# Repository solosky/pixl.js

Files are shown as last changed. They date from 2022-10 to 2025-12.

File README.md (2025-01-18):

# Pixl.js

这是一个基于原版[Pixl.js](http://www.espruino.com/Pixl.js)的复刻版本，主要的功能是用来模拟Amiibo。

## 图片

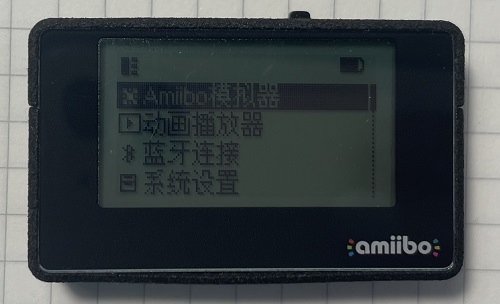
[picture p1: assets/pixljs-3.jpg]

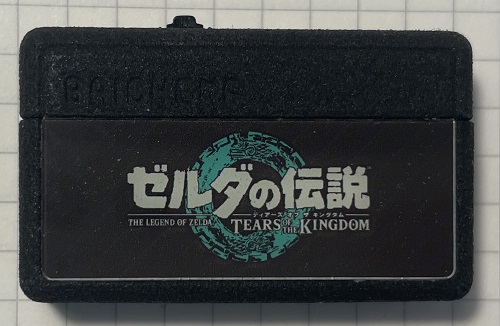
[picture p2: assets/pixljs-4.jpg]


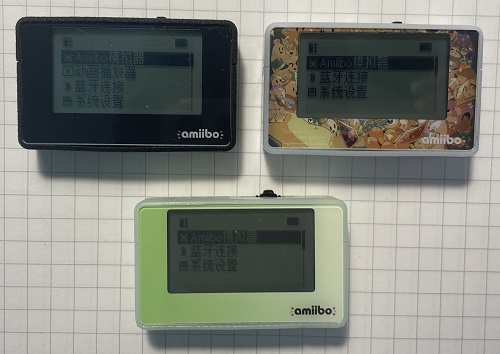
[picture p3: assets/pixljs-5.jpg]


## 文档

* [中文文档](docs/zh/README.md)
* [English Documentation](docs/en/README.md)
* [Italian Documentation](docs/it/README.md)

## Credits

* [FlipperZero Firmware](https://github.com/flipperdevices/flipperzero-firmware)
* [mlib](https://github.com/P-p-H-d/mlib)
* [TLSF](https://github.com/mattconte/tlsf)
* [cwalk](https://github.com/likle/cwalk)
* [SPIFFS](https://github.com/pellepl/spiffs)
* [ChameleonUltra](https://github.com/RfidResearchGroup/ChameleonUltra)
* [CH32V003-GameConsole](https://github.com/wagiminator/CH32V003-GameConsole)

## Contribution 

* 特别感谢 @Caleeeeeeeeeeeee 完善的Bootloader。
* 特别感谢 @白橙 制作的外壳。 
* 特别感谢 @impeeza 提供的文档翻译 。

## 讨论群

国内用户可以加入QQ群 109761876 进行交流。

## Office Channel

Where do you find the community?
* [Pixl.js community discord server](https://discord.gg/4mqeQwcAB2)

## 声明

本项目为开源项目，仅为学习研究用途，请勿用于商业用途。 <br />
Amiibo是任天堂的注册商标，NTAG21X为NXP的注册商标。

内置的Amiibo数据库来源分别如下：

* [amiiloop](https://download.amiloop.app/)
* [AmiiboAPI](https://www.amiiboapi.com/)

源代码没有包含任何有任天堂版权的资源（比如相关密钥，Amiibo原始数据等）。

# License

本项目基于GPL 2.0 License发布，使用请遵循License的约定。

* 如果对项目做了修改，需要把改后的源码发布出来
* 发布出来的源码必须要使用相同的License发布

## 提示 

Amiibo无限刷需要网上搜索key_retail.bin文件然后上传到到磁盘根目录后才能使用。

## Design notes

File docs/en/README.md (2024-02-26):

# **Welcome to the pixl.js project documentation !**

The pixl.jx project is a forked version of the original [Pixl.js](http://www.espruino.com/Pixl.js). The main focus of this fork is to simulate Amiibo.

This fork is divided in two main sections, Hardware and Firmware

# [Hardware](01-Hardware.md)

- [PCB](01-Hardware.md#PCB)
- [BOM](01-Hardware.md#BOM)
- [Pictures](01-Hardware.md#Pictures)
- [Demo](01-Hardware.md#Demo)
- [Shell](01-Hardware.md#Shell)
- [OLED version](01-Hardware.md#OLED-version) 

# Firmware 

- A guide to [Flash the Firmware](02-Flash-Firmware.md "Flash the Firmware")
- To help on the internationalization of the Firmware you can follow the [Guide](05+5-translation.md).
- [Building the firmware](03-Build-Firmware.md)
- [Using the firmware](04-Using-Firmware.md)

# [User Manual](04-Using-Firmware.md)

- [Concepts](04-Using-Firmware.md/#Firmware-Concepts)
- [Amiibo Emulator App](04-Using-Firmware.md/#Amiibo-Emulator)
- [Amiibo Database App](04-Using-Firmware.md/#Amiibo-Database)
- [AmiiboLink Emulator APP](04-Using-Firmware.md/#AmiiboLink)
- [Card Emulator APP](04-Using-Firmware.md/#CardEmulator)
- [BLE File Transfer APP](04-Using-Firmware.md/#BLE-File-Transfer)
- [Settings APP](04-Using-Firmware.md/#Settings-1)

# Technical Documentation

- [Bluetooth BLE File Transfer protocol](05+1-ble_protocol.md)
- [AmiiboLink BLE Protocol](05+2-amiibolink_ble.md)
- [video player](05+4-video_player.md) (Retired on Firmware 2.5.2 due to flash size restrictions)

# Tutorial

## iNFC

- [Pixl Firmware Upgrade Tutorial](https://www.youtube.com/watch?v=vldNVaoqJg0)

## MTools Lite

- [How to use card emulator on Pixl js OLED LCD](https://www.youtube.com/watch?v=KiuyfBKalhI)

# **key_retail.bin**

In order to use some features of the firmware you must to provide the «key_retail.bin» file. It should be uploaded to the root directory of the device storage before it can be used. You need to provide a legally acquired one, you can use a tool to extract it from your console (3DS or Switch).

>**key_retail.bin checksums:** <br/>
>MD5:	45fd53569f5765eef9c337bd5172f937 <br/>
>SHA1:	bbdbb49a917d14f7a997d327ba40d40c39e606ce<br/>

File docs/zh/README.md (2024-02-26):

# **Pixl.js文档**

# [硬件](01-Hardware.md)

- [PCB](01-Hardware.md#PCB)
- [BOM](01-Hardware.md#BOM)
- [图片](01-Hardware.md#Pictures)
- [演示](01-Hardware.md#Demo)
- [外壳](01-Hardware.md#Shell)
- [OLED版本](01-Hardware.md#OLED-version) 

# 固件

- [固件](02-Flash-Firmware.md "Flash the Firmware")
- [国际化](05+5-translation.md)
- [构建固件](03-Build-Firmware.md)

# [使用手册](04-Using-Firmware.md)

- [概念](04-Using-Firmware.md/#概念)
- [Amiibo模拟器](04-Using-Firmware.md/#Amiibo模拟器)
- [Amiibo数据库](04-Using-Firmware.md/#Amiibo数据库)
- [AmiiboLink](04-Using-Firmware.md/#AmiiboLink)
- [卡模拟器](04-Using-Firmware.md/#卡模拟器)
- [蓝牙传输](04-Using-Firmware.md/#蓝牙传输)
- [设置](04-Using-Firmware.md/#设置)

# 外壳

TODO

# 技术文档

- [蓝牙协议](05+1-ble_protocol.md)
- [AmiiboLink蓝牙协议](05+2-amiibolink_ble.md)
- [视频播放器](05+4-video_player.md) (由于固件大小限制，从固件版本2.6.2起，此功能已从固件中删除)

# key_retail.bin

为了使用固件的一些功能，您必须提供`key_retail.bin`文件，应在设备存储的根目录中上传，然后才能使用。 <br/>
您需要提供一个合法获得的文件，您可以使用工具从您的控制台（3DS 或 Switch）中提取它

>**key_retail.bin checksums:** <br/>
>MD5:	45fd53569f5765eef9c337bd5172f937 <br/>
>SHA1:	bbdbb49a917d14f7a997d327ba40d40c39e606ce

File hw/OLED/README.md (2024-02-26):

# OLED Version 

OLED version is contributed by @xiaohail under GPL 2.0 License, you can download hardware [here](https://gitlab.com/xiaohai/pixl.js)

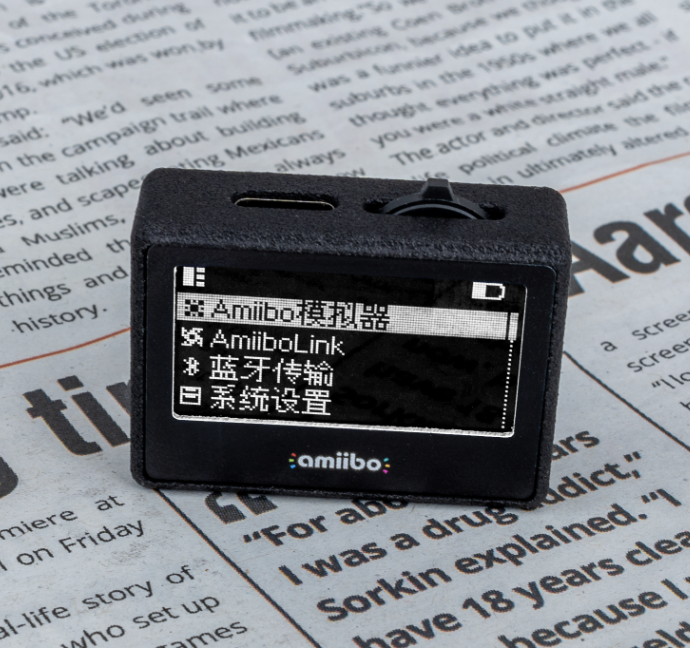
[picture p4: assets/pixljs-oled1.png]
OLED


## Improvement 

* Powered by lithium battery/USB power supply
* Supports OLED screen, LCD screen
* Hall sensor restart mechanism

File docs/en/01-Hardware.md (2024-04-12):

# PCB
The pixl.js hardware is developed and maintained on the repository, you can access the latest version of the hardware on [Hardware section of the GitHub repo.](https://github.com/solosky/pixl.js/tree/main/hw "Hardware section of the GitHub repo.")

hw/RevC is the latest PCB version, its recommended to use it.
You can use [Kicad 6](https://www.kicad.org/download/) to open and edit the PCB and Schematic files.

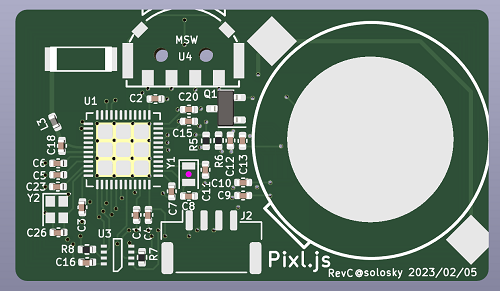
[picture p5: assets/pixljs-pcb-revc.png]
pixl.js PCB


# BOM
* The BoM is summaried on the doc: [RevC Bill of Materials Buying Guide](01+1-RevC-bom.md)
* The Bill of Materials in interactive format are also available, you can download it from: [RevC InteractiveHtmlBom](https://github.com/solosky/pixl.js/blob/main/docs/RevC-ibom.html)

# Pictures
Some pictures of current devices are:

pixl.js 1
pixl.js 2
pixl.js 3

# Demo

[The latest version of the Amiibo Emulator APP can generate random UUIDs allowing unlimited amiibo readings on game! This video is a example](https://www.bilibili.com/video/BV1TD4y1t76A/)

# Shell

A shell for this project, made by Mr. Baicheng can be downloaded [here](https://www.thingiverse.com/thing:5877482)
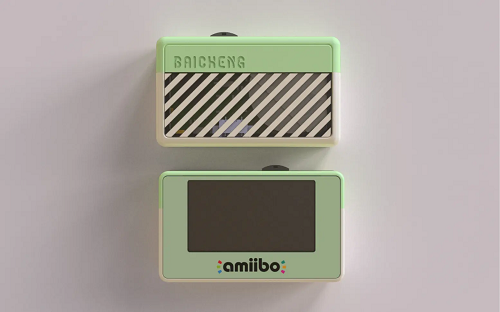
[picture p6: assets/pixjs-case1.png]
SHELL


# OLED version

The OLED version was contributed by netizen @xiaohail. You can click [here](https://gitlab.com/xiaohai/pixl.js) to download the PCB.

OLED

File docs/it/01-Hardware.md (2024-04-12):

# PCB
L'hardware di pixl.js è sviluppato e mantenuto nel repository, puoi accedere alla versione più recente dell'hardware nella [sezione Hardware del repository GitHub.](https://github.com/solosky/pixl.js/tree/main/hw "Sezione Hardware del repository GitHub.")

hw/RevC è la versione più recente del PCB, si consiglia di utilizzarla.
Puoi usare [Kicad 6](https://www.kicad.org/download/) per aprire e modificare i file del PCB e dello schema.

PCB pixl.js

# BOM
* Il BOM è riassunto nel documento: [Guida all'acquisto dei materiali di RevC](01+1-RevC-bom)
* La lista dei materiali  in formato interattivo sono disponibili, puoi scaricarli da: [RevC InteractiveHtmlBom](docs/RevC-ibom.html)

# Immagini
Alcune immagini dei dispositivi attuali sono:

pixl.js 1
pixl.js 2
pixl.js 3

# Demo

[L'ultima versione dell'applicazione Emulatore Amiibo può generare UUID casuali permettendo letture illimitate di amiibo sul gioco! Questo video è un esempio](https://www.bilibili.com/video/BV1TD4y1t76A/)

# Custodia

Una custodia per questo progetto, realizzata dal signor Baicheng, può essere scaricata [qui](https://www.thingiverse.com/thing:5877482)
CUSTODIA

# Versione OLED

La versione OLED è stata contribuita dall'utente @xiaohail. Puoi cliccare [qui](https://gitlab.com/xiaohai/pixl.js) per scaricare il PCB.

OLED

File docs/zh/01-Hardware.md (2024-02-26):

# PCB

hw/RevC 路径为最新的PCB版本，建议使用。您可以使用 [Kicad 6](https://www.kicad.org/download/) 打开和编辑PCB和原理图文件。

pixl.js PCB

# BOM
* 这里是已完成的BOM表: [RevC Bill of Materials Buying Guide](01+1-RevC-bom)
* 这里提供了交互格式的物料清单，您可以从此处下载： [RevC InteractiveHtmlBom](docs/RevC-ibom.html)

# 图片
以下为设备目前的一些图片:

pixl.js 1
pixl.js 2
pixl.js 3

# Demo

[以下视频介绍了Amiibo模拟器应用的最新版本，该功能可以生成随机UUID，允许在游戏中无限读取amiibo！](https://www.bilibili.com/video/BV1TD4y1t76A/)

# 外壳

你可以从 [这里](https://www.thingiverse.com/thing:5877482) 下载由@白橙 为此项目制作的外壳
shell

# OLED version

OLED版本由网友@xiaohail贡献。您可以点击 [这里](https://gitlab.com/xiaohai/pixl.js) 下载 PCB.

OLED

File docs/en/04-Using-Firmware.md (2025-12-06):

# Firmware Concepts
## Amiibo
Is a device sell by Nintendo, normally in form of a figurine, but also there are cards, wrist straps and others.

Each amiibo have a NFC tag embedded on the figurine base. The NFC tag have some data pre-record at factory identifying the type of figurine and making each amiibo unique of others.  The main data of the amiibo are:

As stated by Nintendo Amiibo is singular and plural (https://twitter.com/NintendoAmerica/status/535485751635763200)

## Model Info
Is a number which describe the amiibo series, game series, character and character variation, this info cannot be changed after first programming.

## UID
Is the serial number of the figurine is also hardcoded at factory making each amiibo unique.

## Amiibo Data
This section of the data on the tag store the user modifiable information like the Owner and Nickname registration or savegame data.

## UUID
The term UUID is used on the mod scene to reference the UID send to the game by a amiibo emulator, as the game uses the UID to know if a amiibo was already used; if the emulator changes the UID, the emulated amiibo looks like a completely different amiibo to the game, allowing to use that amiibo again.

## key_retail.bin
It's a binary file containing Nintendo private keys to encrypt amiibo, is copyrighted material so you need provide a legal acquired one, you can dump it form a 3DS or Switch Console.

## .BIN file
The data of an amiibo can be dumped to a file, that binary dump of the original content of an amiibo is stored on a file with `.BIN` extension, that dumps are uploaded to the device for the Amiibo Emulator application or the AmiiboLink Emulator application.  You need to provide a legally acquired binary dump file.

## Thumbwheel slide dial switch
Is the micro switch at top of the device, is a device having three buttons in one, a central one, and two sides.  Rocking the micro switch to sides you push that "**side**" buttons.  Pushing the micro switch you push the "**middle**" button.

On this document pressing the sides of Thumbwheel is named "**side buttons**", pushing the Thumbwheel is called "**middle button**"; to navigate items on a menu you use the side buttons, to select an item you press middle button.

# Using the Firmware
The Pixl.js firmware Main Screen is divided on several Applications, each one can be run to execute some actions, the applications on main screen are:

|   |
| ------------ |
|  Amiibo Emulator<br> Amiibo Database<br>֍ AmiiboLink<br>ᛡᛒ  BLE File Transfer<br> Settings |
|   |

----
# Amiibo Emulator
This application allows you to browse local storage for .BIN files and use them as the current amiibo.

You can browse folders and files using the thumbwheel slide dial switch, pushing to the sides you change elements, pushing the middle button you select the highlighted element.

Once you select a .BIN file his data is used like the current amiibo, the screen shows current amiibo details like amiibo current UUID, filename and amiibo name.

## Amiibo details screen
You can use side buttons to change the current amiibo with the next or previous one on the current folder.  
If the amiibo file is marked as read-only, an info icon will be displayed in front of the amiiboe file name line.

## Amiibo detail menu
Pressing the middle button you can change the behavior of the current amiibo, on the sub menu:

|   |
| ------------ |
| Rand. Tag<BR>Auto Rand.<BR>Delete Tag<BR>Back to Tag Details<BR>Back to File List<BR>Back to Main Menu<BR>Rand. Tag |
|   |

### Randomize Tag.
Changes the current UUID presented to game to current amiibo. The new UUID stays in place until you change the current amiibo or select this option again.
### Auto Rand. (Automatic Random)
Turning ON this feature, will generate a new random UUID for the current amiibo each time a game read it.  Allowing to use the same amiibo multiple times on games with restrictions.
### Read-only
Turning on this feature, any write operation to this tag will be denied. 
### Delete Tag
Delete the file associated to current amiibo.
### Back to Tag Details
Returns to the details of the current amiibo.
### Back to File List
Returns to the file list of current folder.
### Back to Main Menu
Exit the amiibo emulator application.

_If you enable UUID random generation, manually or automatic the original UUID of the .BIN file is used the next time that file is loaded._

## File explorer.
If you have **highlighted a folder or a file** and you press and hold the middle button for 1 second a properties sub menu is open:

|   |
| ------------ |
| Create New Folder…<BR>Create New Tag…<BR>Rename…<BR>Delete...<BR>Back to File List<BR>Back to Main Menu |
|   |

### Create New Folder…
Dialog to create a new sub folder on current one.
### Create New Tag…
Creates a blank amiibo .BIN file on the current folder.  That .BIN file is now a simil of a New Ntag215, ready to be programmed, you can assign that .BIN file as current amiibo and using a NFC programmer you can write the amiibo data, by example you can use iNFC or Tagmo for phones, Thenaya for the 3DS.  If the programmed amiibo is on the database the .BIN file is even renamed to the name of the amiibo.
### Rename…
Dialog to rename highlighted .BIN file or folder
### Delete…
Remove highlighted object, asking for confirmation.  If is a folder, all subfolders and files are deleted too.
### Back to File List
Returns to the file list of current folder.
### Back to Main Menu
Exit the amiibo emulator application.

----
# Amiibo Database
This application allows the emulation of amiibo from the list of well know ones, using legally available information like the model info, then when you select one, a new virtual amiibo is created on memory using a random UUID.  In order to use this application you must to provide your «key_retail.bin» file.

_Each time one an amiibo is used the initial UUID is random generated._

Once you open the application the main menu have the options

|   |
| ------------ |
| Browser…<BR>Search…<BR>My Favorites…<BR>My Amiibo…<BR>Settings… |
|   |

## Browser… 
Let you browse the database, first by category, then all amiibo on that category.
After you select an amiibo, the details are shown, the first line contains the actual UUID and second line the amiibo name.

On the amiibo details page you can use the side buttons to navigate through all the amiibo on the category, if you press the middle button you can change the behavior of the current amiibo, with the sub menu:

|   |
| ------------ |
| Rand. Tag<BR>Auto Rand.<BR>Favorite…<BR>Save As…<BR>[Back to Details]<BR>[Back to List]<BR>[Exit] |
|   |

### Rand. Tag
Randomize Tag, changes the current UUID presented to game to current amiibo. The new UUID stays in place until you change the current amiibo or select this option again.
### Auto Rand.
Automatic Random, Turning ON this feature, will generate a new random UUID for the current amiibo each time a game reads it.  Allowing to use the same amiibo multiple times on games with restrictions.
### Favorite…
Open a new submenu to manage Favorite folders.  You have the options:

```
New…
Folder1
Folder2
[Back]
```

**New…** allows you to create a new Favorites folder, **Back** go back to current amiibo details, if you select an existing folder, that amiibo definition will be added to selected folder.

### Save As…
Allows you to assign the current amiibo to one of the «My Amiibo» slots.
### [Back to Details]
Returns to the details of the current amiibo.
### [Back to List]
Returns to the amiibo list of current category.
### [Exit]
Exit the Amiibo Database application.

## Search…
Allows to search the database using partial name, the search result is like a category, you can select any amiibo on it and set it like another one.

## My Favorites…
Display the existent favorites folders, you can browse them with side buttons and select one with middle button.  If you press and Hold the middle button a sub menu is open:

|   |
| ------------ |
| New…<BR>Empty…<BR>Delete…<BR>[Back] |
|   |

### New…
Allows you to create a new favorites folder.
### Empty…
After confirmation, removes all amiibo associated to the selected folder.
### Delete…
After confirmation, removes the favorite folder.
### [Back]
Returns to Folder list.

Once you select a folder a list of the associated amiibo to that favorite folder is shown, you can browse using side buttons and select an amiibo with middle button, the selected amiibo becomes the current one, and behave like an amiibo of the browser.

## My Amiibo…
List the configured slots, you can browse the slots using side buttons, select one with middle button and the amiibo associated to that slot becomes the current one.

If you press and hold middle button a sub menu with the option of reset the slot is shown allowing to empty the slot.

If you turn on the Read-only feature, the current amiibo slot will denied write operation to this slot. An info icon will be displayed in front of the amiibo name if read-only feature is enabled.

## Settings…
The settings menu show you the Keys status and number of slot set up.

|   |
| ------------ |
| Keys []<BR>Slot Num. []<BR>[Back] |
|   |

### Keys []
Show the status of the «key_retail.bin» file, can be «Loaded» or «NOT Loaded»
### Slot Num. []
Allows to select how many slots are available to «My Amiibo» section, values from 10 to 50 on tenths increments.
### [Back]
Exit the Amiibo Database and returns to Main Menu.

----
# AmiiboLink
This application emulates an AmiiboLink (AmiLoop or omllbolink) device.

These devices are generic espruino boards sell on different forms, normally are Keychains drop shaped, but also there are some Puck or Sheika Slate shaped.

Almost all have a button and some LEDs as indicators and runs from CR2032 cell batteries or lipo cells.

All of them are controlled from phone applications via Bluetooth, also you can upload one or several .BIN amiibo files using the phone to the device.

Starting this application the details for current amiibo are shown.  If you are on sequential mode you can use the side buttons to walk through all the uploaded amiibo, in all modes, you can press the middle button to open the AmiiboLink APP config sub menu, the menu have this items:

|   |
| ------------ |
| Mode []<BR>Auto Random. []<BR>Compati. Mode []<BR>Tag Details<BR>[Main Menu] |
|   |

## Mode []
Shows the actual operation mode, when selected you can choose the mode of amiibo working, the available modes are:
- ### Randomize (Manual)
On the actual AmiiboLink device the current amiibo changes the UUID when you press the device button
- ### Randomize (Auto)
A new random UUID for the current amiibo is generated after each time a game read it.  Allowing to use the same amiibo multiple times on games with restrictions. You cannot change the active amiibo on this mode.
- ### Sequential mode
On this mode you can change the actual amiibo using the side buttons, rolling through all amiibo uploaded with the phone app. All uploaded .BIN files are stored on the 01.bin to 26.bin files at the /amiibolink/ folder.
- ### Read-write mode
The device use a "special" amiibo slot where only an amiibo can be used, the amiibo can be replaced by another .BIN file from the phone app. On the local storage this amiibo is saved with at the /amiibolink/99.bin file.

Changing the mode preserve the current selected amiibo, with exception of «Read-write mode».

## Compati. Mode []
Shows the emulation firmware mode, the supported values are V1, V2 and AmiLoop, there are several APPs each one designed for a AmiiboLink firmware version or to the AmiLoop protocol.  Using this setting you can match the emulation with the protocol needed by the APP you use on your phone.
## Tag Details
Return to amiibo details page
## [Main Menu]
Exit the AmiiboLink Emulator application.

## AmiiboLink Compatible Applications
So far the only two AmiiboLink/AmiLoop mode manager phone Apps are translated to English, they are "Umiibo" and "AmiLoop" this applications are compatible only with the AmiLoop Mode.

Other oddity is what the modes on applications do not correspond with the modes set up on the device.

| Umiibo APP | Pixl.js Emulation Mode |
| --- |--- |
| Manual Mode | Random automatic |
| File Mode | Sequential |
| Auto Mode | Read/Write |

| AmiiLoop APP | Pixl.js Emulation Mode |
| --- |--- |
| Manual Mode | Random automatic |
| File Mode | Sequential |
| Auto Mode | Read/Write |

# Card Emulator

This application can be used to emulate Mifare cards and NTAG series cards.

Mifare cards are commonly used for access control cards, and the device can fully emulate Mifare types of cards. Supported Mifare card types include:

* Mifare Mini
* Mifare 1K
* Mifare 2K
* Mifare 4K

NTAG series cards are commonly used for device identification. Supported NTAG card types include:

* NTAG 210
* NTAG 212
* NTAG 213
* NTAG 215
* NTAG 216
* Mifire Ultralight C
* Mifire Ultralight C
* Mifire Ultralight EV1(640 bits)
* Mifire Ultralight EV1(1312 bits)

Currently, a total of 8 cards are supported, with the option for customizing the number of cards in the future.

> Note:<br/>
> The emulation function of the NTAG series is still in testing, and the functionality is not yet complete. It does not fully emulate > the features of NTAG125. <br/>
> Further improvements to this part of the functionality will continue.

Emulation can only be activated in this interface, and it will be deactivated if you leave this interface.

After disk formatting or the first entry into the card emulator, data will be initialized. This process may take a few seconds, so please be patient.

## Card Emulation

The interface of the card emulation page is as follows:

|   |
| ------------ |
| [01] de:ad:be:ef|
|  |
| <    Slot 01      >|
|  |
| MF 1K <08/04 00>  |
|   |

The interface is explained as follows:

* The first line: `01` is the card number, and `de:ad:be:ef` is the card ID.
* The second line: Slot 01 is the name of the current card, which can be freely set.
* The third line: `MF 1K` displays the card type. The type abbreviations are shown in the table below. `08` is the card's SAK, `04 00` is the card's ATQA. The last symbol indicates the writing mode. If it is marked as a disk, writing is allowed; otherwise, writing is not allowed.
Abbreviations for card types:

| Display Name | Card Type | Data File Size |
| ---- | --- | --- |
| MF mini | Mifare Mini | 320 |
| MF 1k | Mifare 1K | 1024 |
| MF 2k | Mifare 2K | 2048 |
| MF 4k | Mifare 4K | 4096 |
| N210 | NTAG 210 | 80 |
| N212 | NTAG 212 | 164 |
| N213 | NTAG 213 | 180 |
| N215 | NTAG 215 | 540 |
| N216 | NTAG 216 | 924 |
| MFUL | Mifare Ultralight | 64 |
| MFULC | Mifare Ultralight C | 144 |
| MFEV11 | Mifare Ultralight EV1(640 bits) | 80 |
| MFEV21 | Mifare Ultralight EV1(1312 bits) | 164 |

* It will display a fav icon if the card is default card. The default card is the card that is automatically activated when the device is wakeup by NFC field presents.

# Main Menu

Pressing the middle button allows you to enter the main menu. As follows:

|   |
| ------------ |
|  Slot  [01]|
|  Nick [Slot 01]|
|  ID [de:ad:be:ef]|
|  Type [MiFare 1K] |
|  Data.. |
|  Advanced.. |
|  Slot Settings.. |
|  [Tag Details] |
|  [Main Menu] |
|   |

* Slot: Displays the current selected card slot. You can select a card slot by pressing the middle button.
* Nick: The current name of the card. Pressing the middle button can enter the card name setting interface.
* ID: Displays the current card ID.
* Type: Displays the current card type.
* Default Card: if enabled, the card will be automatically activated when the device is wakeup by NFC field presents. 
* Data: Pressing the middle button can manage card data.
* Advanced: Pressing the middle button can enter advanced card settings.
* Slot Settings: Pressing the middle button enters the slot management interface, where you can enable or disable card slots.
* [Tag Details]: Returns to the tag details page.
* [Main Menu]: Exits this application and enters the main menu.

> **Special Note:**：<br/>
> Some modifications need to be saved to storage when exiting to the tag details. If you have modified some configurations, be sure to enter the tag details page to save them.
> The default card feature is conflict with Fast Resume. If the default card feature is enabled, the device will active the card emulator of the default card instead of the amiibo Fast Resume feature.

## Nick Update

In this interface, you can modify the name of the card.

Due to limited display space, only English characters can be entered.

In particular, if using Chinese characters, due to UTF-8 encoding, deletion requires at least 2 presses to completely delete.

If you want to add Chinese notes to the card, you can modify the notes of `/chameleon/slots/00.bin` through the webpage to achieve Chinese notes.<br />
00.bin is the file for the first card slot, 01.bin is the file for the second card slot, and so on.

> Due to firmware size limitations, currently only around 1000 Chinese characters can be displayed properly. If Chinese characters are not displayed, please raise an issue with the characters you need to display. Specific characters can be added in the next version.

## Card Data

In this interface, you can perform the import and export of card data.

|   |
| ------------ |
|  Load.. |
|  Save.. |
|  Factory.. |
|   |

The import and export files are stored in the `/chameleon/dump/` folder.<br />
If you need to import data, you need to write the data file you want to import to the above folder through the webpage in advance.

* Load: Pressing the middle button allows you to enter the load interface. The interface will read all files under `/chameleon/dump/`, and pressing the middle button can perform the import.
* Save: Pressing the middle button allows you to export the current card to the `/chameleon/dump/` folder.
* Factory: Pressing the middle button allows you to reset the current card data to the default built-in empty card data.

> The file size loaded must be exactly the same as the current card type to be imported. The data file size for different cards refers to the table in the `Card Emulation`.

## Advanced

This interface displays different content based on MiFare series cards and NTAG series cards.

> **Special Note**:<br/>
> This interface is the advanced settings for card emulation, and it is not recommended for ordinary users to modify. If you intend to make changes, please make sure you understand what you are doing before modifying!<br/>
> If modifying this part leads to card emulation failure, try restoring default settings first.

### MiFare Series
|   |
| ------------ |
|  Custom Mode [OFF] |
|  ID [de:ad:be:ef]|
|  SAK [08] |
|  ATQA: [00 40]|
|  Gen1A Enabled [OFF] |
|  Gen2 Enabled [OFF] |
|  Write Mode [Normal] |
|  [RETURN] |
|   |

* Custom Mode: Default is off. Off: During the ID card recognition phase, ID/SAK/ATQA are read from sector 0 of the card data. On: You can set independent resources in the ID/SAK/ATQA menu below.
* ID: Displays the current card ID. If the custom mode is on, pressing the middle button allows you to enter the input interface for modification. If the custom mode is off, pressing the middle button has no effect.
* SAK: Displays the current card SAK. If the custom mode is on, pressing the middle button allows you to enter the input interface for modification. If the custom mode is off, pressing the middle button has no effect.
* ATQA: Displays the current card ATQA. If the custom mode is on, pressing the middle button allows you to enter the input interface for modification. If the custom mode is off, pressing the middle button has no effect.
* Gen1A Enabled: Default is off. When enabled, allows the emulator to respond to domestic advanced backdoor commands. These backdoor commands can directly unlock the card without the need for a key.
* Gen2 Enabled: Default is off. When enabled, allows writing to sector 0. (Sector 0 mainly stores information such as ID/SAK/ATQA, and allowing writing can modify the card's ID)
* Write Mode: Default is normal. There can be 4 values, see the table below.

|  Write Mode | Description |
| ----- | --- |
| Nromal | Data is written normally to memory, switch card or exit to persist |
| Deny | Any write operation returns failure |
| Ingore | Write operation returns success, but does not write to memory or persist |
| Cache | Data is written normally to memory, switching cards or exiting does not persist |

> It is recommended to enable Gen1A mode and Gen2 mode when copying cards, and close them after copying to avoid being recognized as a clone card by card readers.

### NTAG Series
|   |
| ------------ |
|  ID [04:68:95:71:fa:5c:64]|
|  SAK [00] |
|  ATQA: [00 44] |
|  Rand. UID |
|  [RETURN] |
|   |

* ID: Displays the current card ID. Not editable.
* SAK: Displays the current card SAK. Not editable.
* ATQA: Displays the current card ATQA. Not editable.
* Rand. UID: Pressing the middle button can randomly generate a new ID. Note that you need to return to the emulation interface to simulate and save the new card ID.

## Slot Settings

This interface displays the enable/disable status of all card slots and allows you to individually enable or disable each card slot.

|   |
| ------------ |
|  Slot Num.. [8]|
|  Slot 01   [ON] |
|  Slot 02   [OFF] |
|  .. |
|  [RETURN] |
|   |

* Slot Num: Displays the current number of card slots, which is default set to 8. Currently, the modification of the slot quantity is not supported, and it will be available in future firmware updates.
* Slot xx: Displays the open/close status of the card slot. Pressing the middle button can toggle between open and close status.

----
# Game
The device has 4 games that ported from https://github.com/wagiminator/CH32V003-GameConsole.
The 4 games are:

* Tiny Invaders
* Tiny Lander
* Tiny Tris
* Tiny Arkanoid

Long press center key to exit the game.

For more information about the games, please visit the [https://github.com/wagiminator/CH32V003-GameConsole](https://github.com/wagiminator/CH32V003-GameConsole "https://github.com/wagiminator/CH32V003-GameConsole.").

----
# BLE File Transfer
This application allows you to connect the iNFC or the pixl.js web page, to manage files on the device storage or update the firmware.

The official web page is [https://pixl.amiibo.xyz/](https://pixl.amiibo.xyz/ "https://pixl.amiibo.xyz/.").

The **iNFC APP** is a third party APP

Entering this mode the Bluetooth MAC address of device and official URL are shown at the screen.

----
# Settings
This application allows to configure the device working settings, the application have the next items on the menu:

|   |
| ------------ |
| Version []<BR>Language []<BR>Auto Storage []<BR>Backlight / OLED Contrast []<BR>Menu Animation []<BR>LiPO Battery []<BR>Memory Used []<BR>Fast Resume []<BR>Sleep Timer []<BR>Firmware Update<BR>System Reboot |
|   |

## Version
This submenu shows the version details of the firmware.
- Version
- Build date
- Githash
- Branch
- Target
- Dirty
## Language
You can change the language displayed on the device
## External Storage
You could view the external storage status and usage here, enter this menu could view the external storage usage details and perform format operation.
## Backlight / Contrast
With this setting you can control the brightness of the LCD screen or the contrast of the OLED screen.
## Menu Animation
Enable / disable the animation of items larger than screen allowing to read them completely, enabling this option increase the battery consumption.
## LiPO Battery
Enable the use of a LiPO battery.  It requires an hardware mod. If you build a LiPO version of Pixl.js device, you can enable this option. For CR2032 version, this option will not work and should not be enabled.

If you enable LiPO option, the device will use LiPO voltage level to display the battery level, and also can display a charge label when the battery is in charge mode.
## Memory Used
Shows the % used storage memory at the bottom of the screen
## Fast Wakeup
Enables hibernation of device, allowing a quicker response of the reading of the current amiibo by a game, and resume to the application open at the moment of sleep, when disabled the resume after sleep takes 1 second more and the device restore to the Main Menu.
## Sleep Timeout
Set the time when the device go to sleep after the last user input or amiibo read.
## App Management
Disable or enable app that shows on the Main Menu.
## Go Sleep
Manually put the device to sleep mode.
## Firmware Update
This option put the device in the DFU mode, allowing OTA firmware update, you can update the firmware using the iNFC or the web page.

You can go to the URL [https://thegecko.github.io/web-bluetooth-dfu/](https://thegecko.github.io/web-bluetooth-dfu/) to upload the firmware, this page also can be open through the official site [https://pixl.amiibo.xyz/](https://pixl.amiibo.xyz/)
## System Reboot
Allows you to reboot the device and get back to the state after you remove and put the battery.

## Reset Default Settings
Reset all settings to default values.

## About Device
Show Pixl.js project information, include source code repository, license.

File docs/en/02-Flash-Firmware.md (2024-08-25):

After you build the hardware you need to flash the firmware for the first time, that can only be achieved via wired method

The firmware can be flashed or upgraded using one of the follow methods:

## Method 1: Wired
This method requires a CMASS-DAP compatible JLink or DAPLink flasher.  We recommend PWLINK2 Lite Emulator STM32 Programmer, you can buy one for about 9.9 yuan on [Taobao](https://item.taobao.com/item.htm?spm=a1z09.2.0.0.4b942e8deXyaQO&id=675067753017&_u=d2p75qfn774a "Taobao")

Download the latest version of the firmware zip package. It should contain next files:
- fw_update.bat
- bootloader.hex
- pixljs.hex
- pixljs_all.hex
- fw_readme.txt
- pixjs_ota_v237.zip

You need to connect the 3.3 Volt, GND, SWDIO and SWDCLK leads.  you can use the file  `fw_update.bat` to flash the `pixjs_all.hex` firmware.

You can also use OpenOCD to flash the device, this is an example of the command to execute:
```
openocd -f interface/cmsis-dap.cfg -c "transport select swd" -f target/nrf52.cfg -d2 -c init -c "reset init" -c halt -c "nrf5 mass_erase" -c "program pixjs_all.hex verify" -c "program nrf52832_xxaa.hex verify" -c exit
```
After first flash is completed, subsequent firmware updates can be done via OTA.

## Method 2: OTA update
This method is only applicable to Pixl.js devices that have been successfully programed via wired method.

### nRF Connect APP
Install the nRF Connect application (you can find it on the both iOS and Android app stores).

On the Devices List, select pixl.js (or pixl dfu) and tap the button `CONNECT`

Put your pixl.js device on "Firmware Update" mode, then the device will enter DFU mode.  To do so, select the `Settings` app and select the item `Firmware Update`.

Open "nRF Connect" app on your phone and connect to the device named `pixl dfu` to update the firmware.

On iOS, The firmware is `pixjs_ota_vxxx.zip` in the compressed package and needs to be shared with the nrfconnect application through WeChat or QQ.

On Android you can use the DFU icon on the upper right of the screen, Select the `Distribution packet (ZIP)` option and browse your storage for the `pixjs_ota_vxxx.zip` file.

### Web page method
Download the latest version of the firmware zip package correspondent to your device version, and extract it to a directory.

The project provide two ways to achive a DFU update:

#### File Transfer Web Page.
First you can connect the device to [official web page](https://pixl.amiibo.xyz/ "official web page") then on the web page, after the device is connected, press the `DFU` grey button, the device will enter on the DFU mode and the page ask you "Do you want to open the DFU upgrade page?" if you accept the Firmware Update Page will be open.

#### Directly to the Firmware Update Page.
Also you can go directly to the Firmware Update Page.

First you need to put your pixl.js device on "Firmware Update" mode.  To do so, select the `Settings` app and select the item `Firmware Update`.

Open the [firmware update page](https://thegecko.github.io/web-bluetooth-dfu).  Drag and drop or select `pixljs_ota_xxx.zip` file from the folder where you extract the firmware package.

Then press the `SELECT DEVICE` button on the page you should see a device called `pixl dfu` connect to start the firmware upgrade process.

# Repair wrong firmware version.

If by mistake you program the wrong version (LCD/OLED) on your device, the device will work but will no show information on screen, the backlight of the LCD version could turn on.

You can use following methods to recover or flash the correct firmware version.

## Option 1: Flash the firmware via wired connection

If you have any CMASS-DAP compatible JLink or DAPLink programer on hand, you can use the [Wired Method](Flash-Firmware#Method 1: Wired "Wired Method") to flash the correct firmware version manually.

## Option 2: Follow special key sequences to enter the DFU mode again to flash correct firmware version.

First make sure your device is in off state, then press key sequences bellow to enter into the `DFU Mode`

- Any key to wake up the device
- LEFT
- MIDDLE
- LEFT X N 
- MIDDLE

If the firmware version before 2.11.x, press LEFT x 4
If the firmware version after 2.11.x, press LEFT x 5

Now you device is on DFU mode, use any of the [nRF Connect APP](#nRF-Connect-APP)  or [Directly to the Firmware Update Page](#directly-to-the-firmware-update-page) methods to upgrade the fimware.

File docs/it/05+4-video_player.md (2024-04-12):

Certo, ecco la traduzione in italiano:

# Lettore di animazioni

Il lettore di animazioni può riprodurre file di animazione convertiti in formati personalizzati. Richiede la versione del firmware 2.3.0 o superiore.

## Formato del file di animazione

Il formato di base del file è intestazione + frame1 + frame2 +... + frameN

     # magic + frame_count + fps + width + height + reserved
     # 4b + 2b + 2b + 2b + 2b + 4b = 16 byte

Il formato dell'intestazione è il seguente

| Nome del campo | Tipo | Lunghezza (byte) | Descrizione |
| ---- | ----- |---- | ---- |
| magic | bytes | 4 | Prefisso fisso, utilizzato per determinare rapidamente se è un file di animazione, fisso a 0x56 0x58 0x49 0x50 |
| conteggio frame | uint16 | 2 | Quanti frame di animazione ci sono in totale |
| fps | uint16 | 2 | Quanti frame di animazione al secondo |
| larghezza | uint16 | 2 | larghezza dell'animazione |
| altezza | uint16 | 2 | altezza dell'animazione |
| riservato | uint32 | 4 | byte riservati |

Il formato dei dati del frame N è i dati di animazione di ogni frame in formato xbm, e la dimensione è larghezza * altezza / 8.
Se la lunghezza della larghezza non è un multiplo di 8, arrotonda per eccesso.

## Come generare file di animazione

Prima prepara il file video che deve essere convertito, di solito termina in mp4, ma sono accettabili anche altri formati.

Le seguenti operazioni devono essere eseguite sotto Linux.
Inoltre, puoi utilizzare WSL2 per creare rapidamente un ambiente Linux Ubuntu sotto Windows.

Esegui prima il seguente comando per installare gli strumenti necessari

```
sudo apt install ffmpeg python3-pip
sudo pip3 install imageio -i https://pypi.tuna.tsinghua.edu.cn/simple
```

Per Ubuntu avrai bisogno di installare i pacchetti eseguendo il prossimo comando:

```
sudo apt install ffmpeg python3 python3-imageio
```

Se preferisci l'ambiente MSYS MINGW64 puoi installare i pacchetti utilizzando questi comandi:

```
pacman -S mingw-w64-x86_64-ffmpeg mingw-w64-x86_64-python mingw-w64-x86_64-python-imageio
```

Quindi esegui il comando ffmpeg per convertire l'animazione in immagini di frame indipendenti.
```
mkdir frames
ffmpeg -y -i badapple.mp4 -ss 0:0 -t 60 -vf "scale=128:64:decrease:flags=lanczos,hue=s=0" -r 10 "frames/%04d.bmp"
```
La descrizione del parametro è la seguente:

* -i badapple.mp4: Questo è il file video di input
* -ss 0:0: intercetta da 0:0 del video. Se non vuoi intercettare parte del video, non hai bisogno di fornire questo parametro.
* -t 60: intercetta 60 secondi di video. Se converti l'intero video, non hai bisogno di fornire questo parametro.
* -vf "scale=128:64:decrease:flags=lanczos,hue=s=0" : Converti il video in un'immagine 128x64, mantenendo l'aspect ratio del video
* -r 10: L'fps convertito è 10
* "frames/%04d.bmp": I file video convertiti sono memorizzati nella directory frames e il formato è bmp

Se il video è più grande, puoi ridurre le dimensioni del video come segue:

* Dato i parametri -ss -t, intercetta parte del video
* Riduci la risoluzione di output, come 80x64, ecc.

Infine, esegui il seguente comando per convertirlo in un file di animazione personalizzato

```
python3 fw/scripts/video_clip_gen.py 10 frames badapple.bin
```
La descrizione del parametro è la seguente:

* 10: L'fps convertito è 10, ad esempio, è lo stesso dell'fps convertito da ffmpeg, altrimenti la velocità di riproduzione sarà errata.
* frames: directory delle immagini convertite da ffmpeg
* badapple.bin: file di animazione convertito

## Riproduci file di animazione

Trasferisci i file video convertiti nella directory del lettore dello storage Flash in Pixl.js tramite la pagina web. La directory del lettore non può essere creata manualmente.

Apri Pixl.js, seleziona [Animation Player], elenca tutti i file nella directory del lettore, quindi seleziona il file video che vuoi riprodurre e premi il pulsante centrale per riprodurre.

Avviso:

* Sebbene lo storage Flash sia uno spazio di 1,8 MB, a causa delle caratteristiche del file system SPIFFS, quando lo spazio disponibile è inferiore al 30%, la scrittura sarà molto lenta o addirittura fallirà.
* Se incontri una scrittura lenta, puoi ripristinare la velocità di caricamento formattando il disco.
* La cancellazione di file di grandi dimensioni è lenta, per favore sii paziente.

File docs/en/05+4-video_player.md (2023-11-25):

# animation player

The animation player can play converted animation files in custom formats. Requires firmware version 2.3.0 or higher.

## Animation file format

The basic format of the file is header + frame1 + frame2 +... + frameN

     # magic + frame_count + fps + width + height + reserved
     # 4b + 2b + 2b + 2b + 2b + 4b = 16 bytes

The header format is as follows

| Field name | Type | Length (bytes) | Description |
| ---- | ----- |---- | ---- |
| magic | bytes | 4 | Fixed prefix, used to quickly determine whether it is an animation file, fixed to 0x56 0x58 0x49 0x50 |
| frame count | uint16 | 2 | How many frames of animation are there in total |
| fps | uint16 | 2 | How many frames of animation per second |
| width | uint16 | 2 | animation width |
| height | uint16 | 2 | animation height |
| reserved | uint32 | 4 | reserved bytes |

The data format of frame N is the animation data of each frame in xbm format, and the size is width * height / 8.
If the length of width is not a multiple of 8, round it up.

## How to generate animation files

First prepare the video file that needs to be converted, usually ending in mp4, but other formats are also acceptable.

The following operations need to be run under Linux.
Also you can use WSL2 to quickly create an Ubuntu Linux environment under Windows.

First execute the following command to install the necessary tools

```
sudo apt install ffmpeg python3-pip
sudo pip3 install imageio -i https://pypi.tuna.tsinghua.edu.cn/simple
```

For Ubuntu you will need to install packages running the next command:

```
sudo apt install ffmpeg python3 python3-imageio
```

If you preffer the MSYS MINGW64 environment you can install the packages using this commands:

```
pacman -S mingw-w64-x86_64-ffmpeg mingw-w64-x86_64-python mingw-w64-x86_64-python-imageio
```

Then execute the ffmpeg command to convert the animation into independent frame pictures.
```
mkdir frames
ffmpeg -y -i badapple.mp4 -ss 0:0 -t 60 -vf "scale=128:64:decrease:flags=lanczos,hue=s=0" -r 10 "frames/%04d.bmp"
```
Parameter description is as follows:

* -i badapple.mp4: This is the input video file
* -ss 0:0: intercept from 0:0 of the video. If you do not want to intercept part of the video, you do not need to provide this parameter.
* -t 60: intercept 60 seconds of video. If you convert the entire video, you do not need to provide this parameter.
* -vf "scale=128:64:decrease:flags=lanczos,hue=s=0" : Convert the video to a 128x64 image, retaining the aspect ratio of the video
* -r 10: The converted fps is 10
* "frames/%04d.bmp": The converted video files are stored in the frames directory and the format is bmp

If the video is larger, you can reduce the video size as follows:

* Given the -ss -t parameters, intercept part of the video
* Reduce the output resolution, such as 80x64, etc.

Finally, execute the following command to convert it to a customized animation file

```
python3 fw/scripts/video_clip_gen.py 10 frames badapple.bin
```
Parameter description is as follows:

* 10: The converted fps is 10, for example, it is the same as the fps converted by ffmpeg, otherwise the playback speed will be incorrect.
* frames: directory of pictures converted by ffmpeg
* badapple.bin: converted animation file

## Play animation files

Transfer the converted video files to the player directory of Flash storage in Pixl.js through the web page. The player directory cannot be created manually.

Open Pixl.js, select [Animation Player], list all the files in the player directory, then select the video file you want to play, and press the middle button to play.

Notice:

* Although the Flash storage is 1.8MB of space, due to the characteristics of the SPIFFS file system, when the available space is less than 30%, writing will be very slow or even fail.
* If you encounter slow writing, you can restore upload speed by formatting the disk.
* Deleting large files it is slow, please be patient.

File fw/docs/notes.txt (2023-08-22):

NFC antenna match cap

//110pF: 16.9MHz 
//150pf: 14.8MHz
//180pF: 14.35MHz

Power consumption

LCD OFF, SYS OFF: 0.9uA
LCD ON, SYS OFF: 107.3uA
LCD ON, SYS WFE: 562uA

LCD ON, BL ON, SYS OFF: 6.04mA

//flash region 
//start_addr, length 
0, 0x26000: MBR + SD  (152KB)
0x26000, 0x5a000: app (360KB)

//new
0, 0x19000: MBR + SD  (100KB)
0x19000, 0x50000: app (320KB)
0x69000, 0x7000: fs (52KB)
0x76000, 0xa000: bl + param (40KB)

//new2
0, 0x19000: MBR + SD  (100KB)
0x19000, 0x5D000: app (372KB)
0x76000, 0xa000: bl + param (40KB)

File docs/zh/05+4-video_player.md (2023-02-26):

# 动画播放器

动画播放器可以播放转换后的自定义格式的动画文件。需要固件版本为2.3.0或更高版本。

## 动画文件格式 

文件的基本格式为 header + frame1 + frame2 +... + frameN

    # magic + frame_count + fps + width + height + reserved
    # 4b + 2b + 2b + 2b + 2b + 4b = 16 bytes

其中Header格式如下 

| 字段名 | 类型 | 长度(字节) | 说明 |
| ---- | ----- |---- | ---- |
| magic  | bytes | 4  |  固定的前缀，用于快速判断是否是动画文件，固定为 0x56 0x58 0x49 0x50 |
| frame count | uint16 | 2 | 总共有多少帧动画 |
| fps | uint16 | 2 | 每秒有多少帧动画 | 
| width | uint16 | 2 | 动画宽度 |
| height | uint16 | 2 | 动画高度 |
| reserved | uint32 | 4 | 保留字节 |

其中frame N的数据格式为xbm格式的动画每帧数据，大小为 width * height / 8。
其中如果width的长度不是8的倍数，向上去整。

## 如何生成动画文件

首先准备好需要转换的视频文件，通常是mp4结尾，其他格式也可以。

以下操作需要在linux下面运行，否则会报错。
如果没有linux环境，可以使用WSL2来快速创建一个ubuntu的linux环境。

首先执行如下命令安装必须的工具 

```
sudo apt install ffmpeg python3-pip
sudo pip3 install imageio -i https://pypi.tuna.tsinghua.edu.cn/simple
```

然后执行ffmpeg命令，转换动画为独立的帧图片。
```
ffmpeg -y -i badapple.mp4 -ss 0:0 -t 60 -vf "scale=128:64:decrease:flags=lanczos,hue=s=0" -r 10 "frames/%04d.bmp"
```
参数说明如下：

* -i badapple.mp4 : 这是输入视频文件
* -ss 0:0 : 从视频的0:0开始截取，如果不截取部分视频，可以不提供这个参数
* -t 60 : 截取60秒视频，如果转换整个视频，可以不提供这个参数 
* -vf "scale=128:64:decrease:flags=lanczos,hue=s=0" : 转换视频为128x64的图片，保留视频的宽高比
* -r 10 : 转换后的fps为10
* "frames/%04d.bmp" : 转换的视频文件存放在 frames目录下，格式为bmp

如果视频较大，可以通过如下方式减小视频大小：

* 给定 -ss -t 参数截取部分视频
* 减少输出的分辨率，比如80x64等

最后执行如下命令转换为 自定义的动画文件 

```
python3 fw/scripts/video_clip_gen.py 10 frames badapple.bin 
```
参数说明如下：

* 10 : 转换后的fps为10，比如和ffmpeg转换的fps一样，不然播放速度不正确
* frames : ffmpeg转换的图片目录
* badapple.bin : 转换后的动画文件

## 播放动画文件

把转换后的视频文件通过网页传输到Pixl.js的Flash存储的 player 目录下，player目录没有可以手动创建。

打开Pixl.js，选择【动画播放器】，列出player目录下的所有文件，然后选择要播放的视频文件，按中键播放。

注意：

* 虽然Flash存储是1.8MB的空间，但是由于SPIFFS文件系统的特性，当可用的空间低于30%的时候写入就会很慢，甚至写入失败。 <br />
  如果遇到写入很慢的情况，可以通过格式化磁盘来恢复上传速度。
* 当删除大文件的时候比较慢，请耐心等待。

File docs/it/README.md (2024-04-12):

# Pixl.js

Fork progetto originale [Pixl.js](http://www.espruino.com/Pixl.js)

Il progetto mira principalmente ad utilizzare il dispositivo Pixl.js come emulatore tag nfc per gli Amiibo.

Immagini






## Documentazione

* [中文文档](docs/zh/README.md)
* [English Documentation](docs/en/README.md)

## Crediti

* [FlipperZero Firmware](https://github.com/flipperdevices/flipperzero-firmware)
* [mlib](https://github.com/P-p-H-d/mlib)
* [TLSF](https://github.com/mattconte/tlsf)
* [cwalk](https://github.com/likle/cwalk)
* [SPIFFS](https://github.com/pellepl/spiffs)
* [ChameleonUltra](https://github.com/RfidResearchGroup/ChameleonUltra)

## Contribution 

* 特别感谢 @Caleeeeeeeeeeeee 完善的Bootloader。
* 特别感谢 @白橙 制作的外壳。 
* 特别感谢 @impeeza 提供的文档翻译 。

## Office Channel

Where do you find the community?
* [Pixl.js community discord server](https://discord.gg/4mqeQwcAB2)

## Desclaimer
Questo progetto è un progetto open source ed è destinato esclusivamente a scopi di apprendimento e ricerca. Si prega di non utilizzarlo per scopi commerciali. <br />
Amiibo è un marchio registrato di Nintendo e NTAG21X è un marchio registrato di NXP.

Le fonti del database Amiibo integrato sono le seguenti:

* [amiiloop](https://download.amiloop.app/)
* [AmiiboAPI](https://www.amiiboapi.com/)

Il codice sorgente non contiene risorse protette da copyright di Nintendo (come chiavi correlate, dati originali degli Amiibo, ecc.).

# License

本项目基于GPL 2.0 License发布，使用请遵循License的约定。

* 如果对项目做了修改，需要把改后的源码发布出来
* 发布出来的源码必须要使用相同的License发布

# License

This project is released based on the GPL 2.0 License. Please follow the terms of the License when using it.

* If modifications are made to the project, the modified source code needs to be released
* The source code released must be released using the same License

## suggerimento 
L'utilizzo illimitato di uno stesso Amiibo più volte al giorno (per esempio su Zelda btow) richiede la ricerca del file key_retail.bin online e il caricamento nella cartella principale del disco prima di poter essere utilizzato.

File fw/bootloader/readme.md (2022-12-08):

### bootloader

#### build:
```
make privgen # 保存好priv.pem文件
make
```

#### init:

编译好application和bootloader
```
make settingsgen  # app.hex为你的app程序
```

### update zip:
app_new.hex 为新的固件程序
--application-version需要递增
--hw-version固定52，如更新bl请与bl中数值保持一致
--sd-req固定为0x0103，如更新softdevice请查看对应版本发行说明
nrfutil pkg generate --application app_new.hex --application-version 2 --hw-version 52 --sd-req 0x0103 --key-file priv.pem appv2_sd112.zip

#### dfu:
移除电池，按住按钮安装电池，此时搜索蓝牙出现名为pixl dfu的设备，使用nrf connect连接
点击dfu按钮，选择更新压缩包，等待传输完成，led灯会亮
升级完成后设备会自动跳转到程序执行
注意：如果发生莫名其妙的中断请更换新电池保证电压稳定

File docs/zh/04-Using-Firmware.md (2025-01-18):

# 概念
## Amiibo

Amiibo是任天堂销售的游戏周边，通常呈现为一个游戏角色的手办，但也包括卡片、手腕带等其他形式。

每个Amiibo都在手办底座上嵌入了一个NFC标签。NFC标签在工厂预先记录了一些数据，用于识别手办的类型，使每个Amiibo与其他不同。
在一些游戏中（特别是任天堂发布的一方游戏）扫描NFC标签可以获得游戏中的道具等。

## Model Info
这是一个数字，用于描述Amiibo系列、游戏系列、角色和角色变体，此信息在首次编程后无法更改。

## Amiibo ID
用于识别Amiibo手办，手办序列号也是在工厂硬编码的，使得每一种手办都有自己的编号，且能通过Amiibo ID识别是哪一种手办。

## Amiibo Data
标签上的数据的这一部分存储了用户可修改的信息，如所有者和昵称的注册信息或游戏存档数据。

## NTAG215
NTAG215是NXP公司出售的一种NFC卡片，可以用来存储数据在卡片上。使用NFC读卡器可以读取或者写入NTAG215里面的数据。

Amiibo就是使用NTAG215卡片存储数据的。

## UID
为NTG215卡片的卡号。每个NTAG215都有一个7个字节的唯一的卡号。

在修改场景中，术语UID用于引用由Amiibo模拟器发送给游戏的UID，因为游戏使用UID来判断是否已经使用了Amiibo。如果模拟器更改了UID，模拟的Amiibo在游戏中看起来就像是完全不同的Amiibo，从而允许再次使用该Amiibo。

## key_retail.bin
这是一个包含任天堂用于加密Amiibo的私钥的二进制文件，是受版权保护的材料，因此您需要提供一个合法获取的文件，您可以从3DS或Switch主机中导出它。

## .BIN file
Amiibo的数据可以被导出到一个文件，该文件以.BIN扩展名存储了Amiibo原始内容的二进制转储。这些转储文件被上传到设备上供Amiibo模拟器应用程序或AmiiboLink模拟器应用程序使用。您需要提供一个合法获取的二进制转储文件。

通常大小是540字节，但是有些文件可能是不太常见的532字节或者572字节，但是`Amiibo模拟器`应用都能很好的使用。

## 多功能按钮
这是设备顶部的微型开关，是一个具有三个按钮的设备，一个“**中键**“和两个“**侧边**”按钮。将微型开关推向两侧会按下“侧边”按钮。按下微型开关时，会按下“中间”按钮。

在本文档中，按下多功能按钮的两侧被称为“**左键**”和”**右键**“，按下多功能按钮被称为“**中键**”；在菜单中导航项目时，使用侧面按钮，要选择一个项目，请按下”中间“按钮。长按”**中键**“超过1秒钟可以进入上下文菜单。

# 使用固件

Pixl.js固件的主屏幕分为几个应用程序，每个应用程序都可以运行以执行一些操作，主屏幕上的应用程序包括：

|   |
| ------------ |
|  Amiibo模拟器|
|  Amiibo数据库|
| ֍ AmiiboLink|
|  卡模拟器 |
| ᛡᛒ 文件传输 |
|  Settings |
|   |

----
# Amiibo模拟器

这个应用程序允许您浏览本地存储中的 .BIN 文件，并将它们用作当前的Amiibo。

您可以使用拇指滑轮滑动开关浏览文件夹和文件，推动到两侧可以更改元素，按下中间按钮可以选择突出显示的元素。

一旦选择了一个 .BIN 文件，其数据就会被用作当前的Amiibo，屏幕显示当前Amiibo的详细信息，如Amiibo当前UUID、文件名和Amiibo名称。

## Amiibo详情

您可以使用侧面按钮在当前文件夹中切换到下一个或上一个Amiibo。按下中间按钮，您可以更改当前Amiibo的行为，在子菜单中：

|   |
| ------------ |
| 随机生成 |
| 自动随机生成 [开] |
| 删除标签 | 
| 返回详情 |
| 返回文件列表 |
| 返回主菜单 |
|   |

* 随机生成：更改呈现给游戏的当前Amiibo的UID。新的UID会保持不变，直到您更改当前Amiibo或再次选择此选项。
* 自动随机生成：打开此功能将为当前Amiibo生成一个新的随机UID，每次游戏读取它时都会生成一个新的UID。这允许在具有限制的游戏中多次使用同一Amiibo。
* 删除标签：删除当前显示的标签
* 返回详情：返回当前详情页
* 返回文件列表：返回文件列表
* 返回主菜单：退出应用返回主菜单

_如果启用UID的随机生成（无论是手动还是自动），则在下一次加载该文件时将使用该文件的原始UID。_

## 文件浏览器

如果选择了一个文件，长按中键可以进入文件菜单。

|   |
| ------------ |
| 新建文件夹..|
| 新建标签.. |
| 批量创建标签.. |
| 重命名.. |
| 删除.. |
| 返回文件列表|
| 返回主菜单 |

### 新建文件夹
显示一个对话框输入文件夹名字在当前文件夹创建一个子文件夹。
### 新建标签..
在当前文件夹中创建一个空的Amiibo BIN文件。该.BIN文件现在类似于一个新的Ntag215，准备好被编程，您可以将该.BIN文件分配为当前Amiibo，并使用NFC编程器写入Amiibo数据，例如您可以使用手机上的iNFC或Tagmo，或者在3DS上使用Thenaya。如果编程的Amiibo在数据库中，.BIN文件甚至会被重命名为Amiibo的名称。
### 批量创建标签
在当前文件夹批量创建空的Amiibo BIN文件，点击之后会提示输入创建数量，创建amiibo的文件名为newXX.bin, XX为序号。
### 重命名
重命名选中的文件夹或者文件名。
### 删除
删除选中文件或者文件夹。如果是文件夹，则所有子文件夹和文件都会被删除。
### 返回文件列表
返回文件列表。
### 返回主菜单
退出应用返回主菜单。

> 从2.9.0开始，存储管理移入了设置菜单中。

----
# Amiibo数据库

TODO

----
# AmiiboLink

TODO

----
# 蓝牙传输

这个应用程序允许您连接iNFC或pixl.js网页，以管理设备存储上的文件或更新固件。

官方网页是 [https://pixl.amiibo.xyz/](https://pixl.amiibo.xyz/ "https://pixl.amiibo.xyz/.").

iNFC APP 是一个第三方应用程序。

进入此模式后，设备的蓝牙MAC地址和官方URL会显示在屏幕上。

也可以按左键或者右键展示二维码，用手机扫码即可快速打开网页。不过很遗憾，大部分手机都不支持通过浏览器连接蓝牙设备。

----

# 卡模拟器

这个应用可以用来模拟Mifare卡片和NTAG系列卡片。

Mifare卡片常见用于门禁卡，设备可以支持完整模拟Mifare类型的卡片。支持Mifare卡片类型有：

* Mifare Mini
* Mifare 1K
* Mifare 2K
* Mifare 4K

NTAG系列卡片常用于设备识别。支持的NTAG卡片类型有：

* NTAG 210
* NTAG 212
* NTAG 213
* NTAG 215
* NTAG 216
* Mifire Ultralight C
* Mifire Ultralight C
* Mifire Ultralight EV1(640 bits)
* Mifire Ultralight EV1(1312 bits)

目前总共支持存储8张卡片，后续开放自定义卡片数量。

> **注意**：<br/> 
NTAG系列的模拟功能还是测试中，功能还不太完善，未完全模拟NTAG125的特性。 <br />
>后续会持续完善这一部分的功能。

只有在此界面才开启模拟功能，如果离开这个界面就会关闭模拟。

在磁盘格式化后或者第一次进入卡模拟器会初始化数据，这个过程可能需要几秒钟，请稍微等待下。

## 模拟卡界面

模拟页面的界面如下：

|   |
| ------------ |
| [01] de:ad:be:ef|
|  |
| <    卡槽 01      >|
|  |
| MF 1K <08/04 00>  |
|   |

界面说明如下：
* 第一行：`01` 是卡片序号，`de:ad:be:ef`是卡号。
* 第二行：`卡槽 01`是当前卡的名字，可以自由设置
* 第三行：`MF 1K` 显示了卡类型，类型简写见下表，`08`是卡的SAK，`04 00`是卡的ATQA 最后一个符号是写入模式，如果是存储类型标记，则允许写入，否则不允许写入。如果当前卡片设置了默认卡片，设备会展示一个收藏图标作为提示。

| 显示 | 类型 | 数据文件大小 |
| ---- | --- | --- |
| MF mini | Mifare Mini | 320 |
| MF 1k | Mifare 1K | 1024 |
| MF 2k | Mifare 2K | 2048 |
| MF 4k | Mifare 4K | 4096 |
| N210 | NTAG 210 | 80 |
| N212 | NTAG 212 | 164 |
| N213 | NTAG 213 | 180 |
| N215 | NTAG 215 | 540 |
| N216 | NTAG 216 | 924 |
| MFUL | Mifare Ultralight | 64 |
| MFULC | Mifare Ultralight C | 144 |
| MFEV11 | Mifare Ultralight EV1(640 bits) | 80 |
| MFEV21 | Mifare Ultralight EV1(1312 bits) | 164 |

# 主菜单

按中键可以进入主菜单。如下：
|   |
| ------------ |
|  卡槽  [01]|
|  卡名 [卡槽 01]|
|  ID [de:ad:be:ef]|
|  卡类型 [MiFare 1K] |
|  默认卡片 [开] ｜
|  卡数据.. |
|  卡高级设置.. |
|  卡槽管理.. |
|  [标签详情] |
|  [主菜单] |
|   |

* 卡槽: 显示了当前显示的卡槽，可以按中键选择卡槽
* 卡名：卡当前的名字，按中键可以进入设置卡名界面
* ID：显示了当前卡ID
* 卡类型：显示了当前卡类型
* 默认卡片：如果开启默认卡片，当设备从NFC场唤醒时，默认模拟这张卡。
* 卡数据：按中键可以进行卡数据管理
* 卡高级设置：按中键可以进入卡高级设置
* 卡槽管理：按中键进入卡槽管理界面，可以开启关闭卡槽
* [标签详情]：返回标签详情页面
* [主菜单]：退出此应用，进入主菜单

> **特别注意**：<br/>
> 部分的修改需要在退出到标签详情才会保存到存储，如果修改了部分配置，请务必进入到标签详情页面保存下。
> 如果开启的默认卡片功能，当设备从NFC场唤醒时，会调用卡模拟器应用，默认模拟这张卡。此功能和快速唤醒功能冲突，如果设置了默认卡，快速唤醒功能不再生效。

## 卡名修改

在此界面可以修改卡的名字。

由于显示区域有限，只能输入英文字符。

特别的，如果是中文字符，由于utf8编码的原因，删除请至少按2次才能完全删除。

如果想给卡片写中文备注，可以通过网页修改 `/chameleon/slots/00.bin`的备注来实现中文备注。<br />
00.bin为第一个卡槽文件，01.bin为第二个卡槽文件以此类推。

> 由于固件大小限制，目前仅有1000个左右的中文字符可以正常显示，如果输入中文没有显示，请提issue写上需要显示的字符，下一个版本可以加上特定的字符。

## 卡数据

在此界面可以执行卡片数据的导入导出。
|   |
| ------------ |
|  加载.. |
|  导出.. |
|  重置.. |
|   |

导入导出的文件都存在了 `/chameleon/dump/` 文件夹下。<br />
如需要导入数据，则需要提前通过网页把需要导入的数据文件写入到上面的文件夹。

* 加载：按中键可以进入加载界面，界面会读取`/chameleon/dump/`下面所有文件，按中键可以执行导入。
* 导出：按中键可以将当前的卡片导出到`/chameleon/dump/`文件夹下。
* 重置：按中键可以重置当前卡片数据为默认内置的空卡片数据。

> 加载的文件大小必须和当前卡类型完全一致才能导入。不同卡片的数据文件大小参考`模拟卡界面`表格。

## 卡高级设置

这个界面根据MiFare系列卡片和NTAG系列卡片显示不同的内容。

> **特别注意**：<br/>
> 这个界面是卡片模拟的高级设置，不建议普通用户修改，如要修改，请修改前请确定了解你在做什么再修改！<br/>
> 如果修改此部分导致卡片模拟失败，请先还原默认设置再试试。

### MiFare系列
|   |
| ------------ |
|  自定义模式 [关] |
|  ID [de:ad:be:ef]|
|  SAK [08] |
|  ATQA: [00 40]|
|  Gen1A模式 [关] |
|  Gen2模式 [关] |
|  写入模式 [正常] |
|  [返回] |
|   |

* 自定义模式：默认为关。关：ID卡识别阶段的ID/SAK/ATQA从卡片数据的0扇区读取，开：可以在下面ID/SAK/ATQA菜单设置独立的资源。
* ID: 显示当前卡ID。如果自定义模式为开，按中键可以进入输入界面修改。自定义模式为关，按中键不生效。
* SAK: 显示当前卡SAK。如果自定义模式为开，按中键可以进入输入界面修改。自定义模式为关，按中键不生效。
* ATQA：显示当前卡ATQA。如果自定义模式为开，按中键可以进入输入界面修改。自定义模式为关，按中键不生效。
* Gen1A模式：默认为关。开启后，允许模拟器响应国产高级后门指令。这些后门指令可以直接解锁卡，而无需密钥。
* Gen2模式：默认为关。开启后，允许写入0扇区。 (0扇区主要存放了ID/SAK/ATQA这些信息，允许写入则可以修改卡片的ID)
* 写入模式：默认为正常。可以有4个值，见下表。

|  写入模式 | 说明 |
| ----- | --- |
| 正常 | 数据正常写入到内存，切换卡或者退出保存 |
| 拒绝 | 写入任何操作返回失败 |
| 忽略 | 写入操作返回成功，但是不写入内存也不保存 |
| 缓存 | 数据正常写入内存，切换卡或者退出不保存 |

> Gen1A模式和Gen2模式建议在复制卡时候打开，复制完卡后关闭，避免被读卡器识别为克隆卡。

### NTAG系列
|   |
| ------------ |
|  ID [04:68:95:71:fa:5c:64]|
|  SAK [00] |
|  ATQA: [00 44] |
|  生成UID |
|  [返回] |
|   |

* ID: 显示当前卡ID。不可编辑。
* SAK: 显示当前卡SAK。不可编辑。
* ATQA：显示当前卡ATQA。不可编辑。
* 生成UID：按中键可以随机生成一个新的ID，注意需要返回模拟界面才能模拟和保存新的卡片ID。

## 卡槽管理 

这个界面显示所有卡槽的启用状态，可以单独开启和关闭卡槽。

|   |
| ------------ |
|  卡槽数量.. [8]|
|  卡槽 01   [开] |
|  卡槽 02   [开] |
|  .. |
|  [返回] |
|   |

* 卡槽数量: 显示当前卡槽数量，默认为8，暂不支持修改数量，后续固件开放。
* 卡槽 xx: 显示卡槽开启关闭状态，按中键可以切换开启和关闭状态。

# 游戏

目前基于 [wagiminator/CH32V003-GameConsole](https://github.com/wagiminator/CH32V003-GameConsole) 移植了4个游戏。
这四个游戏如下：

* 复仇者
* 星球着陆
* 打砖块
* 俄罗斯方块

长按中键可以退出游戏。

更多信息请参考原仓库 [https://github.com/wagiminator/CH32V003-GameConsole](https://github.com/wagiminator/CH32V003-GameConsole "https://github.com/wagiminator/CH32V003-GameConsole.").

# 设置

TODO

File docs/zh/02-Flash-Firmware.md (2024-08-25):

制造硬件后，您需要通过有线的方法第一次刷写固件（如daplink、jlink等），之后无需再次进行有线刷写。

固件可以使用以下方法之一刷写或更新：

## 方法 1: 线刷
此方法需要一个兼容CMASS-DAP的JLink或DAPLink刷写器。我们推荐使用PWLINK2 Lite，您可以在 [淘宝](https://item.taobao.com/item.htm?spm=a1z09.2.0.0.4b942e8deXyaQO&id=675067753017&_u=d2p75qfn774a "Taobao")购买一个约9.9元。

下载最新版本的固件压缩包。它应该包含以下文件：
- fw_update.bat
- bootloader.hex
- pixljs.hex
- pixljs_all.hex
- fw_readme.txt
- pixjs_ota_v237.zip

你需要确保连接好 3.3V、GND、SWDIO、SWDCLK这四根线。  使用文件中的  `fw_update.bat` 下载 `pixjs_all.hex` 文件.

您也可以使用OpenOCD来刷写设备，以下是执行命令的示例:
```
openocd -f interface/cmsis-dap.cfg -c "transport select swd" -f target/nrf52.cfg -d2 -c init -c "reset init" -c halt -c "nrf5 mass_erase" -c "program pixjs_all.hex verify" -c "program nrf52832_xxaa.hex verify" -c exit
```

完成首次刷写后，后续的固件更新可以通过OTA进行。

## 方法 2: OTA 升级
这种方法仅适用于已成功通过有线方法烧录完成的Pixl.js设备。

### nRF Connect APP
安装nRF Connect应用程序（您可以在iOS和Android应用商店中找到）。

在设备列表中，选择pixl.js（或pixl dfu），然后点击 `CONNECT` 按钮

将您的pixl.js设备调整到“固件更新”模式，然后设备将进入DFU模式。要这样做，请在设备上选择 `设置` 然后选择 `固件更新`即可.

打开手机上的“nRF Connect”应用，并连接到名为 `pixl dfu` 的设备以更新固件。

在iOS上，压缩包中的固件为 `pixjs_ota_vxxx.zip` ，需要通过微信或QQ与nrfconnect应用共享。

在Android上，您可以使用屏幕右上角的DFU图标，选择 `Distribution packet (ZIP)` ，然后浏览存储中的 `pixjs_ota_vxxx.zip` 文件。

### Web方法
下载与您设备版本相对应的最新固件zip包，并将其解压到一个目录中。

该项目提供两种实现DFU更新的方法：

#### 文件传输网页
首先，您可以连接设备到 [official web page](https://pixl.amiibo.xyz/ "official web page") ，然后在网页上，设备连接后，按下DFU灰色按钮，设备将进入DFU模式，并且页面会询问您“您是否要打开DFU升级页面？”如果您接受，固件更新页面将被打开。

#### 直接进入固件更新页面
你也可以直接进入固件更新页面。

首先，您需要将您的pixl.js设备放置在“固件更新”模式下。为此，请选择`设置`，然后选择`固件更新`。 

打开 [固件更新页面](https://thegecko.github.io/web-bluetooth-dfu).  从您提取固件包的文件夹中拖放或选择`pixljs_ota_xxx.zip`文件。
然后在页面上点击 `SELECT DEVICE` 按钮，您应该看到一个名为`pixl dfu` 的设备，连接以开始固件升级过程。

# 修复错误的固件版本

如果操作不当在设备上烧录了错误的固件版本（LCD/OLED），设备将工作但屏幕上不会显示信息，LCD版本的背光可能会打开。

您可以使用以下方法恢复或刷写正确的固件版本。

## 方法1：通过有线连接刷写固件

如果您手头有任何兼容CMASS-DAP的JLink或DAPLink编程器，您可以使用有线方法手动刷写正确的固件版本。

## 方法2：按照特殊的按键序列再次进入DFU模式，以刷写正确的固件版本。

首先确保您的设备处于关闭状态，然后按照下面的按键序列进入 `DFU 模式`

任意键唤醒设备
左
中
左 x N
中

如果固件版本小于 2.11.x, 按左 x 4。
如果固件版本大于 2.11.x, 按左 x 5。

现在您的设备已经进入了DFU模式，请使用任何 [nRF Connect APP](#nRF-Connect-APP)  或 [直接进入固件页面更新](#directly-to-the-firmware-update-page) 的方法来升级固件。

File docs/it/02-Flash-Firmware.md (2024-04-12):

Dopo aver costruito o acquistato l'hardware, devi flashare il firmware per la prima volta, che può essere ottenuto solo tramite il metodo cablato.

Il firmware può essere flashato o aggiornato utilizzando uno dei seguenti metodi:

## Metodo 1: Cablato
Questo metodo richiede un flasher compatibile con CMASS-DAP JLink o DAPLink. Raccomandiamo il programmatore STM32 PWLINK2 Lite Emulator, puoi comprarne uno per circa 9.9 yuan su [Taobao](https://item.taobao.com/item.htm?spm=a1z09.2.0.0.4b942e8deXyaQO&id=675067753017&_u=d2p75qfn774a "Taobao")

Scarica l'ultima versione del pacchetto zip del firmware. Dovrebbe contenere i seguenti file:
- fw_update.bat
- bootloader.hex
- pixljs.hex
- pixljs_all.hex
- fw_readme.txt
- pixjs_ota_v237.zip

Devi collegare i cavi da 3.3 Volt, GND, SWDIO e SWDCLK. Puoi utilizzare il file `fw_update.bat` per flashare il firmware `pixjs_all.hex`.

Puoi anche utilizzare OpenOCD per flashare il dispositivo, questo è un esempio del comando da eseguire:
```
openocd -f interface/cmsis-dap.cfg -c "transport select swd" -f target/nrf52.cfg -d2 -c init -c "reset init" -c halt -c "nrf5 mass_erase" -c "program pixjs_all.hex verify" -c "program nrf52832_xxaa.hex verify" -c exit
```
Dopo che il primo flash è completato, gli aggiornamenti del firmware successivi possono essere effettuati tramite OTA.

## Metodo 2: Aggiornamento OTA
Questo metodo è applicabile solo ai dispositivi Pixl.js che sono stati programmati con successo tramite il metodo cablato.

### App nRF Connect
Installa l'applicazione nRF Connect (la puoi trovare sia su iOS che su Android app stores).

Nella lista dei dispositivi, seleziona pixl.js (o pixl dfu) e tocca il pulsante `CONNECT`

Metti il tuo dispositivo pixl.js in modalità "Aggiornamento Firmware", poi il dispositivo entrerà in modalità DFU. Per farlo, seleziona l'app `Settings` e seleziona la voce `Firmware Update`.

Apri l'app "nRF Connect" sul tuo telefono e connettiti al dispositivo chiamato `pixl dfu` per aggiornare il firmware.

Su iOS, il firmware è `pixjs_ota_vxxx.zip`

### Metodo della pagina web
Scarica l'ultima versione del pacchetto zip del firmware corrispondente alla versione del tuo dispositivo ed estrailo in una directory.

Il progetto fornisce due modi per ottenere un aggiornamento DFU:

#### Pagina web di trasferimento file.
Innanzitutto, puoi collegare il dispositivo alla [pagina web ufficiale](https://pixl.amiibo.xyz/ "pagina web ufficiale"), poi sulla pagina web, dopo che il dispositivo è connesso, premi il pulsante grigio `DFU`, il dispositivo entrerà in modalità DFU e la pagina ti chiederà "Vuoi aprire la pagina di aggiornamento DFU?" se accetti, la Pagina di Aggiornamento Firmware sarà aperta.

#### Direttamente alla Pagina di Aggiornamento Firmware.
Puoi anche andare direttamente alla Pagina di Aggiornamento Firmware.

Prima di tutto, devi mettere il tuo dispositivo pixl.js in modalità "Aggiornamento Firmware". Per farlo, seleziona l'app `Impostazioni` e seleziona la voce `Aggiornamento Firmware`.

Apri la [pagina di aggiornamento firmware](https://thegecko.github.io/web-bluetooth-dfu). Trascina e rilascia o seleziona il file `pixljs_ota_xxx.zip` dalla cartella dove hai estratto il pacchetto firmware.

Poi premi il pulsante `SELEZIONA DISPOSITIVO` sulla pagina dovresti vedere un dispositivo chiamato `pixl dfu` connetti per iniziare il processo di aggiornamento del firmware.

# Riparazione versione firmware errata.

Se per errore programmi la versione sbagliata (LCD/OLED) sul tuo dispositivo, il dispositivo funzionerà ma non mostrerà informazioni sullo schermo, la retroilluminazione della versione LCD potrebbe accendersi.

Puoi utilizzare i seguenti metodi per recuperare o flashare la versione firmware corretta.

## Opzione 1: Flasha il firmware tramite connessione cablata

Se hai a disposizione un programmatore JLink o DAPLink compatibile con CMASS-DAP, puoi utilizzare il [Metodo Cablato](Flash-Firmware#Method 1: Wired "Metodo Cablato") per flashare manualmente la versione firmware corretta.
Se per errore programmi la versione sbagliata (LCD/OLED) sul tuo dispositivo, il dispositivo funzionerà ma non mostrerà informazioni sullo schermo, la retroilluminazione della versione LCD potrebbe accendersi.

## Opzione 2: Segui le sequenze di tasti speciali per entrare nuovamente nella modalità DFU e installare la versione corretta del firmware.

Prima assicurati che il tuo dispositivo sia spento, poi premi le seguenti sequenze di tasti per entrare nella `Modalità DFU`

- Un qualsiasi tasto per risvegliare il dispositivo
- SINISTRA
- CENTRO
- SINISTRA X 4
- CENTRO

Ora il tuo dispositivo è in modalità DFU, usa l'app [nRF Connect APP](#nRF-Connect-APP) o [Direttamente dalla pagina di aggiornamento del firmware](#directly-to-the-firmware-update-page) per aggiornare il firmware.

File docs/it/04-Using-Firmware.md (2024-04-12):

# Concetti del Firmware
## Amiibo
È un dispositivo venduto da Nintendo, normalmente sotto forma di statuetta, ma esistono anche carte, cinturini da polso e altri.

Ogni amiibo ha un tag NFC incorporato nella base della statuetta. Il tag NFC ha alcuni dati pre-registrati in fabbrica che identificano il tipo di statuetta e rendono ogni amiibo unico rispetto agli altri. I principali dati dell'amiibo sono:

Come affermato da Nintendo, Amiibo è singolare e plurale (https://twitter.com/NintendoAmerica/status/535485751635763200)

## Informazioni sul modello
È un numero che descrive la serie amiibo, la serie di giochi, il personaggio e la variazione del personaggio, queste informazioni non possono essere modificate dopo la prima programmazione.

## UID
È il numero di serie della statuetta, anch'esso preimpostato in fabbrica, rendendo ogni amiibo unico.

## Dati Amiibo
Questa sezione dei dati sul tag memorizza le informazioni modificabili dall'utente come la registrazione del proprietario e del soprannome o i dati del salvataggio del gioco.

## UUID
Il termine UUID viene utilizzato nella scena mod per fare riferimento all'UID inviato al gioco da un emulatore amiibo, poiché il gioco usa l'UID per sapere se un amiibo è già stato utilizzato; se l'emulatore cambia l'UID, l'amiibo emulato sembra un amiibo completamente diverso per il gioco, permettendo di utilizzare nuovamente quell'amiibo.

## key_retail.bin
È un file binario che contiene le chiavi private di Nintendo per criptare amiibo, è un materiale protetto da copyright quindi devi fornire una copia legalmente acquisita, puoi scaricarla da una console 3DS o Switch.

## File .BIN
I dati di un amiibo possono essere scaricati su un file, quel dump binario del contenuto originale di un amiibo viene memorizzato su un file con estensione `.BIN`, quei dump vengono caricati sul dispositivo per l'applicazione Amiibo Emulator o l'applicazione AmiiboLink Emulator. Devi fornire un file di dump binario legalmente acquisito.

## Interruttore a cursore Thumbwheel
È il microinterruttore in cima al dispositivo, è un dispositivo che ha tre pulsanti in uno, uno centrale e due laterali. Oscillando il microinterruttore ai lati si premono i pulsanti "**laterali**". Premendo il microinterruttore si preme il pulsante "**centrale**".

In questo documento, premere i lati del Thumbwheel viene chiamato "**pulsanti laterali**", premere il Thumbwheel viene chiamato "**pulsante centrale**"; per navigare tra gli elementi di un menu si usano i pulsanti laterali, per selezionare un elemento si preme il pulsante centrale.

# Utilizzo del Firmware
La schermata principale del firmware Pixl.js è divisa in diverse applicazioni, ognuna delle quali può essere eseguita per eseguire alcune azioni, le applicazioni nella schermata principale sono:

|   |
| ------------ |
|  Emulatore Amiibo<br> Database Amiibo<br>֍ AmiiboLink<br>ᛡᛒ  Trasferimento file BLE<br> Impostazioni |
|   |

----
# Emulatore Amiibo
Questa applicazione ti permette di sfogliare la memoria locale per i file .BIN e usarli come amiibo corrente.

Puoi sfogliare cartelle e file usando l'interruttore a cursore Thumbwheel, spingendo ai lati cambi gli elementi, premendo il pulsante centrale selezioni l'elemento evidenziato.

Una volta selezionato un file .BIN, i suoi dati vengono utilizzati come amiibo corrente, lo schermo mostra i dettagli dell'amiibo corrente come UUID corrente dell'amiibo, nome del file e nome dell'amiibo.

## Schermata dettagli amiibo
Puoi usare i pulsanti laterali per cambiare l'amiibo corrente con il successivo o il precedente nella cartella corrente. Premendo il pulsante centrale puoi cambiare il comportamento dell'amiibo corrente, nel sottomenu:

|   |
| ------------ |
| Rand. Tag<BR>Auto Rand.<BR>Elimina Tag<BR>Torna ai dettagli del Tag<BR>Torna alla lista dei file<BR>Torna al menu principale<BR>Rand. Tag |
|   |

### Rand. Tag
Randomizza Tag, cambia l'UUID corrente presentato al gioco per l'amiibo corrente. Il nuovo UUID rimane invariato fino a quando non cambi l'amiibo corrente o selezioni nuovamente questa opzione.
### Auto Rand. (Random automatico)
Attivando questa funzione, verrà generato un nuovo UUID casuale per l'amiibo corrente ogni volta che un gioco lo legge.  Consentendo di utilizzare lo stesso amiibo più volte su giochi con restrizioni.
### Elimina Tag
Elimina il file associato all'amiibo corrente.
### Torna ai dettagli del Tag
Ritorna ai dettagli dell'amiibo corrente.
### Torna alla lista dei file
Ritorna alla lista dei file della cartella corrente.
### Torna al menu principale
Esci dall'applicazione emulatore amiibo.

_Se abiliti la generazione di UUID casuali, manualmente o automaticamente l'UUID originale del file .BIN viene utilizzato la prossima volta che quel file viene caricato._

## Esploratore di file.
Se hai **evidenziato una cartella o un file** e tieni premuto il pulsante centrale per 1 secondo si apre un sottomenu delle proprietà:

|   |
| ------------ |
| Crea nuova cartella…<BR>Crea nuovo Tag…<BR>Rinomina…<BR>Elimina...<BR>Torna alla lista dei file<BR>Torna al menu principale |
|   |

### Crea nuova cartella…
Dialogo per creare una nuova sottocartella nella corrente.
### Crea nuovo Tag…
Crea un file .BIN amiibo vuoto nella cartella corrente.  Quel file .BIN è ora un simile di un New Ntag215, pronto per essere programmato, puoi assegnare quel file .BIN come amiibo corrente e usando un programmatore NFC puoi scrivere i dati dell'amiibo, ad esempio puoi usare iNFC o Tagmo per i telefoni, Thenaya per il 3DS.  Se l'amiibo programmato è nel database il file .BIN viene anche rinominato con il nome dell'amiibo.
### Rinomina…
Dialogo per rinominare il file .BIN o la cartella evidenziata
### Elimina…
Rimuove l'oggetto evidenziato, chiedendo conferma.  Se è una cartella, anche tutte le sottocartelle e i file vengono eliminati.
### Torna alla lista dei file
Ritorna alla lista dei file della cartella corrente.
### Torna al menu principale
Esci dall'applicazione emulatore amiibo.

Se hai **evidenziato una memoria** il sottomenu delle proprietà è diverso:

|   |
| ------------ |
| Stato della memoria<BR>Spazio totale<BR>Spazio libero<BR>Formatta…<BR>Torna alla lista<BR>Torna al menu principale |
|   |

### Stato della memoria
Mostra lo stato corrente e il tipo della memoria, ad esempio:
```
=====Non montato=====
===Montato[LFS]===
===Montato[FFS]===
```

### Spazio totale
Mostra lo spazio totale della memoria montata in KB.
### Spazio libero
Mostra lo spazio libero attuale della memoria montata in KB.
### Formatta…
Chiede conferma per formattare la memoria corrente, ATTENZIONE TUTTI I DATI VERRANNO PERSI!
### Torna alla lista
Ritorna alla lista dei file della cartella corrente.
### Torna al menu principale
Esci dall'applicazione emulatore amiibo.

----
# Database Amiibo
Questa applicazione permette l'emulazione di amiibo dalla lista di quelli ben noti, utilizzando informazioni legalmente disponibili come le informazioni sul modello, poi quando ne selezioni uno, viene creato un nuovo amiibo virtuale in memoria utilizzando un UUID casuale.  Per utilizzare questa applicazione devi fornire il tuo file «key_retail.bin».

Ogni volta che si usa un amiibo, l'UUID iniziale viene generato casualmente._

Una volta aperta l'applicazione il menu principale ha le opzioni

|   |
| ------------ |
| Browser…<BR>Ricerca…<BR>I miei preferiti…<BR>I miei Amiibo…<BR>Impostazioni… |
|   |

## Browser… 
Ti permette di sfogliare il database, prima per categoria, poi tutti gli amiibo di quella categoria.
Dopo aver selezionato un amiibo, vengono mostrati i dettagli, la prima riga contiene l'UUID attuale e la seconda riga il nome dell'amiibo.

Nella pagina dei dettagli dell'amiibo puoi usare i pulsanti laterali per navigare tra tutti gli amiibo della categoria, se premi il pulsante centrale puoi cambiare il comportamento dell'amiibo corrente, con il sottomenu:

|   |
| ------------ |
| Rand. Tag<BR>Auto Rand.<BR>Preferito…<BR>Salva come…<BR>[Torna ai dettagli]<BR>[Torna alla lista]<BR>[Esci] |
|   |

### Rand. Tag
Randomizza Tag, cambia l'UUID corrente presentato al gioco per l'amiibo corrente. Il nuovo UUID rimane invariato fino a quando non cambi l'amiibo corrente o selezioni nuovamente questa opzione.
### Auto Rand. (Random automatico)
Attivando questa funzione, verrà generato un nuovo UUID casuale per l'amiibo corrente ogni volta che un gioco lo legge.  Consentendo di utilizzare lo stesso amiibo più volte su giochi con restrizioni.
### Preferito…
Apri un nuovo sottomenu per gestire le cartelle dei preferiti.  Hai le opzioni:

```
Nuovo…
Cartella1
Cartella2
[Indietro]
```

**Nuovo…** ti permette di creare una nuova cartella dei preferiti, **Indietro** torna ai dettagli dell'amiibo corrente, se selezioni una cartella esistente, quella definizione di amiibo verrà aggiunta alla cartella selezionata.

### Salva come…
Ti permette di assegnare l'amiibo corrente a uno degli slot «I miei Amiibo».
### [Torna ai dettagli]
Ritorna ai dettagli dell'amiibo corrente.
### [Torna alla lista]
Ritorna alla lista degli amiibo della categoria corrente.
### [Esci]
Esci dall'applicazione Database Amiibo.

## Ricerca…
Permette di cercare nel database usando un nome parziale, il risultato della ricerca è come una categoria, puoi selezionare qualsiasi amiibo su di essa e impostarlo come un altro.

## I miei preferiti…
Mostra le cartelle dei preferiti esistenti, puoi sfogliarle con i pulsanti laterali e selezionarne una con il pulsante centrale.  Se premi e tieni premuto il pulsante centrale si apre un sottomenu:

|   |
| ------------ |
| Nuovo…<BR>Svuota…<BR>Elimina…<BR>[Indietro] |
|   |

### Nuovo…
Ti permette di creare una nuova cartella dei preferiti.
### Svuota…
Dopo la conferma, rimuove tutti gli amiibo associati alla cartella selezionata.
### Elimina…
Dopo la conferma, rimuove la cartella dei preferiti.
### [Indietro]
Ritorna alla lista delle cartelle.

Una volta selezionata una cartella viene mostrata una lista degli amiibo associati a quella cartella dei preferiti, puoi sfogliare usando i pulsanti laterali e selezionare un amiibo con il pulsante centrale, l'amiibo selezionato diventa l'attuale e si comporta come un amiibo del browser.

## I miei Amiibo…
Elenca gli slot configurati, puoi sfogliare gli slot usando i pulsanti laterali, selezionarne uno con il pulsante centrale e l'amiibo associato a quello slot diventa l'attuale.

Se premi e tieni premuto il pulsante centrale si apre un sottomenu con l'opzione di reimpostare lo slot permettendo di svuotare lo slot.

## Impostazioni…
Il menu delle impostazioni ti mostra lo stato delle chiavi e il numero di slot impostato.

|   |
| ------------ |
| Chiavi []<BR>Num. Slot []<BR>[Indietro] |
|   |

### Chiavi []
Mostra lo stato del file «key_retail.bin», può essere «Caricato» o «NON caricato»
### Num. Slot []
Permette di selezionare quanti slot sono disponibili per la sezione «I miei Amiibo», valori da 10 a 50 con incrementi di decine.
### [Indietro]
Esci dal Database Amiibo e torna al Menu Principale.

----
# AmiiboLink
Questa applicazione emula un dispositivo AmiiboLink (AmiLoop o omllbolink).

Questi dispositivi sono schede espruino generiche vendute in diverse forme, normalmente sono portachiavi a forma di goccia, ma esistono anche alcuni Puck o Sheika Slate.

Quasi tutti hanno un pulsante e alcuni LED come indicatori e funzionano con batterie a cella CR2032 o celle lipo.

Tutti sono controllati da applicazioni per telefoni tramite Bluetooth, inoltre puoi caricare uno o più file .BIN amiibo utilizzando il telefono sul dispositivo.

Avviando questa applicazione vengono mostrati i dettagli per l'amiibo corrente.  Se sei in modalità sequenziale puoi usare i pulsanti laterali per scorrere tutti gli amiibo caricati, in tutte le modalità, puoi premere il pulsante centrale per aprire il sottomenu di configurazione dell'APP AmiiboLink, il menu ha queste voci:

|   |
| ------------ |
| Modalità []<BR>Auto Rand. []<BR>Modalità Compati. []<BR>Dettagli Tag<BR>[Menu Principale] |
|   |

## Modalità []
Mostra la modalità di funzionamento attuale, quando selezionata puoi scegliere la modalità di funzionamento dell'amiibo, le modalità disponibili sono:
- ### Randomizza (Manuale)
Sul dispositivo AmiiboLink attuale l'amiibo corrente cambia l'UUID quando premi il pulsante del dispositivo
- ### Randomizza (Auto)
Un nuovo UUID casuale per l'amiibo corrente viene generato ogni volta che un gioco lo legge.  Consentendo di utilizzare lo stesso amiibo più volte su giochi con restrizioni. Non puoi cambiare l'amiibo attivo in questa modalità.
- ### Modalità sequenziale
In questa modalità puoi cambiare l'amiibo attuale usando i pulsanti laterali, scorrendo tra tutti gli amiibo caricati con l'app del telefono. Tutti i file .BIN caricati sono memorizzati nei file 01.bin a 26.bin nella cartella /amiibolink/.
- ### Modalità lettura-scrittura
Il dispositivo utilizza uno slot amiibo "speciale" dove può essere utilizzato solo un amiibo, l'amiibo può essere sostituito da un altro file .BIN dall'app del telefono. Nella memoria locale questo amiibo viene salvato con il file /amiibolink/99.bin.

Cambiando la modalità si conserva l'amiibo selezionato corrente, con l'eccezione della modalità «Lettura-scrittura».

### Modalità Compati. []
Mostra la modalità di emulazione del firmware, i valori supportati sono V1, V2 e AmiLoop, ci sono diverse APP, ognuna progettata per una versione del firmware AmiiboLink o per il protocollo AmiLoop.  Utilizzando questa impostazione puoi far corrispondere l'emulazione con il protocollo necessario per l'APP che usi sul tuo telefono.
## Dettagli Tag
Ritorna alla pagina dei dettagli del tag
## [Menu Principale]
Esci dall'applicazione Emulatore AmiiboLink.

## Applicazioni compatibili con AmiiboLink
Finora le uniche due App di gestione della modalità AmiiboLink/AmiLoop tradotte in inglese sono "Umiibo" e "AmiLoop", queste applicazioni sono compatibili solo con la Modalità AmiLoop.

Un'altra particolarità è che le modalità sulle applicazioni non corrispondono con le modalità impostate sul dispositivo.

| App Umiibo | Modalità di emulazione Pixl.js |
| --- |--- |
| Modalità Manuale | Random automatico |
| Modalità File | Sequenziale |
| Modalità Auto | Lettura/Scrittura |

| App AmiiLoop | Modalità di emulazione Pixl.js |
| --- |--- |
| Modalità Manuale | Random automatico |
| Modalità File | Sequenziale |
| Modalità Auto | Lettura/Scrittura |

# Emulatore di Carte

Questa applicazione può essere utilizzata per emulare carte Mifare e carte della serie NTAG.

Le carte Mifare sono comunemente utilizzate per le carte di controllo degli accessi, e il dispositivo può emulare completamente i tipi di carte Mifare. I tipi di carte Mifare supportati includono:

* Mifare Mini
* Mifare 1K
* Mifare 2K
* Mifare 4K

Le carte della serie NTAG sono comunemente utilizzate per l'identificazione del dispositivo. I tipi di carte NTAG supportati includono:

* NTAG 213
* NTAG 215
* NTAG 216

Attualmente, un totale di 8 carte sono supportate, con l'opzione per personalizzare il numero di carte in futuro.

> Nota:<br/>
> La funzione di emulazione della serie NTAG è ancora in fase di test, e la funzionalità non è ancora completa. Non emula completamente > le caratteristiche di NTAG125. <br/>
> Continueranno ulteriori miglioramenti a questa parte della funzionalità.

L'emulazione può essere attivata solo in questa interfaccia, e sarà disattivata se si lascia questa interfaccia.

Dopo la formattazione del disco o il primo ingresso nell'emulatore di carte, i dati verranno inizializzati. Questo processo può richiedere alcuni secondi, quindi si prega di essere pazienti.

## Emulazione di Carte

L'interfaccia della pagina di emulazione delle carte è la seguente:

|   |
| ------------ |
| [01] de:ad:be:ef|
|  |
| <    Slot 01      >|
|  |
| MF 1K <08/04 00>  |
|   |

L'interfaccia è spiegata come segue:

* La prima riga: `01` è il numero della carta, e `de:ad:be:ef` è l'ID della carta.
* La seconda riga: Slot 01 è il nome della carta corrente, che può essere liberamente impostato.
* La terza riga: `MF 1K` visualizza il tipo di carta. Le abbreviazioni del tipo sono mostrate nella tabella sottostante. `08` è il SAK della carta, `04 00` è l'ATQA della carta. L'ultimo simbolo indica la modalità di scrittura. Se è contrassegnato come un disco, la scrittura è consentita; altrimenti, la scrittura non è consentita.
Abbreviazioni per i tipi di carte:

| Nome visualizzato | Tipo di carta | Dimensione del file di dati |
| ---- | --- | --- |
| MF mini | Mifare Mini | 320 |
| MF 1k | Mifare 1K | 1024 |
| MF 2k | Mifare 2K | 2048 |
| MF 4k | Mifare 4K | 4096 |
| N213 | NTAG 213 | 180 |
| N215 | NTAG 215 | 540 |
| N216 | NTAG 216 | 924 |

# Menu Principale

Premendo il pulsante centrale si può entrare nel menu principale. Come segue:

|   |
| ------------ |
|  Slot  [01]|
|  Nick [Slot 01]|
|  ID [de:ad:be:ef]|
|  Tipo [MiFare 1K] |
|  Dati.. |
|  Avanzate.. |
|  Impostazioni Slot.. |
|  [Dettagli Tag] |
|  [Menu Principale] |
|   |

* Slot: Visualizza lo slot della carta selezionato corrente. Puoi selezionare uno slot della carta premendo il pulsante centrale.
* Nick: Il nome corrente della carta. Premendo il pulsante centrale si può entrare nell'interfaccia di impostazione del nome della carta.
* ID: Visualizza l'ID corrente della carta.
* Tipo: Visualizza il tipo corrente della carta.
* Dati: Premendo il pulsante centrale si possono gestire i dati della carta.
* Avanzate: Premendo il pulsante centrale si possono impostare le impostazioni avanzate della carta.
* Impostazioni Slot: Premendo il pulsante centrale si entra nell'interfaccia di gestione dello slot, dove si possono abilitare o disabilitare gli slot delle carte.
* [Dettagli Tag]: Ritorna alla pagina dei dettagli del tag.
* [Menu Principale]: Esce da questa applicazione e entra nel menu principale.

> **Nota speciale:**：<br/>
> Alcune modifiche devono essere salvate nella memoria quando si esce dai dettagli del tag. Se hai modificato alcune configurazioni, assicurati di entrare nella pagina dei dettagli del tag per salvarle.

## Aggiornamento Nick

In questa interfaccia, è possibile modificare il nome della carta.

A causa dello spazio di visualizzazione limitato, è possibile inserire solo caratteri inglesi.

In particolare, se si utilizzano caratteri cinesi, a causa della codifica UTF-8, l'eliminazione richiede almeno 2 pressioni per eliminare completamente.

Se si desidera aggiungere note cinesi alla carta, è possibile modificare le note di `/chameleon/slots/00.bin` attraverso la pagina web per ottenere note cinesi.<br />
00.bin è il file per il primo slot della carta, 01.bin è il file per il secondo slot della carta, e così via.

> A causa delle limitazioni di dimensione del firmware, attualmente solo circa 1000 caratteri cinesi possono essere visualizzati correttamente. Se i caratteri cinesi non vengono visualizzati, si prega di segnalare un problema con i caratteri che è necessario visualizzare. I caratteri specifici possono essere aggiunti nella prossima versione.

## Dati della Carta

In questa interfaccia, è possibile eseguire l'importazione e l'esportazione dei dati della carta.

|   |
| ------------ |
|  Carica.. |
|  Salva.. |
|  Factory.. |
|   |

I file di importazione ed esportazione sono memorizzati nella cartella `/chameleon/dump/`.<br />
Se è necessario importare dati, è necessario scrivere in anticipo il file di dati che si desidera importare nella cartella sopra tramite la pagina web.

* Carica: Premendo il pulsante centrale si può entrare nell'interfaccia di caricamento. L'interfaccia leggerà tutti i file sotto `/chameleon/dump/`, e premendo il pulsante centrale si può eseguire l'importazione.
* Salva: Premendo il pulsante centrale si può esportare la carta corrente nella cartella `/chameleon/dump/`.
* Factory: Premendo il pulsante centrale si può reimpostare i dati della carta corrente ai dati della carta vuota predefiniti incorporati.

## Avanzate

Questa interfaccia mostra contenuti diversi in base alle carte della serie MiFare e alle carte della serie NTAG.

> **Nota speciale:**<br/>
> Questa interfaccia è le impostazioni avanzate per l'emulazione della carta, e non è consigliato per gli utenti ordinari modificare. Se intendi apportare modifiche, assicurati di capire cosa stai facendo prima di modificare!<br/>
> Se la modifica di questa parte porta a un fallimento dell'emulazione della carta, prova a ripristinare le impostazioni predefinite prima.

### Serie MiFare
|   |
| ------------ |
|  Modalità personalizzata [OFF] |
|  ID [de:ad:be:ef]|
|  SAK [08] |
|  ATQA: [00 40]|
|  Gen1A Abilitato [OFF] |
|  Gen2 Abilitato [OFF] |
|  Modalità di scrittura [Normale] |
|  [RITORNO] |
|   |

* Modalità personalizzata: Di default è disattivata. Disattivata: Durante la fase di riconoscimento della carta ID, ID/SAK/ATQA vengono letti dal settore 0 dei dati della carta. Attivata: Puoi impostare risorse indipendenti nel menu ID/SAK/ATQA qui sotto.
* ID: Mostra l'ID corrente della carta. Se la modalità personalizzata è attiva, premendo il pulsante centrale ti permette di entrare nell'interfaccia di input per la modifica. Se la modalità personalizzata è disattivata, premendo il pulsante centrale non ha effetto.
* SAK: Mostra l'SAK corrente della carta. Se la modalità personalizzata è attiva, premendo il pulsante centrale ti permette di entrare nell'interfaccia di input per la modifica. Se la modalità personalizzata è disattivata, premendo il pulsante centrale non ha effetto.
* ATQA: Mostra l'ATQA corrente della carta. Se la modalità personalizzata è attiva, premendo il pulsante centrale ti permette di entrare nell'interfaccia di input per la modifica. Se la modalità personalizzata è disattivata, premendo il pulsante centrale non ha effetto.
* Gen1A Abilitato: Di default è disattivato. Quando abilitato, permette all'emulatore di rispondere ai comandi backdoor avanzati domestici. Questi comandi backdoor possono sbloccare direttamente la carta senza la necessità di una chiave.
* Gen2 Abilitato: Di default è disattivato. Quando abilitato, permette la scrittura nel settore 0. (Il settore 0 memorizza principalmente informazioni come ID/SAK/ATQA, e permettendo la scrittura può modificare l'ID della carta)
* Modalità di scrittura: Di default è normale. Ci possono essere 4 valori, vedi la tabella sottostante.

|  Modalità di scrittura | Descrizione |
| ----- | --- |
| Normale | I dati vengono scritti normalmente in memoria, cambia carta o esci per persistere |
| Nega | Qualsiasi operazione di scrittura restituisce un fallimento |
| Ignora | L'operazione di scrittura restituisce un successo, ma non scrive in memoria o persiste |
| Cache | I dati vengono scritti normalmente in memoria, cambiando le carte o uscendo non persistono |

> Si consiglia di abilitare la modalità Gen1A e la modalità Gen2 quando si copiano le carte, e chiuderle dopo la copia per evitare di essere riconosciute come una carta clone dai lettori di carte.

### Serie NTAG
|   |
| ------------ |
|  ID [04:68:95:71:fa:5c:64]|
|  SAK [00] |
|  ATQA: [00 44] |
|  Rand. UID |
|  [RITORNO] |
|   |

* ID: Mostra l'ID corrente della carta. Non modificabile.
* SAK: Mostra l'SAK corrente della carta. Non modificabile.
* ATQA: Mostra l'ATQA corrente della carta. Non modificabile.
* Rand. UID: Premendo il pulsante centrale si può generare casualmente un nuovo ID. Nota che è necessario tornare all'interfaccia di emulazione per simulare e salvare il nuovo ID della carta.

## Impostazioni Slot

Questa interfaccia mostra lo stato di abilitazione/disabilitazione di tutti gli slot delle carte e permette di abilitare o disabilitare individualmente ogni slot delle carte.

|   |
| ------------ |
|  Num. Slot.. [8]|
|  Slot 01   [ON] |
|  Slot 02   [OFF] |
|  .. |
|  [RITORNO] |
|   |

* Num. Slot: Mostra il numero corrente di slot delle carte, che è impostato di default a 8. Attualmente, la modifica della quantità di slot non è supportata, e sarà disponibile negli aggiornamenti futuri del firmware.
* Slot xx: Mostra lo stato di apertura/chiusura dello slot della carta. Premendo il pulsante centrale si può passare tra lo stato di apertura e chiusura.

----
# Trasferimento file BLE
Questa applicazione ti permette di connetterti all'iNFC o alla pagina web pixl.js, per gestire i file sulla memoria del dispositivo o aggiornare il firmware.

La pagina web ufficiale è [https://pixl.amiibo.xyz/](https://pixl.amiibo.xyz/ "https://pixl.amiibo.xyz/.").

L'**APP iNFC** è un'app di terze parti

Entrando in questa modalità l'indirizzo MAC Bluetooth del dispositivo e l'URL ufficiale vengono mostrati sullo schermo.

----
# Impostazioni
Questa applicazione permette di configurare le impostazioni di funzionamento del dispositivo, l'applicazione ha le seguenti voci nel menu:

|   |
| ------------ |
| Versione []<BR>Lingua []<BR>Memoria Auto []<BR>Retroilluminazione / Contrasto OLED []<BR>Animazione Menu []<BR>Batteria LiPO []<BR>Memoria Utilizzata []<BR>Ripresa Veloce []<BR>Timer Sleep []<BR>Aggiornamento Firmware<BR>Riavvio Sistema |
|   |

## Versione
Questo sottomenu mostra i dettagli della versione del firmware.
- Versione
- Data di costruzione
- Githash
- Branch
- Target
- Dirty
## Lingua
Puoi cambiare la lingua visualizzata sul dispositivo
## Memoria Auto
Attivando questa impostazione le memorie locali del dispositivo sono nascoste alla radice dell'applicazione Emulatore Amiibo, se questa impostazione è OFF l'oggetto «Flash esterno» viene mostrato alla radice dell'applicazione Emulatore Amiibo.
## Retroilluminazione / Contrasto OLED
Con questa impostazione puoi controllare la luminosità dello schermo LCD o il contrasto dello schermo OLED.

## Animazione Menu
Abilita / disabilita l'animazione degli elementi più grandi dello schermo permettendo di leggerli completamente, abilitando questa opzione aumenta il consumo della batteria.
## Batteria LiPO
Abilita l'uso di una batteria LiPO. Richiede una modifica hardware. Se costruisci una versione Pixl.js del dispositivo con LiPO, puoi abilitare questa opzione. Per la versione CR2032, questa opzione non funzionerà e non dovrebbe essere abilitata.

Se abiliti l'opzione LiPO, il dispositivo utilizzerà il livello di tensione LiPO per visualizzare il livello della batteria, e può anche visualizzare un'etichetta di carica quando la batteria è in modalità di carica.
## Memoria Utilizzata
Mostra la percentuale di memoria di archiviazione utilizzata in fondo allo schermo
## Risveglio Rapido
Abilita l'ibernazione del dispositivo, permettendo una risposta più veloce alla lettura dell'amiibo corrente da parte di un gioco, e riprende all'applicazione aperta al momento del sonno, quando disabilitato la ripresa dopo il sonno richiede 1 secondo in più e il dispositivo ripristina al Menu Principale.
## Timer Sleep
Imposta il tempo in cui il dispositivo va in sleep dopo l'ultimo input dell'utente o la lettura dell'amiibo.
## Aggiornamento Firmware
Questa opzione mette il dispositivo in modalità DFU, permettendo l'aggiornamento del firmware OTA, puoi aggiornare il firmware utilizzando l'iNFC o la pagina web.

Puoi andare all'URL [https://thegecko.github.io/web-bluetooth-dfu/](https://thegecko.github.io/web-bluetooth-dfu/) per caricare il firmware, questa pagina può anche essere aperta attraverso il sito ufficiale [https://pixl.amiibo.xyz/](https://pixl.amiibo.xyz/)
## Riavvio Sistema
Ti permette di riavviare il dispositivo e tornare allo stato dopo che hai rimosso e inserito la batteria.

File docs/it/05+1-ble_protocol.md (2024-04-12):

# Parametri Bluetooth

Attualmente, si utilizza l'SDK NRF52 per fornire il servizio UART Nordic, che fornisce una porta seriale virtuale BLE per comunicare con l'host.

Nome del dispositivo: Pixl.js

Lista dei servizi:

1. Servizio UART Nordic

NUS_SERVICE_UUID: 6e400001-b5a3-f393-e0a9-e50e24dcca9e

Sono fornite due caratteristiche:

* NUS_CHAR_TX_UUID: 6e400002-b5a3-f393-e0a9-e50e24dcca9e => Fornisce la trasmissione dei dati, supporta la scrittura e la scrittura senza ritorno.
* NUS_CHAR_RX_UUID: 6e400003-b5a3-f393-e0a9-e50e24dcca9e => Fornisce la lettura dei dati e supporta solo le notifiche.

(La versione ufficiale dei descrittori sopra può essere modificata.)

# Formato del protocollo

## Definizione del protocollo

Considerando l'efficienza, il protocollo BLE è un protocollo binario.
Questo protocollo è un protocollo di richiesta risposta, e tutte le richieste devono essere iniziate dal client.
Per semplificare l'implementazione del protocollo, ci sarà solo un pacchetto di risposta per ogni richiesta.

### Definizione della struttura del pacchetto

Per semplificare il protocollo, sia le richieste che le risposte utilizzano la stessa struttura del pacchetto.

La struttura generale del pacchetto è la seguente

| Nome del campo | Tipo | Lunghezza (byte) | Descrizione |
| ---- | ----- |---- | ---- |
| cmd | uint8 | 1 | tipo di comando |
| status | uint8 | 1 | Codice di stato, vedi la definizione del codice di stato sotto, il pacchetto di richiesta è fisso a 0 |
| chunk | uint16 | 2 | numero di sequenza del frammento |
| data | byte | N | Dati, relativi alla definizione specifica del pacchetto |

### Modalità di trasferimento del chunk

L'MTU attuale definito dal dispositivo pixl.js è 250. In una trasmissione di dati ATT, possono essere trasmessi fino a 247 byte di dati.

Dimensione massima del pacchetto:
L'intestazione del pacchetto fisso è di 4 byte, quindi ogni pacchetto può trasmettere fino a 243 byte. Se i dati trasmessi superano i 243 byte, è necessario trasmetterli a blocchi.

Quando la richiesta trasmessa o il risultato di ritorno supera l'MTU, è necessario trasmetterlo a chunk, e il valore del chunk aumenta di 1 per ogni trasmissione.
Quando il bit più alto del chunk è 1, significa che i dati sono ancora in fase di invio. Quando è 0, significa che i dati sono stati letti.

La scrittura e la lettura dei file richiedono l'abilitazione del trasferimento a chunk.
Il campo chunk è di 2 byte, e il flusso di trasporto a chunk può trasmettere fino a 7,8M byte.
Se supera questi 7,8M byte, è necessario aprire un nuovo flusso di trasmissione a chunk.

Ad esempio, processo di scrittura su un file:

```
c -> s: 0x12, modalità: wc, apri file
s -> c: 0x12, stato 0, id file 0xa1, il file è stato creato e può essere scritto
c -> s: 0x15, chunk 0 | 0x8000, id file 0xa1, 246 byte di dati
c -> s: 0x15, chunk 1 | 0x8000, id file 0xa1, 246 byte di dati
...
c -> s: 0x15, chunk N, id file 0xa1, 56 byte di dati
s -> c: 0x15, stato 0, scrittura completata
c -> s: 0x13, id file 0xa1, chiudi il file,
s -> c: 0x13, stato 0,
```

Processo di lettura del file

```
c -> s: 0x12, modalità: r, apri file
s -> c: 0x12, stato 0, id file 0xa1, il file è aperto e può essere letto
c -> s: 0x14, chunk 0, id file 0xa1
s -> c: 0x14, stato 0, chunk 1 | 0x8000, id file 0xa1, 246 byte di dati
...
s -> c: 0x14, stato 0, chunk N, id file 0xa1, 56 byte di dati
c -> s: 0x13, id file 0xa1, chiudi il file,
s -> c: 0x13, stato 0,
```

### Definizione del percorso

Le operazioni sui file richiedono il trasferimento del percorso completo del file. Espressione del percorso standard di Windows con lettera di unità.
Ad esempio, E:/amiibo/mifa.bin.

### tipo 

I tipi numerici sono tutti interi senza segno, modalità little endian.
La codifica della stringa è lunga 2 byte + array di stringhe, e le stringhe sono codificate uniformemente utilizzando utf8.

### Informazioni meta del file
Le informazioni meta del file vengono utilizzate per memorizzare alcuni dati relativi al file, con una lunghezza massima di 128 byte. Si distingue in base al campo tipo. I dati sono di lunghezza variabile e i dati vengono analizzati in base al tipo.

Il formato di base è il seguente:

| Nome del campo | Tipo | Lunghezza (byte) | Descrizione |
| ---- | ----- |---- | ---- |
| dimensione meta | uint8 | 1 | La dimensione di tutte le informazioni meta, 0xFF o 0 senza metadati |
| tipo meta N | uint8 | 1 | Tipo di informazione meta, definito nella sezione seguente |
| dati meta N | byte | N | La lunghezza varia in base al tipo |

I tipi attualmente definiti possono assumere i seguenti valori:

1: annotazioni amiibo
| Nome del campo | Tipo | Lunghezza (byte) | Descrizione |
| ---- | ----- |---- | ---- |
| lunghezza nota | uint8 | 1 | lunghezza nota |
| dati nota | byte | N | Stringa di note, massimo 90 byte, codifica UTF8. |

2: Proprietà del file
| Nome del campo | Tipo | Lunghezza (byte) | Descrizione |
| ---- | ----- |---- | ---- |
| flag | uint8 | N | Attributi del file, definiti a bit |

* 0b0000_0001: Il file è impostato come attributo nascosto e non verrà visualizzato sulla pagina amiibo, ma può essere visualizzato sulla pagina web. settings.bin imposterà questo flag per impostazione predefinita.
* 0bxxxx_xxxx: Altri bit sono temporaneamente non definiti.

3: attributi amiibo
| Nome del campo | Tipo | Lunghezza (byte) | Descrizione |
| ---- | ----- |---- | ---- |
| testa | uint32 | N | id testa amiibo |
| coda | uint32 | N | id coda amiibo |

Nota:
* Questo attributo è attualmente utilizzato solo in amiibo/data/*.bin ed è utilizzato per identificare rapidamente se si tratta di un file amiibo.

### Definizione del codice di stato globale

| Codice di stato | Descrizione |
| ---- | ---- |
| 0 | La richiesta è stata completata con successo |
| 0xFF | Il firmware non supporta l'attuale messaggio |

TODO Integrare il codice di errore in dettaglio. 

#Definizione del protocollo

## 0x01: Ottieni informazioni sulla versione

1. Il client invia una richiesta

| Nome del campo | Tipo | Lunghezza (byte) | Descrizione |
| ---- | ----- |---- | ---- |
| cmd | uint8 | 1 | 0x01 |
| status | uint8 | 1 | 0 |
| chunk | uint16 | 2 | 0 |

2. Il server risponde alla richiesta

| Nome del campo | Tipo | Lunghezza (byte) | Descrizione |
| ---- | ----- |---- | ---- |
| cmd | uint8 | 1 | 0x01 |
| status | uint8 | 1 | Codice di stato, vedi descrizione del codice di stato |
| chunk | uint16 | 2 | 0 |
| lunghezza versione | uint16 | 2 | lunghezza stringa versione |
| versione | byte | N | versione |

## 0x02: Entra in modalità DFU

1. Il client invia una richiesta

| Nome del campo | Tipo | Lunghezza (byte) | Descrizione |
| ---- | ----- |---- | ---- |
| cmd | uint8 | 1 | 0x02 |
| status | uint8 | 1 | 0 |
| chunk | uint16 | 2 | 0 |

2. Il server risponde alla richiesta

| Nome del campo | Tipo | Lunghezza (byte) | Descrizione |
| ---- | ----- |---- | ---- |
| cmd | uint8 | 1 | 0x102 |
| status | uint8 | 1 | Codice di stato, vedi descrizione del codice di stato |
| chunk | uint16 | 2 | 0 |

## 0x10: Ottieni lista dischi

1. Il client invia una richiesta

| Nome del campo | Tipo | Lunghezza (byte) | Descrizione |
| ---- | ----- |---- | ---- |
| cmd | uint8 | 1 | 0x10 |
| status | uint8 | 1 | 0 |
| chunk | uint16 | 2 | 0 |

2. Il server risponde alla richiesta

| Nome del campo | Tipo | Lunghezza (byte) | Descrizione |
| ---- | ----- |---- | ---- |
| cmd | uint8 | 1 | 0x10 |
| status | uint8 | 1 | Codice di stato, vedi descrizione del codice di stato |
| chunk | uint16 | 2 | 0 |
| conteggio unità | uint8 | 1 | Numero di dischi |
| codice di stato unità N | uint8 | 1 | Codice di stato disco N 0: Il disco è disponibile, non-0 disco non è disponibile |
| etichetta unità N |char | 1| lettera di unità disco |
| lunghezza nome unità N | uint16 | 2 | lunghezza nome disco |
| nome unità N | byte | N | stringa nome disco |
| dimensione totale unità N |uint32 | 4 | Spazio totale su disco |
| dimensione utilizzata unità N | uint32 | 4 | spazio libero su disco |

## 0x11: Formatta disco

1. Il client invia una richiesta

| Nome del campo | Tipo | Lunghezza (byte) | Descrizione |
| ---- | ----- |---- | ---- |
| cmd | uint8 | 1 | 0x11 |
| status | uint8 | 1 | 0 |
| chunk | uint16 | 2 | 0 |
| etichetta unità | char | 1 | Lettera di unità disco: E/I |

## 0x12: Apri file

1. Il client invia una richiesta

| Nome del campo | Tipo | Lunghezza (byte) | Descrizione |
| ---- | ----- |---- | ---- |
| cmd | uint8 | 1 | 0x12 |
| status | uint8 | 1 | 0 |
| chunk | uint16 | 2 | 0 |
| lunghezza percorso | uint16 | 2 | lunghezza percorso |
| percorso | byte | N | stringa percorso |
| modalità | uint8 | 1 | modalità di apertura |
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

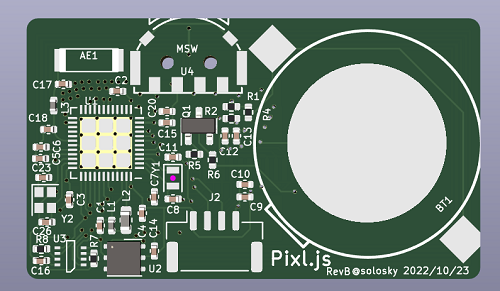
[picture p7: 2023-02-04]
assets/pixljs-pcb-revb.png

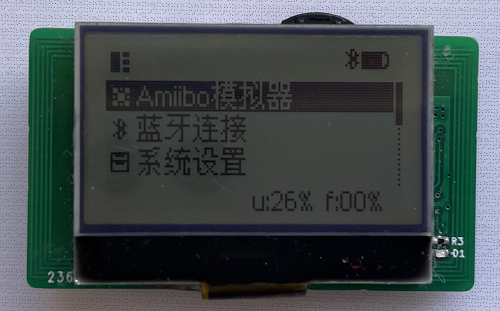
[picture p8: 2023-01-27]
assets/pixljs-1.png

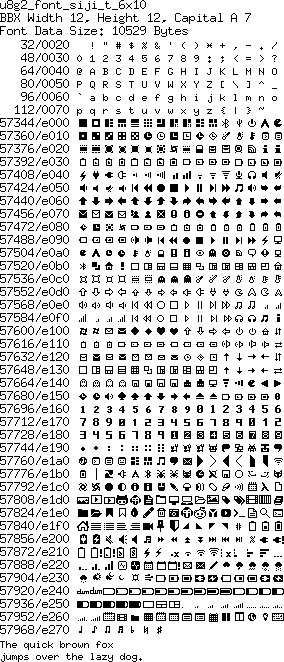
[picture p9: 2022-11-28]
fw/docs/u8g2_font_siji_t_6x10.png

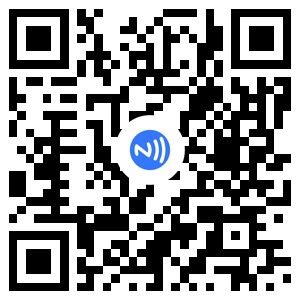
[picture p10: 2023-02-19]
assets/iNFC.jpg

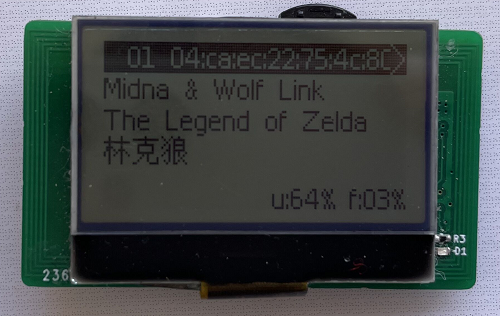
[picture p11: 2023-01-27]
assets/pixljs-2.png

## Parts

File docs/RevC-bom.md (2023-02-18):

| **Id** | **Designator** | **Package** | **Quantity** | **Designation** | **BuyLink** |
|---|---|---|---|---|---|
| 1 | R5,R3 | R_0402_1005Metric | 2 | 10K |  |
| 2 | C6,C3,C16,C2,C10,C5,C7 | C_0402_1005Metric | 7 | 0.1uF |  |
| 3 | U1 | QFN-48-1EP_6x6mm_P0.4mm_EP4.6x4.6mm | 1 | nRF52832-QFxx | [购买地址1 选NRF52832-QFAA](https://item.taobao.com/item.htm?spm=a1z09.2.0.0.2c202e8dYacXja&id=559637973772&_u=r3umvhn0387) |
| 4 | L3 | L_0402_1005Metric | 1 | 3.9nH |  |
| 5 | BT1 | BAT-SMD_CR2032-3V | 1 | Battery_Cell |[购买地址 选CR2032-3电池弹片](https://detail.tmall.com/item.htm?_u=i3umvhn3c4d&id=623218634490&spm=a1z09.2.0.0.40c52e8dLMoPVe)  |
| 6 | C11,C23,C8,C26 | C_0402_1005Metric | 4 | 12pF |  |
| 7 | U4 | MSW | 1 | MSW | [购买地址1](https://item.szlcsc.com/157238.html) \| [购买地址2 按钮两边较长，需稍微剪短](https://item.szlcsc.com/586962.html)  |
| 8 | Y2 | Crystal_SMD_2016-4Pin_2.0x1.6mm | 1 | 32MHz |  |
| 9 | R6 | R_0402_1005Metric | 1 | 1K |  |
| 10 | Y1 | Crystal_SMD_2012-2Pin_2.0x1.2mm | 1 | 32.768K |  |
| 11 | J2 | JST_GH_SM04B-GHS-TB_1x04-1MP_P1.25mm_Horizontal | 1 | Conn_01x04 | [购买地址1 选4p](https://item.taobao.com/item.htm?spm=a1z09.2.0.0.2c202e8dYacXja&id=44160307488&_u=r3umvhn75b1) |
| 12 | C4 | C_0402_1005Metric | 1 | 4.7uF |  |
| 13 | C13 | C_0402_1005Metric | 1 | 1uF/16V |  |
| 14 | C20,C15 | C_0402_1005Metric | 2 | 180pF |  |
| 15 | R8,R7 | R_0402_1005Metric | 2 | 4.7K |  |
| 16 | U3 | USON-8_3x2mm_0.5pich | 1 | GD25Q16C/ZD25WQ16BUIGR| [购买地址1 低压版 推荐](https://item.taobao.com/item.htm?spm=a1z09.2.0.0.2c202e8dYacXja&id=649864805980&_u=r3umvhn2e64) \| [购买地址2 非低压版](https://item.taobao.com/item.htm?spm=a1z09.2.0.0.2c202e8dYacXja&id=673834706188&_u=r3umvhn2527) |
| 17 | C9 | C_0402_1005Metric | 1 | 10uF |  |
| 18 | AE1 | AN2051 | 1 | Antenna | [购买地址1](https://item.taobao.com/item.htm?spm=a1z09.2.0.0.2c202e8dYacXja&id=558699169012&_u=r3umvhndb66) |
| 19 | C18 | C_0402_1005Metric | 1 | 0.8pF |  |
| 20 | C1 | C_0402_1005Metric | 1 | 1uF |  |
| 21 | C12 | C_0402_1005Metric | 1 | 1uF/25V |  |
| 22 | Q1 | SOT-23 | 1 | AO3400A |  |
| 23 | D1 | LED_0402_1005Metric | 1 | LED_Small |  |
| 24 | J1 | FPC_12 0.8mm | 1 | Conn_01x12 | [屏幕购买地址](https://item.taobao.com/item.htm?spm=a1z09.2.0.0.2c202e8dYacXja&id=660349996995&_u=r3umvhn775a) |
| 25 | AE2 | 40x22MM_NFC_ANTENA | 1 | Antenna_Loop |  |

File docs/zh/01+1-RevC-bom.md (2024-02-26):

| **Id** | **位号** | **Pa封装ckage** | **数量** | **元件名** | **购买链接** |
|---|---|---|---|---|---|
| 1 | R5,R3 | R_0402_1005Metric | 2 | 10K |  |
| 2 | C6,C3,C16,C2,C10,C5,C7 | C_0402_1005Metric | 7 | 0.1uF |  |
| 3 | U1 | QFN-48-1EP_6x6mm_P0.4mm_EP4.6x4.6mm | 1 | nRF52832-QFxx | [Purchase option #1 NRF52832-QFAA](https://item.taobao.com/item.htm?spm=a1z09.2.0.0.2c202e8dYacXja&id=559637973772&_u=r3umvhn0387)|
| 4 | L3 | L_0402_1005Metric | 1 | 3.9nH |  |
| 5 | BT1 | BAT-SMD_CR2032-3V | 1 | Battery_Cell |[Purchase Option: CR2032-3 Select battery shrapnel cell holder](https://detail.tmall.com/item.htm?_u=i3umvhn3c4d&id=623218634490&spm=a1z09.2.0.0.40c52e8dLMoPVe)  |
| 6 | C11,C23,C8,C26 | C_0402_1005Metric | 4 | 12pF |  |
| 7 | U4 | MSW | 1 | MSW | [Purchase Option #1](https://item.szlcsc.com/157238.html) \| [Purchase Option #2 The button is longer on both sides and need to be shortened slightly](https://item.szlcsc.com/586962.html)  |
| 8 | Y2 | Crystal_SMD_2016-4Pin_2.0x1.6mm | 1 | 32MHz |  |
| 9 | R6 | R_0402_1005Metric | 1 | 1K |  |
| 10 | Y1 | Crystal_SMD_2012-2Pin_2.0x1.2mm | 1 | 32.768K |  |
| 11 | J2 | JST_GH_SM04B-GHS-TB_1x04-1MP_P1.25mm_Horizontal | 1 | Conn_01x04 | [Purchase Option #1 buy 4 units](https://item.taobao.com/item.htm?spm=a1z09.2.0.0.2c202e8dYacXja&id=44160307488&_u=r3umvhn75b1) |
| 12 | C4 | C_0402_1005Metric | 1 | 4.7uF |  |
| 13 | C13 | C_0402_1005Metric | 1 | 1uF/16V |  |
| 14 | C20,C15 | C_0402_1005Metric | 2 | 180pF |  |
| 15 | R8,R7 | R_0402_1005Metric | 2 | 4.7K |  |
| 16 | U3 | USON-8_3x2mm_0.5pich | 1 | GD25Q16C/ZD25WQ16BUIGR| [Purchase Option #1 Low voltage version, recommended](https://item.taobao.com/item.htm?spm=a1z09.2.0.0.2c202e8dYacXja&id=649864805980&_u=r3umvhn2e64) \| [Purchase Option #2 Non-low voltage version](https://item.taobao.com/item.htm?spm=a1z09.2.0.0.2c202e8dYacXja&id=673834706188&_u=r3umvhn2527) |
| 17 | C9 | C_0402_1005Metric | 1 | 10uF |  |
| 18 | AE1 | AN2051 | 1 | Antenna | [Purchase Option #1](https://item.taobao.com/item.htm?spm=a1z09.2.0.0.2c202e8dYacXja&id=558699169012&_u=r3umvhndb66) |
| 19 | C18 | C_0402_1005Metric | 1 | 0.8pF |  |
| 20 | C1 | C_0402_1005Metric | 1 | 1uF |  |
| 21 | C12 | C_0402_1005Metric | 1 | 1uF/25V |  |
| 22 | Q1 | SOT-23 | 1 | AO3400A |  |
| 23 | D1 | LED_0402_1005Metric | 1 | LED_Small |  |
| 24 | J1 | FPC_12 0.8mm | 1 | Conn_01x12 | [Screen purchase option](https://item.taobao.com/item.htm?spm=a1z09.2.0.0.2c202e8dYacXja&id=660349996995&_u=r3umvhn775a) |
| 25 | AE2 | 40x22MM_NFC_ANTENA | 1 | Antenna_Loop |  |

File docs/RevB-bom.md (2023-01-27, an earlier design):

|Index|References|Value|Footprint|Quantity| Buy Link|
|-|-|-|-|-|-|
|1|C2, C3, C5, C6, C7, C10, C14, C16|0.1uF|C_0402_1005Metric|8|
|2|C8, C11, C23, C26|12pF|C_0402_1005Metric|4|
|3|C15, C20|180pF|C_0402_1005Metric|2|
|4|C17, C18|TBD|C_0402_1005Metric|2| 可不焊接 |
|5|C1|1uF|C_0402_1005Metric|1|
|6|C4|4.7uF|C_0402_1005Metric|1|
|7|C9|10uF|C_0402_1005Metric|1|
|8|C12|1uF/25V|C_0402_1005Metric|1|
|9|C13|1uF/16V|C_0402_1005Metric|1|
|10|R1, R2|100K|R_0402_1005Metric|2|
|11|R3, R5|10K|R_0402_1005Metric|2|
|12|R7, R8|4.7K|R_0402_1005Metric|2|
|13|R4|0|R_0402_1005Metric|1|
|14|R6|10|R_0402_1005Metric|1|
|15|L1|15nH|L_0402_1005Metric|1|
|16|L2|10uH|L_0603_1608Metric|1|
|17|L3|TBD|L_0402_1005Metric|1| 用0欧电阻代替 |
|18|D1|LED_Small|LED_0402_1005Metric|1|
|19|U1|nRF52832-QFxx|QFN-48-1EP_6x6mm_P0.4mm_EP4.6x4.6mm|1|[购买地址1 选NRF52832-QFAA](https://item.taobao.com/item.htm?spm=a1z09.2.0.0.2c202e8dYacXja&id=559637973772&_u=r3umvhn0387) |
|20|U2|SHT20|DFN-6-1EP_3x3mm_P1mm_EP1.5x2.4mm|1| 可选 |
|21|U3|GD25Q16C|USON-8_3x2mm_0.5pich|1|[购买地址1 低压版](https://item.taobao.com/item.htm?spm=a1z09.2.0.0.2c202e8dYacXja&id=649864805980&_u=r3umvhn2e64) \| [购买地址2 非低压版](https://item.taobao.com/item.htm?spm=a1z09.2.0.0.2c202e8dYacXja&id=673834706188&_u=r3umvhn2527)|
|22|U4|MSW|MSW|1| [购买地址1](https://item.szlcsc.com/157238.html) \| [购买地址2 需剪下](https://item.szlcsc.com/586962.html) |
|23|Y1|32.768K|Crystal_SMD_2012-2Pin_2.0x1.2mm|1|
|24|Y2|32MHz|Crystal_SMD_2016-4Pin_2.0x1.6mm|1|
|25|AE1|Antenna|AN2051|1| [购买地址1](https://item.taobao.com/item.htm?spm=a1z09.2.0.0.2c202e8dYacXja&id=558699169012&_u=r3umvhndb66) |
|26|AE2|Antenna_Loop|40x22MM_NFC_ANTENA|1|
|27|BT1|Battery_Cell|BAT-SMD_CR2032-3V|1|
|28|Q1|AO3400A|SOT-23|1|
|29|J1|Conn_01x12|FPC_12 0.8mm|1| [屏幕购买地址](https://item.taobao.com/item.htm?spm=a1z09.2.0.0.2c202e8dYacXja&id=660349996995&_u=r3umvhn775a) |
|30|J2|Conn_01x04|JST_GH_SM04B-GHS-TB_1x04-1MP_P1.25mm_Horizontal|1|  [购买地址1 选4p](https://item.taobao.com/item.htm?spm=a1z09.2.0.0.2c202e8dYacXja&id=44160307488&_u=r3umvhn75b1) |

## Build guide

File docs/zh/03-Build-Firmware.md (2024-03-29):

# 构建

## 使用Github Actions进行构建

您可以从Github Actions下载最新的构建开发版本。

https://github.com/solosky/pixl.js/actions

## 使用定制的Docker镜像进行构建

您可以使用定制的Docker镜像构建固件。

```
# 创建容器
docker run -it --rm solosky/nrf52-sdk:latest

# 下载代码
root@b10d54636088:/builds# git clone https://github.com/solosky/pixl.js
root@b10d54636088:/builds# cd pixl.js
root@b10d54636088:/builds/pixl.js# git submodule update --init --recursive

# 构建LCD固件
root@b10d54636088:/builds/pixl.js# cd fw && make all BOARD=LCD RELEASE=1

# 构建OLED固件
root@b10d54636088:/builds/pixl.js# cd fw && make all BOARD=OLED RELEASE=1
```

构建好的固件在 fw/_build/pixjs_all.hex，ota package is fw/_build/pixjs_ota_vXXXX.zip

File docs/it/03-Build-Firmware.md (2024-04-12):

# Compilazione del firmware

## Compilazione con Github Actions

Puoi scaricare l'ultima build di sviluppo da Github Actions

https://github.com/solosky/pixl.js/actions

## Compilazione con immagine Docker personalizzata

Puoi compilare il firmware utilizzando un'immagine Docker personalizzata.

```bash
# creare i contenitori
docker run -it --rm solosky/nrf52-sdk:latest

# inizializzare il repository
root@b10d54636088:/builds# git clone https://github.com/solosky/pixl.js
root@b10d54636088:/builds# cd pixl.js
root@b10d54636088:/builds/pixl.js# git submodule update --init --recursive

# compilare la versione LCD
root@b10d54636088:/builds/pixl.js# cd fw && make all BOARD=LCD RELEASE=1

# compilare la versione OLED
root@b10d54636088:/builds/pixl.js# cd fw && make all BOARD=OLED RELEASE=1
```

Il firmware si trova in fw/_build/pixjs_all.hex, il pacchetto ota si trova in fw/_build/pixjs_ota_vXXXX.zip

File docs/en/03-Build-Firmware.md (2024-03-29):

# Build

## Build with Github Actions

You could download the latest develop build from Github Actions

https://github.com/solosky/pixl.js/actions

## Build with customized Docker image

You could build the firmware using customized Docker image. 

```
# create containers
docker run -it --rm solosky/nrf52-sdk:latest

# init repository
root@b10d54636088:/builds# git clone https://github.com/solosky/pixl.js
root@b10d54636088:/builds# cd pixl.js
root@b10d54636088:/builds/pixl.js# git submodule update --init --recursive

# build LCD version
root@b10d54636088:/builds/pixl.js# cd fw && make all BOARD=LCD RELEASE=1

# build OLED version
root@b10d54636088:/builds/pixl.js# cd fw && make all BOARD=OLED RELEASE=1

```

The firmware is fw/_build/pixjs_all.hex，ota package is fw/_build/pixjs_ota_vXXXX.zip

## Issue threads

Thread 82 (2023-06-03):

请问官方版pixl.ja可以线刷这个吗？

czh00, 2023-06-03:
买了官方版ota不能刷，用线刷的可以用吗？怕刷成砖。

solosky, 2023-06-04:
可以

czh00, 2023-06-10:
用PWLINK2接的缐刷完显示成功但是不能开机了，这是砖了吗？
有无方法挽救？

solosky, 2023-06-10:
是下载最新版本固件，然后使用fw_update.bat脚本更新的吗？
n能否提供更多信息？比如截图，错误信息等。

czh00, 2023-06-10:
是下载2.6.0用fw_update.bat更新的，最后显示 "恭喜，刷新固件成功！" 没任何错误信息

solosky, 2023-06-10:
如果你是在咸鱼买的，建议找卖家售后吧

czh00, 2023-06-10:
------------------------------------------------------------------------------
Pixl.js 固件自動燒寫腳本 @solosky
------------------------------------------------------------------------------
openocd已經安裝，跳過下載
檢查openocd版本
Open On-Chip Debugger 0.12.0 (2023-01-14-23:37)
Licensed under GNU GPL v2
For bug reports, read
        http://openocd.org/doc/doxygen/bugs.html
刷新固件中，請稍後...
Open On-Chip Debugger 0.12.0 (2023-01-14-23:37)
Licensed under GNU GPL v2
For bug reports, read
        http://openocd.org/doc/doxygen/bugs.html
Info : auto-selecting first available session transport "swd". To override use 'transport select <transport>'.
Info : CMSIS-DAP: SWD supported
Info : CMSIS-DAP: Atomic commands supported
Info : CMSIS-DAP: FW Version = 1.11
Info : CMSIS-DAP: Interface Initialised (SWD)
Info : SWCLK/TCK = 1 SWDIO/TMS = 1 TDI = 0 TDO = 0 nTRST = 0 nRESET = 1
Info : CMSIS-DAP: Interface ready
Info : clock speed 1000 kHz
Info : SWD DPIDR 0x2ba01477
Info : [nrf52.cpu] Cortex-M4 r0p1 processor detected
Info : [nrf52.cpu] target has 6 breakpoints, 4 watchpoints
Info : starting gdb server for nrf52.cpu on 3333
Info : Listening on port 3333 for gdb connections
[nrf52.cpu] halted due to debug-request, current mode: Thread
xPSR: 0x01000000 pc: 0x00000a80 msp: 0x20000400
Info : nRF52832-QFAA(build code: E1) 512kB Flash, 64kB RAM
Info : Mass erase completed.
[nrf52.cpu] halted due to debug-request, current mode: Thread
xPSR: 0x01000000 pc: 0xfffffffe msp: 0xfffffffc
** Programming Started **
Info : Padding image section 0 at 0x00000b00 with 1280 bytes
Info : Padding image section 1 at 0x00018fec with 20 bytes
Info : Flash write discontinued at 0x00068930, next section at 0x00077000
Warn : Adding extra erase range, 0x00068930 .. 0x00068fff
Info : Padding image section 3 at 0x0007dc98 with 872 bytes
Info : Padding image section 4 at 0x0007e05c with 4004 bytes
Warn : Adding extra erase range, 0x0007f05c .. 0x0007ffff
Warn : Adding extra erase range, 0x10001000 .. 0x10001013
Warn : Adding extra erase range, 0x1000101c .. 0x10001fff
** Programming Finished **
** Verify Started **
** Verified OK **
-----------------------------------------------------------------------------
恭喜，刷新固件成功！
-----------------------------------------------------------------------------
請按任意鍵繼續 . . .

czh00, 2023-06-10:
espruinoespruino官方买的售后是不可能了我再找看看是否有其他方法能解决

solosky, 2023-06-10:
你是说买了这个：https://shop.espruino.com/pixljs？
如果是这个话，那和我这个固件不兼容。

您可能需要从 https://github.com/espruino/Espruino clone源码自行编译原版的Pixl.js的固件，然后通过线刷恢复。

czh00, 2023-06-10:
看来是没死透swclk/swdio接上去都还能刷只是画面不显示，正在想办法刷回官方固件。

solosky, 2023-06-10:
[espruino_2v18.25_pixljs.zip](https://github.com/solosky/pixl.js/files/11711838/espruino_2v18.25_pixljs.zip)
你试试下载这个文件解压出来espruino_2v18.25_pixljs.hex， 然后重命名为pixljs_all.hex，替换掉固件包里面的pixljs_all.hex，然后执行fw_update.bat刷新到设备试试。

czh00, 2023-06-10:
刷回官方固件了感谢支援
用你的韧体盲试了一下功能都有，似乎只是显示不匹配？

solosky, 2023-06-10:
我的固件需要适配下官方的屏幕，但因为官方没有flash，所以只能使用amiibolink模式

Closed 2023-06-13.

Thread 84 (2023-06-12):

Language change

Pocketmodster, 2023-06-12:
Hello, how do I change the language on the device to English? Thank you

Bosco1262, 2023-06-13:
I think you need to use another version

solosky, 2023-06-13:
Sorry, Pixl.js doesn't have any other language translation for both firmware and web, it only supports Simplified Chinese.

I will leave the issue open and may schedule English language support in future, but I am not promise it.

Also, pull request is welcome if you are capable of translation for English, includes firmware, web and documentations.

headhunter45, 2023-06-15:
It doesn't look like the code is setup for l10n yet. Do you have a plan or preference for how to set that up? I just started digging in, but I think I could setup something with a compile time define. I haven't looked too deep into how the settings work, but I can think of a few approaches for runtime language switching. I'm not sure on the web stuff though, maybe something similar, but I've been out of web dev for a few years now.

solosky, 2023-08-07:
Since version 2.7.0 is offically support English language now, close this issue as completed.
See #92 .

Closed 2023-08-07.

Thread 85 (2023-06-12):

Uploads not working

Pocketmodster, 2023-06-12:
Hello, please help I have an issue none of my uploads go through I only see this page and nothing else happens.
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

solosky, 2023-06-13:
Would you please to press F12 and let me know the console output if you encountered same issue again?

For iOS device, we have iNFC app that fully support Pixl.js device, you can have a try. But we dont have any compatible app on Android platform, we may support Tagmo in future.

solosky, 2023-06-13:
you can download the iNFC app by scan qrcode bellow,

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

Pocketmodster, 2023-06-13:
Yes unfortunately on the website its not working still cant figure out why and f12 doesn't show anything it only controls my pc volume. I'm trying iNFC now but I would prefer the website because my amiibo files are on my pc just makes the process easier. Thanks again for your help in the matter.

strengthen, 2023-06-14:
> Yes unfortunately on the website its not working still cant figure out why and f12 doesn't show anything it only controls my pc volume. I'm trying iNFC now but I would prefer the website because my amiibo files are on my pc just makes the process easier. Thanks again for your help in the matter.

You don't need to find Amiibo files by yourself, you can download 1026 Amiibo files directly by subscribing. It's more comprehensive than what's on your computer.
Subscribe link: https://raw.githubusercontent.com/strengthen/iNFCAmiibo/main/amiibo.infc
Video Tutorial 1: https://www.youtube.com/watch?v=X2NvyKzeaq8
Video Tutorial 2: https://www.youtube.com/watch?v=PNgcZlFqaJM

Pocketmodster, 2023-06-14:
This is what I am currently using bought it on Amazon.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

solosky, 2023-06-14:
The device looks great and should be compatible with the latest firmware.
I just recorded a simple video to demonstrate how to upload amiibo bins to the device, hope it helps your out.
One again, sorry we dont have english translation yet, but I think you can figure it out with online translator.

please let me know if you have more questions.

https://github.com/solosky/pixl.js/assets/480111/bdaad278-9bae-4519-aa91-8378f8b114f0

solosky, 2023-06-14:
Good news!
I have received an english version firmware contributed by @577fkj , though it is not build by latest code, it still worth have a try.

[Pixl_EN_B35.zip](https://github.com/solosky/pixl.js/files/11748239/Pixl_EN_B35.zip)

Pocketmodster, 2023-06-14:
Got it to work!! Thank you buddy and I appreciate all your help! I will keep the English file but I will continue to use your latest firmware file 2.6.0 since its newer. Thank you again

Pocketmodster, 2023-06-14:
But I do hope whenever you release a new firmware that it can have multilanguage selection that would be awesome thanks again buddy!

Closed 2023-06-17.

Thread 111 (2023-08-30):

Putting files inside a subfolder makes the subfoler into a zip?????

Billybobertjoe, 2023-08-30:
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

solosky, 2023-08-31:
Hi sir,

Please provide more information here, for example,

* Detail steps to produce this issue
* What is expected behavior
* What is ectual behavior

it is even better if you post screenshots or demo videos here.

Billybobertjoe, 2023-09-02:
I go to iNFC app and connect to the pixl.js and create a folder inside the amiibo folder. I then create another folder inside that. I then create another folder inside that. I then place the FOLDER containing the amiibo bin files inside that folder. That usually causes the pixl.js to make the FOLDER into a zip?

solosky, 2023-09-02:
Actually, I dont understand 'make the FOLDER into a zip', can you explain more about this ?

Billybobertjoe, 2023-09-02:
> 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

Like this.

Billybobertjoe, 2023-09-02:
The "amiibo figures" file is supposed to be a folder.

Billybobertjoe, 2023-09-02:
It is turning it into a file of some kind instead of keeping it as a folder

solosky, 2023-09-02:
Oh, I get your point, the fact is that the Pixl.js file system has limitation on its full file path for a file, like /amiibo/animalcrossing/amiibo1.bin. The total length of the file should not be exceed 64 characters, and file/folder name should not be exceed 48 characters. This limitation is introduced by SPIFFS file system.
```
#define VFS_MAX_NAME_LEN 48
#define VFS_MAX_PATH_LEN 64
#define VFS_MAX_META_LEN 128
```

Please shorten your folder name and file name, and keep the folder count minimum as you can.

Meanwhile, you can use iNFC update to latest 2.8.3, it introduce a new app called Amiibo Database with almost all amiibo files built in, you can have a try.

Please let me know if you have more questions.

solosky, 2023-09-02:
I think I will impove the error prompt in future release, sorry to make your confused.

Billybobertjoe, 2023-09-02:
Ok thank youSent from my iPhoneOn Sep 2, 2023, at 9:24 AM, solosky ***@***.***> wrote:
I think I will impove the error prompt in future release, sorry to make your confused.

—Reply to this email directly, view it on GitHub, or unsubscribe.You are receiving this because you authored the thread.Message ID: ***@***.***>

solosky, 2023-10-19:
Close the issue since there is no furthermore comments from user.

Billybobertjoe, 2023-12-03:
Another issue I am having with this is if I try to put all of the animal crossing amiibo .bin in a single folder, the device just crashes right when I try to enter that folder on the device. I don’t know how to fix that due to the issue we were talking about.

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

Closed 2023-10-19.

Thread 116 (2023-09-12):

Crash when accessing the emulator menu after having used the database

DanTheMan827, 2023-09-12:
Firmware v2.8.4

Accessing the emulator menu results in a crash if the database menu was previously accessed.

https://github.com/solosky/pixl.js/assets/790119/e441b5ee-a973-433b-a682-2129d1ee3e18

solosky, 2023-09-12:
Hi , I am also noticed this bug , it can be reproduced by my device.

This issue seems related to memory allocation issue, maybe some memory region is corrupted. It’s kind of hard to address this issue.

Thank you report the issue, I will continue working on this.

impeeza, 2023-10-20:
@solosky and @DanTheMan827 Sorry for beeing that guy, but on my device (allmiibo) with FW 2.8.5 this error still happen.

Even just now learning and playing with the "Amiibo Database" after a while on it when selecting the "Exit"  the device restarted also.

solosky, 2023-10-21:
I will let the issue opened, and I still cannot figure out how to fix the issue...

jumkey, 2023-10-21:
@solosky 我之前测试了下 把tlsf_free 换成普通的free就不会崩。好像是clear favlist的时候调用了free

solosky, 2023-11-18:
Hi everyone,

I think I finally fixed this issue, would you please have a try the fix version: https://github.com/solosky/pixl.js/actions/runs/6911499606

impeeza, 2023-11-18:
wow will tried just now and worked great.

Closed 2023-11-19.

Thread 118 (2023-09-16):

Upload via BLE File Transfer

Brickleberry19, 2023-09-16:
When I try to load Amiibo onto it, it mostly doesn't work.  It says that GATT is currently working or it stays at 89%.

Edit: i use the Website

Brickleberry19, 2023-09-16:
My Laptop is the Problem, i can Upload them With my Smartphone without any problems

solosky, 2023-10-19:
Hi, the BLE antenna is not tuned for best performance currently due to my knowledge and device limitations.
It's barely just "usable" for BLE transmission.
But it should have better BLE transmission speed and stability when using Mobile device connects to Pixljs with BLE connection, because the antenna for Mobile device seems has been optimized for best performance and sensitivity.

Closed 2023-10-19.

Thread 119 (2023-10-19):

Backup Current Firmware / Files

impeeza, 2023-10-19:
Hello there, I just Acquire a pre-made kit named «allmiibo» as far I can see is highly based on the original Pixl.js hardware, as far I can see it have a "modified" 2.6.2 firmware and is on English language.

Actually the device shows the next on System Settings -> Version
```
Version [2.6.2]
BuildDate [2023-07-2
GitHash [0783e4d]
Branch [main]
Target [0]
Dirty [1]
```
I want to install newer pixl.js firmware on it but thinking what the firmware and hardware could be very different from the original design, I like to have a backup of the current status of the device in order to be able to return to a well know working state.

How can this be achieved?

Thanks a lot for all your help.

impeeza, 2023-10-19:
Thanks a lot for the quick response.

Perfect, the upgrade process seems straightforward, but I really like to have a copy of the actual firmware in case something goes wrong I will be able to go back to the actual state.

Regards.

impeeza, 2023-10-20:
Hello there, I just updated the firmware to 2.8.4, and works fine, testing all features and so far working well, The only issue is what now all description tags of all amiibos are on Chinese, even if the language settings are on English, on the original firmware all descriptions was on English.

Thanks a lot for your responses and help.

solosky, 2023-10-20:
Hi, the language of tag description should be English if you choose English in setting menu.
Would you please to post more information, like screenshot to let me have better understanding the issue?

impeeza, 2023-10-20:
Hello there, I think I get confused myself, lets try to unravel my mind :P

My settings are like this:
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

so If I go Main Menu -> amiibo Emulator
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
I got into a "File Explorer", entering on the "amiibo" folder
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
and then into other folder:
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
I can select a amiibo bin file:
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
And for that amiibo the description tag is on English:
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

but if I go to amiiboLik folder and select one of the files on that folder
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
The details of that file are on Chinese:
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

Also if on the Main Menu I go to AmiiboLink
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

And then Select one of the files:
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

The Tag details also are on Chinese:
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

therefore, seems is a problem with the files on the AmiiboLink folder, the ones transferred by the AmiLoop app.

solosky, 2023-10-20:
Hi, interesting findings, I will try it later, because I don't have device on hand now.

BTW, you can try the Amiibo Database app, it contains almost all released amiibo information, and generate amiibo data on the fly. Also, it has more detail description for Zelda game series amiibos.

impeeza, 2023-10-20:
Hello there, I just downloaded and install on my android phone the Umiibo app, and transfer some bin files on AmiiboLink mode and the descriptions are on chinesse :(

The Amiibo Database App is Umiibo?

solosky, 2023-10-20:
No, I mean the app in Pixl.js.

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

solosky, 2023-10-20:
Hi, I confirmed it's a bug.
The tag description did not honor the language settings.
I will release a new version later today to fix this issue.

Thank your report on this.

solosky, 2023-10-20:
Hi, there, please update firmware to 2.8.5 to fix this name issue.

impeeza, 2023-10-20:
@solosky sorry for ping a closed issue, I still have the doubt about the " Amiibo Database app" you mentioned on a message above.  which one is that app?  thanks.

impeeza, 2023-10-20:
> No, I mean the app in Pixl.js.
>
> 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

Thanks, learing about that section, great addition to the device.

wouter-luimes, 2023-11-10:
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

Sorry to bother you, but were you able to obtain a copy of the firmware that originally came with the device in the end? And if so, would you be able to share it? I have this same device myself and also would like to have a back-up just in case.

impeeza, 2023-11-10:
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

No, I was unable but never needed, the device works very well with 2.8.6 firmware and the improvement are welcomed.

Closed 2023-10-20.

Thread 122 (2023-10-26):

Menu Animation Will not Turn Off

BladeTechBlade, 2023-10-26:
on version 2.8.5 i like the new update but what is menu animation and how do i turn it off

BladeTechBlade, 2023-10-27:
Because it will not turn off it stays on.

solosky, 2023-10-28:
Sorry, tested via LCD and OLED version, but I cannot reproduce this issue, would you please provide detail step on how to reproduce this issue?

BladeTechBlade, 2023-10-28:
What I mean is the reason why I wanted to turn it off is because on version 2.7.0 it is faster with it on so scrolling through the amiibos faster But when doing it with the 2.8.5 it is running slower to scroll show yeah so that's why I need it off to see if it made it get faster otherwise I might have to switch between 2.7.0 and then to the latest But for safety I only switch between 2.7.0 and 2.8.4 till it has been resolved.
 I got some good ideas that you could have when you run the new version  Give us some options like to turn off the menu Thing but when I add my amiibos I don't like the fact that I have to I have to  Rename my own amiibos Can you do an app to rename the amiibos but with the 63 character limit for each of them please because rename in them is gonna take a while to do because I have the entire collection from which I own and IM using this device to store them on and on the device is so good I would Cause I've had to shorten the names just to put them on so then the scrolling does help a bit but not fully like when I go into was at 2.8.5 the database It is also slow when it is under the latest version to show me the amiibos items and what you get is a good that I want to use that Feature Or add my allmiibo zero with lcd screen is what I got.
If you need pictures sent please ask me but a video would be better it would take time to do it because I would have to but firmware back on to show you.

solosky, 2023-10-28:
You can turn the animation via "Menu Animation" menu in Settings if you feel the animation is annoy.

Regarding the 63 name limitation, sorry for that, but it's a limitation from SPIFFS, you can try to name the folder as short as possible, so there may be small amont of amiibo names that requires shorten its file name.
Another way is that using some file rename tools to rename your amiibo files.

Amiibo database is another choose for amiibo file generation and emulation, you can have a try.

I want highlight that, the change between 2.8.5 and 2.8.4 is a minor bug fix change,  I dont think so it will impact your scrolling speed if you upgrade your device from 2.8.4 to 2.8.5.

x7l7j8cc, 2023-10-28:
@BladeTechBlade To be able again to Set the Menu Animation, just:
1. Connect via "Web Bluetooth Transmission" and Delete the **settings.dat** file in the **_External Drive_**.
2. Reboot. And you should have the setting set to OFF, and now you can turn on or off as you wish.
Obviously, you need to set the language and backlight again.

impeeza, 2023-10-30:
Hello there, for me was the settings.bin file which have the value of 03 on the 0x0C offset, after delete the settings.bin file, and put the same settings like before I got these values:
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
the file at the left is the recreated settings, and the one on the right is the original one which doesn't allows to change the Menu Animation Setting.

the 0x28 value on 0x0B offset I don't know what means.

solosky, 2023-10-30:
The 03 on the 0x0C should be the bool anim_enabled, it should be 1 or 0, 3 is wrong value here(I don't know why 3 is here..).
0x28 is oled constract..
just for your reference, the settings.bin layout as bellow:
```
typedef struct {
    bool backlight; //deprecated, keep for capability issue
    uint8_t sleep_timeout_sec;
    bool dirty;
    bool auto_gen_amiibo;
    bool auto_gen_amiibolink;
    bool skip_driver_select;
    bool bat_mode;
    ble_amiibolink_ver_t amiibo_link_ver;
    bool hibernate_enabled;
    bool show_mem_usage;
    uint8_t lcd_backlight;
    uint8_t oled_contrast;
    bool anim_enabled;
    Language language;
    uint8_t amiidb_data_slot_num;
} settings_data_t;
```

Deleting the settings.bin to solve this issue should be fine, because the settings.bin will be saved when first time to go sleep.

BladeTechBlade, 2023-10-31:
Do you need what is showed in the text if you already deleted the settings.bin

solosky, 2023-10-31:
> Do you need what is showed in the text if you already deleted the settings.bin

sorry, I didn't get your question. Please explain a bit more?

solosky, 2023-10-31:
Not need, the device should be set to default value 0.

BladeTechBlade, 2023-11-09:
Thanks that has explained what I have asked for.

impeeza, 2023-11-09:
So, the issue can be closed now?

BladeTechBlade, 2023-11-10:
> So, the issue can be closed now?

Yep all done asking this questions.

BladeTechBlade, 2023-11-10:
⅚

BladeTechBlade, 2023-11-10:
Bye

impeeza, 2023-11-10:
he hehe, please close the issue :D

BladeTechBlade, 2023-11-10:
Thanks for everyone's help

scottjl, 2023-11-20:
2.8.7, still can't get the option to turn off. tried deleting settings.bin as recommended by @x7l7j8cc but doesn't seem to work. maybe add an option to reset all settings, or during firmware upgrade reset them? thanks!

solosky, 2023-11-20:
> 2.8.7, still can't get the option to turn off. tried deleting settings.bin as recommended by @x7l7j8cc but doesn't seem to work. maybe add an option to reset all settings, or during firmware upgrade reset them? thanks!

Delete the settings.bin has the same effect with reset all settings.
I still cannot reproduce this issue.
If you know how to reproduce this in detail, please let me know.

scottjl, 2023-11-20:
> Delete the settings.bin has the same effect with reset all settings.
> I still cannot reproduce this issue.
> If you know how to reproduce this in detail, please let me know.

deleting the file does nothing for me. actually i'm not even sure the file gets deleted because after i delete it and have the unit reset, i would expect the language to default back to chinese (?) but it doesn't and all my other settings are intact. it doesn't seem like the file is actually being deleted. i even tried to "format disk" and the settings persist.

not sure how to reproduce the issue, since it's been like this since i got my unit a week ago. i updated to 2.8.6 and 2.8.7 and it's still present.

i can also verify 0x0C is 03 on my unit. i've tried changing it and up-loading the altered file, but that doesn't seem to work either. after resetting and downloading the file, it's still 03.

if i had to guess, i'd say a handle to the file is still open from the OS and doesn't seem to let me overwrite or delete the original file. i need some way to force it closed to alter it outside of the settings menu. might just be easier to put in a check for a value of 0x0C of any value other than 0 or 1 and if found, force it to 1.

solosky, 2023-11-20:
can you try delete in the web portal ?

scottjl, 2023-11-20:
deleted via web portal (with Chrome). file looks deleted. went to settings and reboot. menus are still in English, still unable to toggle animation off.

solosky, 2023-11-20:
after delete from portal, try click refresh button to see is the file still exists or not

scottjl, 2023-11-20:
> after delete from portal, try click refresh button to see is the file still exists or not

it does not.

i delete file. refresh. then take unit out of BLE file transfer, go to settings, reboot.

scottjl, 2023-11-20:
for what it's worth, this is the unit i purchased. https://www.aliexpress.us/item/3256805821225710.html though mine looks slightly different and says 'allmiibo' on it. it loads pixl.js and runs it fine, except for this one issue. i have upgraded it using iNFC on iOS after downloading 2.8.6 LCD through the app and once downloading 2.8.7 LCD directly from this repo, saving it to iNFC and updating manually.

impeeza, 2023-11-20:
Ok, please do the Next, put the device in BLE File Transfer mode, and open https://pixl.amiibo.xyz/ then connect the device and share with us a screenshot of the root folder of flash storage.

then download settings.bin and share it with us.

select the settings.bin file with a tick on the left, then use the upper red button "DELETE".

restart the device from the settings  and repeat all again. thanks.

impeeza, 2023-11-20:
@solosky I don´t know if this could be a bug, if you change the settings.bin file on BLE File Transfer mode, when the device is reboot from settings menu, the just uploaded file is replaced by the one on memory.

impeeza, 2023-11-20:
I don´t know if put a code to reload the settings.bin file once you exit BLE File Transfer app, or recreate the default one if was deleted.

scottjl, 2023-11-20:
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
scottjl, 2023-11-21:
well if it happens to me again i know how to fix it. maybe add this as an item to a FAQ/Wiki in case someone searching for help doesn't find it here.

impeeza, 2023-11-22:
Hello there, I think I just find something weird:

The Aliexpress's Allmiibos devices comes with a custom 2.6.2 firmware, that firmware has been modified to some languages (Spanish, Italian, English and Chinese) they sell that variations, you can not change the language.

The settings.bin file included on that device is ONLY 15 bytes long:
[settings_bin.zip](https://github.com/solosky/pixl.js/files/13432609/settings_bin.zip)

As you can see the offset 0x07 is 0x03 on that file.

----

To reproduce the problem I just made the next:

Using BLE Transfer File Mode, deleted the current settings.bin file, then put the device on DFU mode.

After timeout the default settings are on the device (looking on the menus):

Sleep Timeout Timer	30 Seg.
Automatic Random	ON
Auto Random AmiiboLink	OFF
Auto Storage		OFF
LiPO Battery		OFF
AmiiboLink Mode		V1
Fast Resume		OFF
Show Memory Used	OFF
Backlight Brightness	OFF
OLED Contrast
Menu Animation		OFF
Language		ZH_HANS(简体中文)
Amiibo Slot Num.	20

If after the timeout you immediately go to BLE File Transfer again, there is no settings.bin file on the root of the Flash Storage.

Changed the language to English, to test, and reboot the device,  a new 16 bytes settings.bin file is created.

Now on BLE File Transfer, Using red DELETE button erased the settings.bin and uploaded the "original" 15 bytes settings.bin, the again entered on DFU mode.

After the timeout on the device is on Chinese, then started BLE FT again and the 15 bytes settings.bin file is still on the root of flash storage.

exit the BLE FT mode and reboot the device, now the settings.bin file is 16 bytes long.

Now go to settings, and try to change the menu animation and stays OFF no matter how many times I press the middle button:

https://github.com/solosky/pixl.js/assets/41979604/4b9a28b9-5a69-41b1-87b3-2d0207917e6a

go to BLE F T and delete the settings.bin file, restarted the device and no avail still no able to change menu animation.

the only way to be able is going to BLE F T mode, delete the file and then going to DFU mode, after that again a default settings.bin file is created and now you can change the menu animation settings.

impeeza, 2023-11-22:
Extra test,

Downgraded the device to 2.6.2 firmware, deleted and restarted (battery) the settings.bin file, a new settings.bin file 11 bytes long is created:

[settingsDefault262.zip](https://github.com/solosky/pixl.js/files/13433280/settingsDefault262.zip)

then upgrade to 2.8.7 and after a new reboot, a settings.bin file with 16 bytes size is created
[settings.zip](https://github.com/solosky/pixl.js/files/13433284/settings.zip)

the correct 0x07 offset is set up.

Definitively the problem is with the settings.bin file included with the Alliexpress allmiibo device which have the 0x03 value on 0x07 offset.

But is weird what if you delete the settings.bin file on the BLE File Transfer mode is recreated exactly the same after reboot.

Closed 2023-11-21.

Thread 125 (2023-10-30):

Spanish Translation

impeeza, 2023-10-30:
Hello there,

I am working on a «es_CO.c» containing the Spanish translation of the «en_US.c» file which could be used to extend the languages of the device.

The problem I am facing right now are the special characters, because on Spanish we use «á é í ó ú ñ Á É Í Ó Ú Ñ» but even if the file «es_CO.c» that characters are encoded on UTF-8 are not displayed by the device.

I am not an expert programmer so trying to understand the code is hard to me.

Can you please tell me which characters should be on the file to that symbols get displayed on the device.

I am attaching the file I have so far, I am using the code es_CO to indicate Spanish - Colombia, but is the equivalent of 419 (Spanish Latam) I don't know which is the correct code.

[es_CO.c.txt](https://github.com/solosky/pixl.js/files/13202255/es_CO.c.txt)

solosky, 2023-10-30:
Hi, just let you know, I have updated the spanish translation in branch *spanish*, but unfortunately the special charaters still cannot be rendered correctly, I will make further invertigation to find out a solution if I am available.

impeeza, 2023-10-30:
Hello, as far I could look into the code, the FW is using the fonts
siji_t_6x10, wqy12_t_gb2312a & wqy12_t_gb2312a_lite

this are the codepages?
Siji:
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

WQY12 t gb2312a:
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

What I don't finish to understand is how you convert the .c file onto UTF-8 to that code page.

Regards.

solosky, 2023-11-05:
Hi, I finally resolved the issue and the Spanlish is supported by develop firmware version, you can download the latest auto build firmware [here](https://github.com/solosky/pixl.js/actions/runs/6760673380)  to have a try.

solosky, 2023-11-05:
Hi, I finally resolved the issue and the Spanlish is supported by develop firmware version, you can download the latest auto build firmware [here](https://github.com/solosky/pixl.js/actions/runs/6760673380)  to have a try.

impeeza, 2023-11-05:
Seizing the opportunity, I used the webpage to upload the DFU update, and worked perefectly.

Tested the new menus and translation and I am very happy.

the only tweak will be the one expressed on: https://github.com/solosky/pixl.js/issues/124#issuecomment-1793834105

solosky, 2023-11-06:
Updated as your suggestion, you can download new firmware from [here](https://github.com/solosky/pixl.js/actions/runs/6772097763)

impeeza, 2023-11-06:
Perfect!

Thanks for all your work

Closed 2023-11-06.

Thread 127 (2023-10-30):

Web pages translation

impeeza, 2023-10-30:
Hello there, working on the firmware Translation I take to oportunity and translated the files of pixl.amiibo.xyz page, I took the files from SourceCode:/gh-pages and modify them, I don't know if having different set of files for each language, or if the files could be changed to be multilingual.

Also I don't know if the edition goes directly on the files
- pixl.js-main\gh-pages\index.js
- pixl.js-main\gh-pages\manifest.js
- pixl.js-main\gh-pages\vendor.js

or the text should be edited on other set of files.

In order to edit that files I did use a javascript Beautifier to get a more editable code.

I am attaching the set of files on English and Spanish
[gh-pages_ES.zip](https://github.com/solosky/pixl.js/files/13210349/gh-pages_ES.zip)
[gh-pages_EN.zip](https://github.com/solosky/pixl.js/files/13210350/gh-pages_EN.zip)

Let me know if I can help more.

solosky, 2023-10-31:
The content in gh-pages is built from vue web project (web directory).
You should not update the content in gh-pages, you should edit the vue files in web directory instead.

The site is a vue project, currently this project is not support i18n translation, you may introduce [Vue-i18n](https://vue-i18n.intlify.dev/) to have better i18n translation support.

impeeza, 2023-10-31:
Will search and learn what VUE is it😸

impeeza, 2023-10-31:
Hello there, vue.js is giving me a hard time.  so far using the files on SourceCode:/web/ I extract the needed strings to internationalize the webpages, I am Attaching a Spreadsheet with the location and strings:
[Strings.ods](https://github.com/solosky/pixl.js/files/13221995/Strings.ods)

impeeza, 2023-11-01:
Hello everyone, Just was able to build the Web Page, so after some attempts I got two set of Web Pages one on English other on Spanish.

Also Found what the code on the file «App.vue» after line # 350 is lacking of the names for the «Accept» & «Cancel» buttons, so always the default Chinese names are used.

So I modified the file like this:
Orignal one:
```    on_upload_diag_close(done) {
      this.$confirm('确认关闭？关闭将清空上传记录。')
        .then(_ => {
          this.$refs.upload.clearFiles();
          this.reload_folder();
          done();
        })
        .catch(_ => { });

```

And add the lines:

```
    on_upload_diag_close(done) {
      this.$confirm('确认关闭？关闭将清空上传记录。')
        confirmButtonText: '确定',
        cancelButtonText: '取消',
      })
      .then(_ => {
        this.$refs.upload.clearFiles();
        this.reload_folder();
        done();
      })
      .catch(_ => { });
    },

```

and after modifying the file, created this two files:
[AppEN.vue.txt](https://github.com/solosky/pixl.js/files/13223479/AppEN.vue.txt)
[AppES.vue.txt](https://github.com/solosky/pixl.js/files/13223480/AppES.vue.txt)

But could be better to modify the file to use external defined variables, or having a combo or buttons to select the different languages.

Additional there are some text I couldn't translate because seems not to be defined on the app, and maybe using default values from the modules or somewhere else:

Creating a new folder failed:
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

Error renaming a object because new name too long:
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

When there are no data:
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

The last version of the strings changed are summarized on the file
[Strings.xlsx](https://github.com/solosky/pixl.js/files/13223490/Strings.xlsx)

impeeza, 2023-11-01:
Found the text about "No Data" on a empty table, looking on the page https://element.eleme.io/#/en-US/component/table realize what the property `empty-text` have the value, so needs to be added to the code.

The line 46 of the file `App.vue`, actually have:

```      <el-table ref="multipleTable" :data="tableData" tooltip-effect="dark" style="width: 100%" v-loading="table_loading"````

and if you add ` empty-text="No Data" ` to the header the text is customized.
```      <el-table ref="multipleTable" :data="tableData" empty-text="No Data" tooltip-effect="dark" style="width: 100%" v-loading="table_loading"````

Also I am trying to understand https://element.eleme.io/#/en-US/component/i18n about internationalization of `vue` projects.

solosky, 2023-11-02:
Hi, glad you have made such great progress. It looks promising and goes on the right way.
I am waiting for you further progress update.

impeeza, 2023-11-02:
I am trying to understand how i18n works on vue & element but I am not really a javascript programmer and I am a little lost.

Which framework or editor are you using for the web project?

solosky, 2023-11-02:
definitely vscode.
I use vscode for web developing and firmware developing both.

impeeza, 2023-11-02:
Ok, Got more lost here, but will try to learn something.

impeeza, 2023-11-05:
Well, As my first venture on a "real" programming (I do normally only do VBScript and Powershell) I just made the Pull request https://github.com/solosky/pixl.js/pull/128 to add the changes on the Web page Pixl.js

Was a learning journey, a good one.

I tried to be respectful with the actual programming syntax and style.

The file `zh_TW.js` so far is a copy of `zh_Hans.j`s because my Chinese skills are null and ask you to made the needed changes to the file.

@solosky please review the proposal and let me know if the changes are suitable to final product.  I did take the freedom of made some little changes on the code no related to language and hope they aren't too intrusive.

I made some test to the page on with my device but some scenarios couldn't be tested.

Hope this PR will be useful on the future.

solosky, 2023-11-05:
The PR looks promising, it's a great enhancement for the web application.
I am working on your PR, and if no issue is found, I will deploy to online.

Again, thank for your great contribution on the Pixl.js project.

solosky, 2023-11-05:
Hi sir,

Thank your great contribution, the i18n support of web site is deployed to live now,  you can preview the site with links bellow:

* https://pixl.amiibo.xyz/
* https://solosky.github.io/pixl.js/

I also have do some update and fix some bugs to have better user experience for this great enhancement:

  1. Language drop menu always show same content
  2. Save language selection to cookies as preference
  3. zh_TW transalation via ChatGPT!
  4. update npm dependecies in package.json

Please let me know if you have futher comments.

Once again, thanks for your contribution to the Pixl.js project!

impeeza, 2023-11-05:
Wow that was quick, excellent catching on that label what eluded my eyesight 😄
The cookies is a very nice addition, I was afraid of use them.  even the cookies will easy the detection on the connected_version button.

Thanks a lot for all your work.

Regards From Colombia.

impeeza, 2023-11-05:
Sorry, for reopen, I just spotted a strange bug, let walk trought the steps to reproduce it:

Started with a "incognito" browser tab and open https://pixl.amiibo.xyz/ or https://solosky.github.io/pixl.js/

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

as you can see the default language is zh_CN, cool, but the "Connect" button, is on English (my browser language), so if you select using the dropdown a different language, everything is ok:
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
but if you press ctrl+F5 to refresh the page, again the connect button get in to the browser language, by example on a English browser and last selected language: "Spanish":
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
or a Spanish browser and last selected language: "English:
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

Again Thanks a lot for your great work, Big Left Hand Shake from Colombia.

impeeza, 2023-11-05:
Thinks the bug was introduced by me on the web\src\i18n\index.js with the code managing the logic of selection of the default language, at first it checks and if not default language uses browser one, think the cookies should be tested there also. maybe.

solosky, 2023-11-05:
The issue is resolved and deployed to live.

impeeza, 2023-11-05:
Thanks a Lot, works like a charm 🐱

Closed 2023-11-05.

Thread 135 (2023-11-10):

some amiibo is not sending over to my allmiibo zero

BladeTechBlade, 2023-11-10:
At the moment I am sending a few amiibos at a time But for the animal crossings are not being Uploaded because it keeps saying error on some off them.

solosky, 2023-11-10:
Please provide details on how to reproduce this issue.
short video/images are welcome to post here to let me know what issue are you facing.

BladeTechBlade, 2023-11-12:
I got it working it seems that the device does not like long names and having the same name that folder was in like Animal Crossing x Sanrio Series and I had to short it to sanrio.

impeeza, 2023-11-12:
Can to give us a example of your names to try to control that on the firmware

Closed 2023-11-12.

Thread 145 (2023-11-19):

Any way to fix after flashing wrong firmware?

toaks2804, 2023-11-19:
Hello. I accidentally flashed the OLED firmware to the LED version. The screen lights up but there is no menu visible. Any way to save this?

impeeza, 2023-11-19:
you could try to move (blind) by the menus and put the device on the DFU mode, or use the wired mode to reprogram the device.

From the Main Menu you can put the device in DFU mode pressing:

_press any button to wake up the device, then press:_

- LEFT
- MIDDLE
- LEFT X 3
- MIDDLE

(Also to be sure you are on the MAIN MENU, you can remove and put the battery, then start the process above)

Open the page https://thegecko.github.io/web-bluetooth-dfu/examples/web.html load the `pixjs_ota_vXXX.zip` file for the LCD and open it, then press the `SELECT DEVICE` button and if your device is on DFU mode you should see a device called `pixl dfu` connect to it and the process should be finish well.

Also, from main menu you can press:

- LEFT x 2
- MIDDLE
then you are en BLE uplad mode then in https://pixl.amiibo.xyz/ page, you can connect and use the button `DFU` to put the device in DFU mode and programming again.

**For wire programming:**
This method requires the additional purchase of a CMASS-DAP compatible downloader. We recommend pwlink2 lite for 9.9 yuan.
Purchase address: https://item.taobao.com/item.htm?spm=a1z09.2.0.0.4b942e8deXyaQO&id=675067753017&_u=d2p75qfn774a

- Download the latest version of the firmware zip package and use JLink or DAPLink to program pixjs_all.hex.
- After connecting the cable, double-click `fw_update.bat` to program the firmware.
- After programming is completed, subsequent firmware updates can be updated via OTA.
- You can also use OpenOCD to program.
```
openocd -f interface/cmsis-dap.cfg -c "transport select swd" -f target/nrf52.cfg -d2 -c init -c "reset init" -c halt -c "nrf5 mass_erase" -c "program pixjs_all. hex verify" -c "program nrf52832_xxaa.hex verify" -c exit
```

toaks2804, 2023-11-19:
Thank you! That fixed it!!

solosky, 2023-11-19:
@impeeza That's very detailed instruction, I will put your answer to docs,  thanks.

MayanKoyote, 2024-03-28:
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

looks like in case of modern FW 3rd step will be 'LEFT X 4' instead of 'LEFT X 3'

impeeza, 2024-03-29:
Yeah on newer firmwares that has changed a little bit.

R9anSmart, 2025-02-01:
Hi all,
I have also managed to make the classic mistake of flashing OLED to LED.

I have managed to flash the LED firmware which now gets the backlight working again but now I have nothing at all showing on screen. I am unable to remove the battery as it is soldered to the board so I will have to run the battery down to get to a known position in the menus.

What I really need to know is - why did the OLED or LED firmware work and how do I get back to a working state?

Thanks in advance

MayanKoyote, 2025-02-01:
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

impeeza, 2025-02-16:
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

Please read the description of the release for latest firmware:

https://github.com/solosky/pixl.js/releases/tag/2.12.0

> For LCD versions, if the screen appears too faint after updating, you can reset the settings by following these button presses after the device enters standby mode: Middle, Left, Middle, Right (x3), Middle, Right (xN) until the screen becomes clear. Set the contrast to 80.

R9anSmart, 2025-02-16:
I think what I did is flash a older version of the firmware and the flashed the latest. For some reason that worked. Maybe reset contract controls doing that somehow

Closed 2023-11-19.

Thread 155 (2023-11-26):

Unable to toggle menu animation

mbarszcz-pcb, 2023-11-26:
Running version 2.8.7, the menu animation setting under settings doesn't toggle between on and off, it is just on all the time.

solosky, 2023-11-26:
please refer to https://github.com/solosky/pixl.js/issues/122#issuecomment-1822001413 for solutions.

impeeza, 2023-11-26:
duplicated issue, read #122 and please close the issue.

Closed 2023-12-01.

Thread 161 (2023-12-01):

Reset Default Setting  bug

impeeza, 2023-12-01:
The new option in settings "Reset Default Setting" It's a great addition. I think I found a bug,

If you go to settings ->  Reset default settings and then you select Back to Main Menu, The device seems to reboot, but the current language of menus and most of the previous settings are still in place, however if you go to settings app again, the default values are shown on each item, only after a system reboot the default settings enter in place

Video and first report on the Discord channel>
https://discord.com/channels/1146978069609975890/1146978069609975894/1180058782047408158

solosky, 2023-12-03:
fixed in https://github.com/solosky/pixl.js/commit/9136d02c8f26e62698c1f923f3818814dde21a9e

impeeza, 2023-12-03:
Wow!, thanks.

Closed 2023-12-03.

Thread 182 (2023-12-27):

没有打开LiPo锂电池选项，右上角一直显示的是满电，用户不知到要充电，电池过放后，导致无法充电进去。希望默认打开LiPo锂电池选项

strengthen, 2023-12-27:
没有打开LiPo锂电池选项，
右上角一直显示的是满电，
用户不知到要充电，
电池过放后，
导致无法充电进去。
希望默认打开LiPo锂电池选项，
或者没有打开LiPo锂电池选项，右上角也可以看到电量。

impeeza, 2023-12-27:
Seems the default settings.bin file shipped on the OLED devices have no the LiPo option enabled by default the user can go and change manually, and then restart the device and the battery level is now updated correctly

solosky, 2024-01-10:
Released in 2.9.2.

Closed 2024-01-10.

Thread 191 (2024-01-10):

German language file

Ulfenknulfen, 2024-01-10:
thers a small problem in german laguage file:

"AUF" war wrong - it must be: "AUS"

problem fixed in attached file.
Please use it

thx
Paddy
[de_DE.zip](https://github.com/solosky/pixl.js/files/13891009/de_DE.zip)

impeeza, 2024-01-10:
The https://github.com/solosky/pixl.js/pull/192 is created using this file.

solosky, 2024-01-13:
Rleased in 2.9.3
Thanks for your contribution!

Closed 2024-01-13.

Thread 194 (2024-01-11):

Optimize memory consumption of language supports

fishybow, 2024-01-11:
While exploring locally, I discovered that adding more languages (and the corresponding translations) would cause the Chameleon app to crash, especially when the tag type is set to Mifare 4k.

I cannot be certain of the cause, but my suspicion is that the crashes were due to out of memory. As it stands right now, all translation strings are loaded into memory because they are statistically compiled into the executable.

Action Items

- We should stop adding more languages until this investigation concludes.
- We should consider removing some of the less popular languages that have already been added.
- We should research into a better localization approach to reduce its memory footprint. The ideal case would be only the active language is loaded into memory. The translation of other languages should exist in the form of files (either in the internal storage or the external storage). One of those files is loaded on-demand as the user picks the corresponding language.

solosky, 2024-01-11:
HI @fishybow, you are correct, the language const should be put into text section but somehow the linker put them into text section, see screen bellow.
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

solosky, 2024-01-11:
Thank your information, I have fixed this issue in #[7355f93](https://github.com/solosky/pixl.js/commit/7355f9301426221f87643cdf1d33b26f4229a998)
All language string now puts into the text section, no memory is consumed.
It's a simple and tidy solutions for this issue.

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

solosky, 2024-01-11:
Hi @fishybow , regarding the crash when enter Chameleon app, I think I have fixed that issue in commit https://github.com/solosky/pixl.js/commit/01d2c975c7f6156e143491a0fa93a0a14745c3b6, can you have a try the latest develop firmware and confirm the issue still did exist or not? (You can download develop firmware in Github Actions tab).

The issue seems not related with the language files. Anyway, the current language translations still can compile to final firmware, because a language file only occupied 0x294 bytes in flash, that's still acceptable.

fishybow, 2024-01-11:
Great thanks for the reply. Marking this as resolved.

Closed 2024-01-11.

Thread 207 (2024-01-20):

Reset device confirmation

PonyOny, 2024-01-20:
I purchased a "Allmiibo" some days ago, I have been updating it to the latest version several times since purchased, I don't know if this is something that only happens to me on my device but the "Top Button" the one that lets you navigate Right/Left/Confirm lots of times when pressing it it goes Left/Right then confirms, I have to be very steddy to press the confirm button without triggering the directions as well, what's the main problem with this, every time I enter the Settings menu and have to go back using the bottom menu item "back to Home" it goes up and resets the device to default state... this is really annoying as I have to go again and configure everything I changed and then cross my fingers this does not happen again when trying to go back to home screen, on other menus it's also annoying but not so much as when it restes de device, my point is, would it be possible to add a second step when you select the reset menu so you have a final confirmation, it would probably happen the same.. pressing Cancel then switching to Confirm.. but maybe you would have a second opportunity... or maybe there is another alternative to navigate back.. some sort of long confirm button press or something similar, I hope I've explained myself.

Thanks.

solosky, 2024-01-20:
Hi there, I think you are the first one to report this issue, I don't have any issue when go back to home when in settings APP.
Anyway, your suggestion seems reasonable,  and I will add a confirmation message box before reset to default settings.

impeeza, 2024-01-20:
Cool.

And the order of cancel accept commit to always accept to the dame side😸

solosky, 2024-01-23:
Sorry, I don't your point, the button should be layout with LEFT, CENTER, RIGHT
you can call ```mui_msg_box_set_btn_focus(app->p_msg_box, 0|1|2)``` set default focus icon.

solosky, 2024-01-23:
That's exactly order what I have done here. No CENTER button is required here.
```
mui_msg_box_set_btn_text(app->p_msg_box, _T(CONFIRM), NULL, _T(CANCEL));
mui_msg_box_set_btn_focus(app->p_msg_box, 2);
```

solosky, 2024-01-23:
That's a good question here, my short answer is that the default action should carefully select by its senario.
For example, create new folder, the default button should be confirm, but for delete action, the default action should be cancel.

solosky, 2024-01-29:
Hi @PonyOny , I don't have such issue and no one else report this issue too, so I consider your wheel switch may be broken, you may need to replace one or to request your seller to replace a new one.

GlebDGT11, 2024-08-27:
Hi, @solosky , I have recently catch problem for my allmiibo, that I bought on 2nd of July and getting it in 29th of July. So, the problem: When I wanted to download latest firmware to 2.11.0 from 2.10.2, firstly screen looking like it's getting hammered, but not, I quickly put it into DFU Updater to install that firmware again, and while updating is getting finished, it just stops at 240k firmware bytes and started bootlooping in the DFU Updater mode, and it won't able to return to Main Menu

Uploading VID_2024_08_27_16_45_14_1262661556606660999115.mp4…

Closed 2024-01-28.

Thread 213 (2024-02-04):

Pixl.js buyer guide

solosky, 2024-02-04:
Hi everyone,

Thank for your starring this project!

As you may know, I don't make and sell Pixl.js device, but I hope everyone that like this project is able to get a Pixl.js compatible device in a affordable price, so if you already buy a Pixl.js like device, please kindly post your buy link here to make it easy to choose what you would like to get one.

Thank your contribution on this.

## here is an example:

* Buy Link: [Taobao](https://item.taobao.com/xxxx)
* Price: XXX CNY

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

impeeza, 2024-02-04:
Buy Link:  https://shop.mtoolstec.com/product/pixl-with-oled-for-amiibo
Price (2024_02_04): 29.99 USD
Details: OLED, USB-C for charging and for Firmware Update via SDCLK, very small, White or Black

> 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

LEO318x, 2024-02-10:
Buy Link: [https://item.taobao.com/item.htm?id=732982684854](https://item.taobao.com/item.htm?id=732982684854)
Price (10-02-2024): ￥150.00 ≈ $22.26
Details: OLED, USB-C, Battery 180mAh

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

Schokobecher, 2024-04-03:
Buy Link: [AliExpress](https://www.aliexpress.com/item/1005006420542854.html)
Price (21-03-2024): $12.61
Details: LCD, USB-C, 180mAh LiPO Battery
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

Flashed fine via nRF DFU (iOS) and DFU via the Web Interface

fanoush, 2024-06-09:
After getting one for $14, aliexpress started to offer me this amiibo pixl device in "3 from $xx" ChoiceDay deals when I search for "pixl" so I got few more :-)
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
so try to search for "pixl" when thins choice day deal is active, maybe you'll get the offer too but it is random, today I don't get it

I also get regularly offer for the keychain one for $2.69, which is not bad for nrf52832 device with NFC too
here it is today
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

skylandersNFC, 2024-09-17:
Let me give some links as well :

https://www.aliexpress.com/item/1005006994020829.html

https://www.aliexpress.com/item/1005006260883608.html

https://www.aliexpress.com/item/1005006732518163.html

https://www.aliexpress.com/item/1005006214951877.html

They are all around **17 bucks**.

Part of the **[Skylanders on Allmiibo](https://skylandersnfc.github.io/Docs/Skylanders_on_Allmiibo/)** guide.

skylandersNFC, 2024-11-22:
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
https://www.amazon.com/Flashiibo-Emulator-Expandable-Unlimited-Rewrite/dp/B0CQWRPJL2

grimson73, 2025-06-14:
https://nl.aliexpress.com/item/1005008726926205.html
- pixl.js firmware v2.12.0 already installed, guess a recent hardware batch made.
- Key_Retail.bin preinstalled
- Internal battery
- Delivery (the Netherlands) was within a week and the in transit delivery status communication excellent.

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
*image distortion due to screenrefresh / camerashutter.

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
Protective plastic

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
Real tiny but manageable.

As I just received this device it seems well working and would recommend for purchasing. Will see about durability now.

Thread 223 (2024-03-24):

Is possible to implement fimrware update via NFC cardreaders via PC?

Wohlstand, 2024-03-24:
Hello!

I do have such card reader that gets plugged via USB:
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

It works on Linux through the `pcsc` library (an output of `pcsc_scan` tool is here):
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

And I got a question: I do see already the use of iNFC thing on mobile devices, but what about PC support with the NFC devices?

impeeza, 2024-03-24:
May be possible, but practical I don't know,  the average firmware is 1.2 MB  and NFC normally transmit 1 Kb/s and you need that space free on the internal storage which is normally 1.8 MB so who knows!

solosky, 2024-03-25:
Possible, but not recomended, because comparing NFC, the BLE is most common hardware support by many device and nrf52 sdk and nrf toolset has built-in support for DFU by BLE.

Wohlstand, 2024-03-26:
Oh, about the NFC case I probably confused while I attempted to understand the manual 👀
I do have BLE adapter on my PC, and device gets clearly detected by Linux Mint's Bluetooth manager, however, to submit data need to have a program that supports custom protocols. I tried to run the nFR Connect thing, but it just can't detect anything (need to install dependencies to get it work properly).

impeeza, 2024-03-26:
You can use chrome on the Linux pc to upload firmware using the webpage

Wohlstand, 2024-03-26:
I already tried Chromium and M$ Edge, and it is unable to find anything, even at the specification of Web Bluetooth is noted that this API is experimental and is not yet properly standardised and desktop browsers doesn't implement it well. Maybe I'll try to make a kind of console tool that will use the raw Bluetooth directly? Just to upload/get files easily and send firmware updates vi DFU. Actually I wanted to build from the source code the modified version of firmware and try it out, but right now I waiting when a compatible programmator will arrive me. I wanted to try with Bluetooth way but I know the risk to brick the device without having a programmator.

Wohlstand, 2024-03-26:
Actually, using experimental APIs is 峨峨, using Web APIs that depends on minor set of browsers is 峨峨, and using Web that works on remote server for me is 峨峨 (I prefer standalone tools that will 100% work even Web server will be gone forever).

Wohlstand, 2024-03-26:
Anyway, how much is possible to turn the existing Web application into Electron-based app?

impeeza, 2024-03-27:
The website is based on VUE so may be because you also can create Electron apps using VUE.

Wohlstand, 2024-03-27:
> The website is based on VUE so may be because you also can create Electron apps using VUE.

I trying that to do now, first I need to tweak some files to make them not fail... Actually, Electron has working Web Bluetooth thing, so, it's possible that it WILL work.

Wohlstand, 2024-03-27:
Actually, for Electron case needs some small refactoring :thinking: : https://www.electronjs.org/docs/latest/tutorial/devices

impeeza, 2024-03-27:
The website is based on VUE so may be because you also can create Electron apps using VUE.

Schokobecher, 2024-04-04:
I don't see the point in turning the current web app into an Electron app, adding more Chromium doesn't really make sense seeing how bare-bones the app is.

The BLE portion works fine, as well as the [DFU](https://thegecko.github.io/web-bluetooth-dfu/examples/web.html) app in Vivaldi on macOS, so I would assume the Linux Chromium should also work

Wohlstand, 2024-04-04:
The latest Chromium just fails:
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

Google Chrome fails too:
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

Yandex Browser too:
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

Actually, as I said, this API is experimental and doesn't properly works everywhere: https://developer.mozilla.org/en-US/docs/Web/API/Web_Bluetooth_API#browser_compatibility

Wohlstand, 2024-04-04:
Actually, this feature is only works when enable Experimental Web platform features flag:
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

Wohlstand, 2024-04-04:
Additionally, the Web Bluetooth API gets been refused because of security risks and complication of maintenance (including the blacklist of vulnerable/faulty devices).

Schokobecher, 2024-04-04:
> Actually, this feature is only works when enable Experimental Web platform features flag:
Can't confirm that:
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

BLE Transfer and DFU work fine with my 2019 MBP

Wohlstand, 2024-04-04:
Vivaldi is not fully Chromium, its way reworked including several features. On my end is a pure unmodified Chromium of the super latest version.

Schokobecher, 2024-04-04:
With a freshly installed Google Chrome (Stable, v123.0.6312.107)
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
Fresh Profile, never installed on this machine, this is not a Chrome/Chromium issue

deekue, 2024-06-08:
FWIW, I've had some success on Linux

Ubuntu 22.04.4
Google Chrome 125.0.6422.141 (with Experimental Web Platform features enabled)
[allmiibo LCD](https://www.aliexpress.com/item/1005006420542854.html) 2.10.2

firmware update worked via
https://thegecko.github.io/web-bluetooth-dfu/examples/web.html

had some issues with BLE File Transfer via
https://pixl.amiibo.xyz
enable 'BLE File Transfer' on the device, then click the 'Connect' button on the webiste, the pop-up window spins and scanning shows 'No compatible devices found'.

I went to the Bluetooth control panel and saw that a 'Pixl.js' device was listed as paired but not connected.  Removed the pairing and then the scanning worked and it connected fine.

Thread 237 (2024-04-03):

Usage of both _L_ON/_L_OFF and _L_ON_F/_L_OFF_F to achieve a similar result - to display ON/OFF in square brackets.

MayanKoyote, 2024-04-03:
In general, to display the [ON]/[OFF] states on the screen, special lines are used that are defined in the localization file as _L_ON_F/_L_OFF_F.
https://github.com/solosky/pixl.js/blob/223609b07aa2b97a6adfeb8b2932985d1c4d3e64/fw/application/src/i18n/en_US.c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

But in some cases, the values of the _L_ON/_L_OFF lines of the localization file are used instead. And they are automatically placed in square brackets by the applications itself.
(I think) these are the cases (although maybe I'm mistaking):
1. pixl.js/fw/application/src/app/amiidb/scene/amiidb_scene_amiibo_detail_menu.c
https://github.com/solosky/pixl.js/blob/223609b07aa2b97a6adfeb8b2932985d1c4d3e64/fw/application/src/app/amiidb/scene/amiidb_scene_amiibo_detail_menu.c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
https://github.com/solosky/pixl.js/blob/223609b07aa2b97a6adfeb8b2932985d1c4d3e64/fw/application/src/app/amiidb/scene/amiidb_scene_amiibo_detail_menu.c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
https://github.com/solosky/pixl.js/blob/223609b07aa2b97a6adfeb8b2932985d1c4d3e64/fw/application/src/app/amiidb/scene/amiidb_scene_amiibo_detail_menu.c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

~~2. pixl.js/fw/application/src/app/amiibolink/scene/amiibolink_scene_menu.c~~ (update: looks like have been fixed by commit f4f9468)
<details>

https://github.com/solosky/pixl.js/blob/223609b07aa2b97a6adfeb8b2932985d1c4d3e64/fw/application/src/app/amiibolink/scene/amiibolink_scene_menu.c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

https://github.com/solosky/pixl.js/blob/223609b07aa2b97a6adfeb8b2932985d1c4d3e64/fw/application/src/app/amiibolink/scene/amiibolink_scene_menu.c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

</details>

~~3. pixl.js/fw/application/src/app/amiibo/scene/amiibo_scene_amiibo_detail_menu.c~~ (update: looks like have been fixed by commit 9d02de1)
<details>

https://github.com/solosky/pixl.js/blob/223609b07aa2b97a6adfeb8b2932985d1c4d3e64/fw/application/src/app/amiibo/scene/amiibo_scene_amiibo_detail_menu.c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

https://github.com/solosky/pixl.js/blob/223609b07aa2b97a6adfeb8b2932985d1c4d3e64/fw/application/src/app/amiibo/scene/amiibo_scene_amiibo_detail_menu.c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

</details>

4. pixl.js/fw/application/src/app/settings/scene/settings_scene_main.c
https://github.com/solosky/pixl.js/blob/223609b07aa2b97a6adfeb8b2932985d1c4d3e64/fw/application/src/app/settings/scene/settings_scene_main.c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
___
Except these cases of usage of the _L_ON/_L_OFF lines as substitutes for _L_ON_F/_L_OFF_F, the _L_ON/_L_OFF lines are used as follows:
there is usage of _L_OFF on its own (w/o brackets):
pixl.js/fw/application/src/app/settings/scene/settings_scene_sleep_timeout.c
https://github.com/solosky/pixl.js/blob/223609b07aa2b97a6adfeb8b2932985d1c4d3e64/fw/application/src/app/settings/scene/settings_scene_sleep_timeout.c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
and not a single use of _L_ON on its own (w/o brackets).

(At least I was unable to find anything else using github's search.)
___

So, is it possible to use only the lines defined in the localization file as _L_ON_F/_L_OFF_F to display the [ON]/[OFF] states on the screen?

Also, is it possible to replace them (as one of the options) with pseudo-graphic symbols, for example, such as ☑ (U+2611) and ☒ (U+2612)?
This would return the displaying of the [ON]/[OFF] states to a single character (开/关) and reduce onscreen text "jumping" when switching states. (Yes, I know that in some languages they have the exact opposite meaning. But this does not prevent speakers of such languages from successfully using imported tech, websites, etc. In addition, this can be easily redefined in the same localization file.)

Schokobecher, 2024-04-03:
> Also, is it possible to replace them (as one of the options) with pseudo-graphic symbols, for example, such as ☑ (U+2611) and ☒ (U+2612)?

`wenquanyi_9pt_u8g2.bdf` only includes

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

So no glyphs for universal icons are included

MayanKoyote, 2024-04-03:
It's always easy to replace or add some symbols to the font.
And, as I understand it, the font license allows to do this.

Schokobecher, 2024-04-03:
Actually scratch that, since `u8g2_font_siji_t_6x10` already provides some symbols:
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

But not sure any of these are very suited for this use-case

MayanKoyote, 2024-04-03:
The places intended for the symbols (U+2611) and (U+2612) in the font are currently not populated, so it's possible fill them and it turns out something like this:
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

MayanKoyote, 2024-04-05:
> Since we already have the square brackets around the icon, I suggest to remove the border of the ON / OFF icon.

U+2713 and U+2717 (although perhaps they should be placed in places U+2714 and U+2718):
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

Closed 2024-06-03.

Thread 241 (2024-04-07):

How should the [More..] button of the 'Search' function of the 'Amiibo Database' app work if there are more than 100 search results?

MayanKoyote, 2024-04-07:
The 'Amiibo Database' app has a 'Search' function.
The number of search results displayed per page is determined by the variable 'LIST_VIEW_ITEM_MAX_COUNT', it is equal to 100.
(Since my device came to me from Aliexpres, it contains a lot of material for testing.)
I do search for the letter 'b' and get information that there are 186 results in total and a list of the first 100 results.
Next comes the [More..] button. It is logical to assume that it should show me the remaining 86 results.
But I press it, and... nothing happens, the list of results does not change.

Am I misunderstanding something or is something not working the way it should?

solosky, 2024-04-07:
The [More..] only indicates that there are more that 100 items of the results, but due to the limitation of MCU memory, the device only could display 100 results, please add more characters to narrow down your search results.

solosky, 2024-04-07:
Considering display more search results is not make sense because it's hard to go through all search results in such small display, I do not add logic as your suggestion.

MayanKoyote, 2024-04-07:
It's clear now.
Then it might be worth renaming '[More..]' into something like '...and so on.' and removing the brackets around it?

solosky, 2024-04-07:
I do suggest that showing a message box displayed "Too many search results. \n Try update search criteria." when user click the [More..] item.

Closed 2024-04-09.

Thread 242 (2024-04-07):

The device does not want to show characters from the line [_L_APP_CHAMELEON_CARD_SET_NICK_FAILED] that are not Basic Latin.

MayanKoyote, 2024-04-07:
en_US - line is 'Set Nick Failed!' and the message is displayed as expected: 'Set Nick Failed!':
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

zh_Hans - line is '设置卡名失败' and the message displayed is ' '. Everything is missing, empty message:
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

fr_FR - line is 'Définir le Pseudo a Échoué!' and the message displayed is 'Dfinir le Pseudo a chou!'. All the characters 'é' and 'É' are missing:
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

ja_JP - line is 'ニックネームが設定できませんでした!' and the message displayed is '!'. Everything except the exclamation mark is missing:
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

It seems that the app wants to display only Basic Latin characters and does not want to display any others.

A similar story is observed in the case involving [_L_APP_CHAMELEON_CARD_ADV_ID_EDIT_INVALID_INPUT] line.

solosky, 2024-04-07:
Quickly checked, the mui_toast_view does not set wqy font before draw characters.
I will fix this later today.

solosky, 2024-04-07:
I should fix this issue, but it comes a new issue: The text is out of border when toast content displays more than one line.
I will fix that when I am avaliable.

Closed 2024-04-12.

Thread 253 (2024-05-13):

Device won't power on after last fw update

Samoth980, 2024-05-13:
Hi all,
I've received today my device, I've followed the instruction reported here but after the fw update the device won't turn on, suggestion?

solosky, 2024-05-13:
see https://github.com/solosky/pixl.js/blob/main/docs/en/02-Flash-Firmware.md#repair-wrong-firmware-version

Samoth980, 2024-05-13:
i saw it but there is no way to make it visible over the browser as before also the combination of left, middle... doesn't produce any blue light, it work only if I click on right (x3) but the browsed won't recognize (an external app yes,

solosky, 2024-05-13:
try use nrf connect app to upgrade, it is more stable when upgrading firmware.

Samoth980, 2024-05-13:
Is not clear, because with the last release the sequence button for the bt mode is different but i've solved.

impeeza, 2024-05-13:
Which device do you have?

Samoth980, 2024-05-14:
the LCD version, i've installed the last version and than crashed. Maybe a check about the hardware before forcing the upgrade will be useful

solosky, 2024-05-16:
> the LCD version, i've installed the last version and than crashed. Maybe a check about the hardware before forcing the upgrade will be useful

Good idea, let think how to do with this.

impeeza, 2024-05-19:
> the LCD version, i've installed the last version and than crashed. Maybe a check about the hardware before forcing the upgrade will be useful

can you try changing the battery?  mine last only few uses.

Samoth980, 2024-05-19:
I've solved, the issue was due to the wrong installed sw pushed and the
reset sequence reported into the documentation doesn't works with the last
release.

Il dom 19 mag 2024, 03:42 impeeza ***@***.***> ha scritto:

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

impeeza, 2024-05-19:
Thanks.  for let us to know.

Samoth980, 2024-05-19:
How can I change the battery?It is soldered onto the motherboard. Also how
this can solve a software incompatibly issue?

Il dom 19 mag 2024, 07:31 impeeza ***@***.***> ha scritto:

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

impeeza, 2024-05-20:
> How can I change the battery?It is soldered onto the motherboard. Also how this can solve a software incompatibly issue? Il dom 19 mag 2024, 07:31 impeeza ***@***.***> ha scritto:
> […](#)
> Thanks. for let us to know. — Reply to this email directly, view it on GitHub <[#253 (comment)](https://github.com/solosky/pixl.js/issues/253#issuecomment-2119107805)>, or unsubscribe <https://github.com/notifications/unsubscribe-auth/BFW4TJKCEATBCJSAZWE2R3TZDA2LVAVCNFSM6AAAAABHUJSA7KVHI2DSMVQWIX3LMV43OSLTON2WKQ3PNVWWK3TUHMZDCMJZGEYDOOBQGU> . You are receiving this because you authored the thread.Message ID: ***@***.***>

Ah, ok,  some LCD have a CR2032 battery.

Yours is the latest model which have the lion battery.

if your device have the back light set up and you don't see it may be a depleted battery even with wrong fimware.

ON LATEST FIRMWARE, you need to press:

-Any key to wake up the device
-Left
-Enter (middle button)
-Left 4 times
-Enter (middle button)

TO PUT YOUR DEVICE ON FIRMWARE UPGRADE MODE.

https://github.com/solosky/pixl.js/assets/41979604/b8687d65-e491-4236-ac06-f4667ec56aa3

solosky, 2024-07-29:
closed as issue resolved.

Closed 2024-07-29.

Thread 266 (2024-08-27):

Bootloop in the DFU Updater mode

GlebDGT11, 2024-08-27:
Hi, @solosky , I have recently catch problem for my allmiibo, that I bought on 2nd of July and getting it in 29th of July. So, the problem: When I wanted to download latest firmware to 2.11.0 from 2.10.2, firstly screen looking like it's getting hammered, but not, I quickly put it into DFU Updater to install that firmware again, and while updating is getting finished, it just stops at 240k firmware bytes and started bootlooping in the DFU Updater mode, and it won't able to return to Main Menu

Uploading VID_2024_08_27_16_45_14_1262661556606660999115.mp4…

solosky, 2024-08-28:
Sorry, I cannot see the video you posted here.
you can try upgrade firmware with MTools BLE and NRF Connect.

https://github.com/solosky/pixl.js/blob/main/docs/en/02-Flash-Firmware.md#nRF-Connect-APP

GlebDGT11, 2024-08-28:
I fix the problem, and it's now working, thanks to my friend that helped me out from this

impeeza, 2024-08-28:
How did you solve the problem?   please close the issue if is solved.

GlebDGT11, 2024-08-28:
I just short circuited some contacts on Allmiibo Board to reset the system and then writing the firmware again

Closed 2024-08-28.

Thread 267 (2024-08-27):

After updating the strip instead of the text, can I fix it?

A5littleangel, 2024-08-27:
I updated with infc to the latest version, but after updating, there are only stripes on the screen, can I fix this?
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

impeeza, 2024-08-27:
you apply the OLED firmware to a LCD unit.

Follow the instructions to apply the firmware update blindly

solosky, 2024-08-28:
Instruction for repair wrong firmware:

https://github.com/solosky/pixl.js/blob/main/docs/en/02-Flash-Firmware.md#repair-wrong-firmware-version

A5littleangel, 2024-08-28:
> Instruction for repair wrong firmware:
>
> https://github.com/solosky/pixl.js/blob/main/docs/en/02-Flash-Firmware.md#repair-wrong-firmware-version

Where to press at this moment are these keys (X N)?

LEFT X N

The strip on the screen does not disappear after 45 seconds either
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

impeeza, 2024-08-28:
«LEFT x N» (times)  is

If the firmware version before 2.11.x, press LEFT x 4 If the firmware version after 2.11.x, press LEFT x 5

is on the instructions,  that means if the wrong firmware you flash  is below 2.11  you need to press LEFT 4 times,  if the firmware is newer your need to press LEFT 5 times.

impeeza, 2024-08-28:
And yes is normal the strip do not disappear because the driver is wrong.

A5littleangel, 2024-08-28:
> And yes is normal the strip do not disappear because the driver is wrong.

Thanks for the previous answer, I've been doing everything according to the instructions for an hour now, writing this 4096/357604 firmware bytes written
What to do? How much should be updated approximately?

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

impeeza, 2024-08-28:
Send the update again sometimes it can hang, if you start again from the app or browser the upgrade will resume.

A5littleangel, 2024-08-28:
> Send the update again sometimes it can hang, if you start again from the app or browser the upgrade will resume.

I tried it 20 times, but it doesn't go beyond that.
4096/357604 firmware bytes written

I'm trying through this
https://thegecko.github.io/web-bluetooth-dfu

through https://pixl.amiibo.xyz /
does not find the device

impeeza, 2024-08-28:
trY https://github.com/solosky/pixl.js/blob/main/docs/en/02-Flash-Firmware.md#nRF-Connect-APP

MayanKoyote, 2024-08-29:
Are you flashing from a PC? Try flashing from an Android phone.

A5littleangel, 2024-08-29:
Thank you, it turned out to flash through the PC, it also did not work through the phone, it just does not see the device.

When emulating amiibo, the screen freezes and nothing happens, can I reboot somehow? Already turned on, and does not turn off for 7 hours

impeeza, 2024-08-29:
on your model you can remove the battery to full reboot the device,  also on settings menu there is an option to reboot the device.

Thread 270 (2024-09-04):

Suggestion: Is it possible to let user enter their own UUID of choice?

t0mizwf26, 2024-09-04:
For "Amiibo Emulator", in addition to "Rand. Tag", is it possible to implement a new feature to let user enter their own UUID?

Something like:
```
Rand. Tag
Auto Rand. [OFF]
{new} Cust. UUID
{new} Use C.UUID [ON]
...
```
Use Case Scenario (example):

**TL;DR** By entering/cloning real Amiibo UID into pixl.js, enables user to transfer Amiibo data back and forth between real Amiibo and pixl.js

1. User obtain UID from a real Amiibo (Mario for example) using smartphones app etc.
2. User enter that UID into pixl.js device (Mario.bin)
3. User playing SSBU on Switch at home using real Amiibo and train the Amiibo FP
4. Before traveling, user let SSBU read real Amiibo's data and then write the data into pixl.js (with same UUID)
5. When traveling, user continue to train the FP using pixl.js
6. When back home, user let SSBU read pixl.js data and write the data back into real Amiibo

solosky, 2024-09-06:
Hi, thank your suggestion.
I don't think this feature is nessary, you can archive same target by steps bellow:

* Get a fully dump from your amiibo by NFC reader app of Mobile Phone (Or search the dump file from internet)
* Put the amiibo bin file into Pixl.js
* Select the amiibo bin file, and turn off the Auto Rand. function, so the id of amiibo bin file do not change
* when travelling, user continue to train the FP using pixl.js, the data will write to amiibo bin file
*  When back home, user let SSBU read pixl.js data and write the data back into real Amiibo

t0mizwf26, 2024-09-07:
Thanks so much for the explanation, but I guess this feature might still be useful if someone wants to transfer existing save data from pixl.js to a newly purchased Amiibo?

For example:
1. User doesn't have a real Mario Amiibo, so user is using pixl.js Mario with UID "XXXX" to play Smash Bros
2. User bought a new real Mario Amiibo (UID "YYYY") and wants to transfer / copy the Smash Bros Amiibo FP save data from pixl.js Mario to real Mario Amiibo

I heard Tagmo for Android can "Ignore Tag ID #" so it can force update any Amiibo even they have different UID, so it can write UID "XXXX" save data into UID "YYYY", but the problem is Tagmo not available on iOS.

If we can have this "custom UUID" feature implemented, maybe people will then able to transfer save data between any Amiibo without using any special phone app? (except they still need to find out their Amiibo's UID)

Breadmasterpro, 2024-09-18:
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

I think it would be a good feature, and if you could save the amiibo uuid's in case of a reset that would be even better!

Closed 2024-10-13.

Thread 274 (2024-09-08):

Allmiibo screen randomy starts bugging out

Breadmasterpro, 2024-09-08:
After updating to v2.11.0 the screen will sometimes go completely blank or bug out and go upside down. All the allmiibo functions still work when the screen goes blank and I can still scan and switch amiibo but I just can't see anything at all. The only way to fix this is to let it enter sleep mode then turn it on again.

https://github.com/user-attachments/assets/f10a9185-2c19-4424-a983-24fd577ae5cf

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

Breadmasterpro, 2024-09-08:
![Uploading 20240908_181004.jpg…]()

Breadmasterpro, 2024-09-08:
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

solosky, 2024-09-08:
This issue happens before, still can not know the reason, try to flash firmware again or reset the device by pull out the battery.

Breadmasterpro, 2024-09-09:
> This issue happens before, still can not know the reason, try to flash firmware again or reset the device by pull out the battery.

Ok

Closed 2024-09-16.

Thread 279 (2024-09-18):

Amiibo in 'amiibo database' do not save

Breadmasterpro, 2024-09-18:
The amiibo in 'amiibo emulator' save but the amiibos in 'amiibo emulator' are not up to date because some are missing and I prefer to use the database anyway. The amiibos in 'amiibo database' reset everything the divice goes to sleep. While it is still on they remain the same but once the divice enters sleep state and then I turn it on and go back to the same amiibo, it has reset. I have made sure the 'randomise' option is off, I have rebooted the allmiibo, I have reset settings and I have reflashed the firmware many times but nothing fixes the issue, it is sad because I did a ton of battles is splatoon but the amiibos aren't saving so I could not get the amiibo gear :( can you please look into this issue?

Breadmasterpro, 2024-09-18:
> The amiibo in 'amiibo emulator' save but the amiibos in 'amiibo emulator' are not up to date because some are missing and I prefer to use the database anyway. The amiibos in 'amiibo database' reset everything the divice goes to sleep. While it is still on they remain the same but once the divice enters sleep state and then I turn it on and go back to the same amiibo, it has reset. I have made sure the 'randomise' option is off, I have rebooted the allmiibo, I have reset settings and I have reflashed the firmware many times but nothing fixes the issue, it is sad because I did a ton of battles is splatoon but the amiibos aren't saving so I could not get the amiibo gear :( can you please look into this issue?

Update: it also resets if I just change amiibo then go back to the same on without the divice entering sleep mode.

fedprod, 2024-09-20:
That is because the Database is only as a reference and not for personal Amiibos.
For that you have to SAVE them as an Amiibo in your personal list!

solosky, 2024-09-21:
Yeah, if you ```go browse..``` menu and select one of amiibo in Amiibo Database, the amiibo data is volatile, means that it is generated amiibo data on the fly for one time use and do not save it to flash.
If you want to write data to the generated amiibo, first you need to go to the context menu and select `save..`  to one slot.
once you want to write data to the amiibo, you need first select ``` My Amiibo``` and select slot that you want to read and save to, the amiibo will be saved automatically when any write to the amiibo.

Breadmasterpro, 2024-09-21:
> Yeah, if you go `browse..` menu and select one of amiibo in Amiibo Database, the amiibo data is volatile, means that it is generated amiibo data on the fly for one time use and do not save it to flash. If you want to write data to the generated amiibo, first you need to go to the context menu and select `save..` to one slot. once you want to write data to the amiibo, you need first select ` My Amiibo` and select slot that you want to read and save to, the amiibo will be saved automatically when any write to the amiibo.

Oh thanks, can you add an option to have my amiibo on the main menu? Maybe make it replace amiibolink because that never works. Are the amiibo in amiibo emulator supposed to be up to date or are they like references? Thanks for your help! I'll go save my amiibo now!

solosky, 2024-09-21:
If you have amiibo data files, you can upload to device and use Amiibo Emulator to emulate amiibo data files.
If you don't have amiibo data files, you can use Amiibo Database to generate Amiibo data file on the fly, and save it into slot if you would like to use as personal amiibo data files.

I am not going to add My Amiibo to the main menu, because that is not following the design pattern of Pixl.js firmware.

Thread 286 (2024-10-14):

I noticed that there is a sleep mode button in settings, what if you move it from settings next to settings

Splatboy0612, 2024-10-14:
I think it would be easier and faster that way instead of going into settings to put the device to sleep

MayanKoyote, 2024-10-15:
This is redundant.

Although if you look into it, this is what is currently contained in the 'Settings' section:

= Settings =
 - Version - only information
 - Language - setting
 - External Storage - information and formatting action. Well, it fits the definition of "settings", since it's set (format) storage. Although it (formatting) can also be attributed to "management".
 - Backlight - setting
 - Menu Animation - setting
 - LiPO Battery - setting
 - Memory Used - setting and information
 - Fast Wakeup - setting
 - Sleep Timeout - setting
 - Go Sleep - action. Definitely not a setting
 - Firmware Update - action. Very indirectly related to the settings (only since it's about firmware update)
 - System Reboot - action. Definitely not a setting
 - Reset Default Settings - action. But directly related to the settings
 - About Device - only information

From what is directly or indirectly not related to the settings, it's possible to compose a new separate section, let's call it 'Management':

= Management =
 - Go Sleep - action
 - System Reboot - action
 - Firmware Update - action

and if we transfer 'Firmware Update' action here, then perhaps it can also be moved here (to 'Management' section):

 - Version - only information
 - About Device - only information

So it will turn out like this:
= Management =
 - About Device - only information
 - Version - only information
 - Firmware Update - action
 - System Reboot - action
 - Go Sleep - action

solosky, 2024-10-15:
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

Good point of view.
The setttings menu sames a mess currently, I really don't give a deep thought like this.
I may have re-structure the menu settings in future release.

Splatboy0612, 2024-10-22:
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

Oh, ok, then I'll close the case

Closed 2024-10-22.

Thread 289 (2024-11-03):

SSD1306 in I2C mode

Ahmadkorhani, 2024-11-03:
Can you implement SSD1306 in I2C mode please ?

solosky, 2024-11-07:
May I know why would need this feature?

Ahmadkorhani, 2024-11-07:
Thank you for your response, I can't find the spi version in my country, only I2C version.

I kept SPIM instance to 0 and enabled TWIM1 for oled, added the correct handler and callbacks (I tested everything in separate project using u8g2 library and my functions are working) but on my nrf52832 proto board the screen show only white noise (static white dots with random position on startup)

Ahmadkorhani, 2024-11-07:
I meant on separate projects my u8g2 I2C implementation was working, same code on pixl is showing white dots.
I double checked configuration in sdk_config.h

Ahmadkorhani, 2024-11-07:
here is the log from RTT:
00> <info> app_timer: RTC: initialized.
00>
00> <debug> app: FLASH ID:
00>
00> <debug> app:  EF 40 18               |.@.
00>
00> <info> app: W25Q128BV detection
00>
00> <info> app: external fs mount: 0
00>
00> <info> app: settings init: 8
00>
00> <info> app: nrf_power_resetreas_get: 0x0000
00>
00> <info> app: noinit area: [0x20002BD0, 0x20002FDC], 259 bytes
00>
00> <info> app: m_cache_data address: 0x20002BD0
00>
00> <info> app: Cleaning cache...
00>
00> <info> app: Reset noinit ram done.
00>
00> <info> app: WeakUp from button
00>
00> <info> app: amiibo key read: -90
00>
00> <info> app: init done
00>
00> <info> app: Cache data: enabled = 0, id = 0
00>
00> <info> app: wakeup reason: 0
00>

but still nothing but white dots on the screen, pushing the buttons do nothing

solosky, 2024-11-07:
It's a lot of work to adopt new screen,  please post your modification of code here, otherwise I cannot give your any advice.

Ahmadkorhani, 2024-11-07:
Here is the modified mui_u8g2.c file . the original only initialize the oled in spi mode. this code is working perfectly on standalone project but not inside this pixl

`#include <stdio.h>

#include "app_error.h"
#include "nrf_delay.h"
#include "nrf_gpio.h"
#include "nrf_log.h"
#include "settings.h"

#include "u8g2.h"
#include "u8x8.h"

#include "app_pwm.h"

#include "boards_defines.h"
#include "nrf_drv_twi.h"

u8g2_t u8g2;

uint8_t m_u8g2_initialized = 0;
/* Indicates if operation has ended. */
static volatile bool m_xfer_done = false;
static bool readsomething = false;

#define TWI_ADDRESSES    127
#define OLED_ADDR        0x3C
#define TWI_INSTANCE_ID     1
//static const nrf_drv_twi_t m_twi = NRF_DRV_TWI_INSTANCE(TWI_INSTANCE_ID);
static const nrf_drv_twi_t m_twi = NRF_DRV_TWI_INSTANCE(1);

uint8_t u8g2_nrf_gpio_and_delay_twi_cb(u8x8_t *u8x8, uint8_t msg, uint8_t arg_int, void *arg_ptr);
uint8_t u8x8_HW_com_twi_nrf52832(u8x8_t *u8x8, uint8_t msg, uint8_t arg_int, void *arg_ptr);
void twi_init (void);
void twi_handler(nrf_drv_twi_evt_t const * p_event, void * p_context);

void twi_handler(nrf_drv_twi_evt_t const * p_event, void * p_context)
{
    switch(p_event->type)
    {
        case NRF_DRV_TWI_EVT_ADDRESS_NACK:
        {
            // NRF_LOG_ERROR("Got back NACK");
            m_xfer_done = true;    
            break;
        }
        case NRF_DRV_TWI_EVT_DATA_NACK:
        {
            // NRF_LOG_ERROR("Got back D NACK");
            m_xfer_done = true;    
            break;
        }
        case NRF_DRV_TWI_EVT_DONE:
        {
            if (p_event->xfer_desc.type == NRF_DRV_TWI_XFER_RX)
            {
                readsomething=true;
            }
            m_xfer_done = true;
            break;
        }
        default:
        {
            m_xfer_done = false;
            break;
        }
    }
}

void twi_init (void)
{
    ret_code_t err_code;

    const nrf_drv_twi_config_t twi_oled_config = {
       .scl                = OLED_I2C_PIN_SCL,
       .sda                = OLED_I2C_PIN_SDA,
       .frequency          = NRF_DRV_TWI_FREQ_400K,
       .interrupt_priority = APP_IRQ_PRIORITY_HIGH,
       .clear_bus_init     = false,
    };

    err_code = nrf_drv_twi_init(&m_twi, &twi_oled_config, twi_handler, NULL);
    APP_ERROR_CHECK(err_code);

    nrf_drv_twi_enable(&m_twi);
}

uint8_t u8g2_nrf_gpio_and_delay_twi_cb(u8x8_t *u8x8, uint8_t msg, uint8_t arg_int, void *arg_ptr)
{
    switch(msg)
    {
        case U8X8_MSG_DELAY_MILLI:
            // NRF_LOG_INFO("nrf_delay_ms(%d)", arg_int);
            nrf_delay_ms(arg_int);
            break;

        case U8X8_MSG_DELAY_10MICRO:
            // NRF_LOG_INFO("nrf_delay_us(%d)", 10*arg_int);
            nrf_delay_us(10*arg_int);
            break;

        default:
            u8x8_SetGPIOResult(u8x8, 1); // default return value
            break;
    }
    return 1;
}

uint8_t u8x8_HW_com_twi_nrf52832(u8x8_t *u8x8, uint8_t msg, uint8_t arg_int, void *arg_ptr)
{
    uint8_t *data;
    bool res = false;
    ret_code_t err_code;
    static uint8_t buffer[32];
    static uint8_t buf_idx;
    switch(msg)
    {
      case U8X8_MSG_BYTE_SEND:
      {
            data = (uint8_t *)arg_ptr;
            while( arg_int > 0 )
            {
              buffer[buf_idx++] = *data;
              data++;
              arg_int--;
            }
            break;
      }
      case U8X8_MSG_BYTE_START_TRANSFER:            
      {
            buf_idx = 0;    
            m_xfer_done = false;
            break;
      }
      case U8X8_MSG_BYTE_END_TRANSFER:
      {    
            uint8_t addr = u8x8_GetI2CAddress(u8x8);
               
            err_code = nrf_drv_twi_tx(&m_twi, u8x8_GetI2CAddress(u8x8) , buffer, buf_idx, false);
            APP_ERROR_CHECK(err_code);
            while (!m_xfer_done)
            {
                __WFE();
            }
            break;
      }
      default:
            return 0;
    }
    return 1;
}

void mui_u8g2_init(u8g2_t *p_u8g2) {

    twi_init();
    u8g2_Setup_ssd1306_i2c_128x64_noname_f(&u8g2, U8G2_R0, u8x8_HW_com_twi_nrf52832, u8g2_nrf_gpio_and_delay_twi_cb);
    u8g2_SetI2CAddress(&u8g2, OLED_ADDR);
    u8g2_InitDisplay(&u8g2);
    u8g2_SetPowerSave(&u8g2,0);

}

void mui_u8g2_deinit(u8g2_t *p_u8g2) {
    u8g2_SetPowerSave(p_u8g2, 1);
}

void mui_u8g2_set_oled_contrast_level(uint8_t value) {
    //mui_t *p_mui = mui();
    //u8g2_SetContrast(&p_mui->u8g2, (value - 1) * (255.0 / 99.0));
}
`

solosky, 2024-11-08:
Sorry, I dont have any device to test your code..
I think you could hook signal pin to logic analyzer and try to grab some data to see if the MCU send the correct data out first.

Ahmadkorhani, 2024-11-08:
That's what I will do, I have a DSLogic logic analyzer. I will share any update. One last question, the RTT is normal ? Is it missing anything ?

Ahmadkorhani, 2024-11-08:
I have added I2C scanning + log after twi_init() and the system detect the address correctly which is 0x3C so i think the code should work correctly, then i found that it looks like the nrf52 freezes for some reason. the 32khz crystal is working fine. as I can't debug inside VSCode I can't find the source of the issue, every time I try to compile it takes forever to build. it rebuild everything everytime

Ahmadkorhani, 2024-11-09:
I think I should quit, I don't know what is happening. I started a new ble project in segger and added both spi flash and ssd1306. they are working great with my code.
Adding same code to this project is not working, I am building this code using GNU Arm Embedded Toolchain\10 2021.10 inside VSCode.

I don't know what could be the problem and I am sure now it is not coming from my modification. Maybe some VScode configuration is messing with the building output.

If anyone managed to build it and flash it successfully please specify what compiler you used and if you did some tweaks or not to the make file

solosky, 2024-11-09:
here is a hint, use new free pins to connect SDA and SLC signal, please do not use same pin as SPI.
The oled and SPI flash are shared same SPI bus in current implementation.

Ahmadkorhani, 2024-11-09:
of course I did that, remember I added a function to detect I2C address and it was working, after all I found that the processor hangs inside the while after the initialization. So it looks like something is wrong in the building process

Ahmadkorhani, 2024-11-17:
Finally it is working with I2C SSD1306 OLED display, it was a silly pointer typing problem. Now everything is working like a charm :)

Closed 2024-11-17.

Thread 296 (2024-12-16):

README.md needs clarification

rogueeve575, 2024-12-16:
I'm not sure if this is an "issue" or where it should go exactly, but I have one of these devices with an OLED screen and internal battery ([looks like this](https://shop.mtoolstec.com/wp-content/uploads/2023/11/Pixl-OLED-main-1.jpg)). It's really beautiful hardware in person, I just don't actually own a Switch. A friend sent this to me under the impression it was the same as the Espruino-based Pixl.js with different firmware and I would be able to simply flash stock Espruino onto it for a project. However, I since realize that this device is not really the same as Gordon's Pixl.js.

I was wondering if anyone might be able to provide more context as to the history of why these devices are called a Pixl.js. The README.md says it's a fork, with a link back to the Espruino repo, and indeed my AmiiboLink Pixl.js does appear as a pairing option on the official Espruino IDE (but only partially connects of course) and likewise the official Amiibo webapp offers to pair to my Espruino-based Bangle.js, so there is clearly some sort of overlap, but I don't see the actual Espruino code under this repo (unless I missed it?).

Basically I'm just trying to understand more about this neat little device so I can find different ways I could run my own code on it. It's in a really pretty case which I suspect may be glued shut, so I'm investigating the other options before I bust it open and go messing about with SWD pins. Is there still any underlying Espruino left I could get a REPL on somehow? I'm also just a bit curious about the history I guess.

To make this technically an "issue", I could request "README.md needs clarification" since it mentions Espruino but for me anyway, the connection was unclear. Also the BOM page may not be complete -- since I haven't opened my device up yet I'm actually not certain what CPU this has since I didn't see it listed, although I suspect it's probably a nRF52832?

solosky, 2024-12-17:
Hi there,  I am glad you like this device.

Indeed, it's very confuse between the Espruino and my pixl.js project. I think it is nessary to have a brief about the pixl.js project history.

At first, I was already working on the nrf52832 to emulate amiibo, and already design a couple of prototypes, but I don't satisfy with my protoypes. And someday I found the [Pixl.js board](https://shop.espruino.com/pixljs),  I realized that the Pixl.js board is exactly what i would like to build, so I reviewed its hardware spec and trying to build a similar device but with some hardware change to make the device better for emulate amiibo. for example, added a flash chip, re-layout the PCB, etc. it results in the current LCD version hardware.

At first, I was focusing on the firmware development and I just use the Pixl.js as the repo name because I did not come a good name on this project. However, with the new feature was implemented quickly and I still could not have a good name on this project, so I decided to continue using Pixl.js as project name.

That is the project history. I am sorry the project name make you confused and I total agree with you.

Regarding why not develop the firmware using Espruino, I was considering the Pixl.js was designed to emulate Amiibo and not intend to an open source creative hardware platform for hobbies.  With native C code implementation, we could benefit from small firmware footprint and compact RAM usage.

Anyway, I still tried the Espruino on my LCD version of Pixl.js at project beginning and works well. It requires some modification from original Espruino codebase. I think I could release the Espruino fork for Pixl.js if I am avaliable. If you intrested in running Espruino on Pixl.js device, you could follow me and stay tunned.

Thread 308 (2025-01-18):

LCD 2.12.0 firmware do show nothing

shurillu, 2025-01-18:
Hello,

   I've downloaded the firmware for the LCD version from the release page (2.12.0) and programmed with the web flasher (https://thegecko.github.io/web-bluetooth-dfu/examples/web.html).
After flashing, the screen light turn on but without showing any menu.
Falling back with the trick ANY KEY - LEFT - MIDDLE - 5x LEFT - MIDDLE -> DFU MODE -> reflash 2.11.2 with the web flasher.

Any clue?

Thanks,

Stefano

impeeza, 2025-01-18:
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

Yes read the Release notes (https://github.com/solosky/pixl.js/releases/tag/2.12.0):

For LCD versions, if the screen appears too faint after updating, you can reset the settings by following these button presses after the device enters standby mode: Middle, Left, Middle, Right (x3), Middle, Right (xN) until the screen becomes clear. Set the contrast to 80.

use the keys described to get the contrast high and the screen show text.

shurillu, 2025-01-19:
Thank you so much, it worked!

HorstHilch, 2025-01-21:
> Thank you so much, it worked!

Could you explain to me again how you did it? I followed impeeza's description but am I still stucked with the light turned on and no menu. However, I am sure I did something wrong on my side.

When the screen turned off I press the following buttons: Middle, Left, Middle, Right (x3), Middle and then multiple times Right, but nothing happens.

shurillu, 2025-01-22:
Hello HorstHilch,
  I did exactly the procedure explained by impeeza (display off -> MIDDLE -> LEFT -> MIDDLE -> 3x RIGHT -> MIDDLE -> Nx RIGHT)

You have to do the "Nx RIGHT" several times until the display start to show something (I don't remember but at least 5-10 times).
Anyway you can reflash the device with older firmware by enabling the DFU mode

MIDDLE - LEFT - MIDDLE - 5x LEFT - MIDDLE -> DFU MODE -> reflash 2.11.2 with the web flasher

Keep in mind that the DFU mode have a timeout; my advice is: prepare the web flasher with the correct file and after that enter in the DFU mode.

Good luck!

Stefano

Closed 2025-01-19.

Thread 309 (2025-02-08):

Amiibopro screen freeze

Rogelio-dr, 2025-02-08:
So, my amiibopro froze out of nowhere, I actually just bought it.
I have no idea what happened, I was looking for a Mario ammibo to try.
I had already used it a couple of times, and it had worked correctly. I'm waiting for the battery to discharge but I would like to know what happened.
I got stuck on this screen:

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

solosky, 2025-02-10:
You may seek help from seller on how to reset the device.
Some derivative versions of the devices come with built-in Hall sensors. Try placing your device near an iron-containing casing, such as a refrigerator, to see if it works.

grimson73, 2025-06-15:
I just tested 'my' oled derivative and it is rebooting when using a magnet:
Keep magnet close to back of device and then remove magnet -> device should reboot.
Added for anyone that stumbles on this topic.

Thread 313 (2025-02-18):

Upgrade from 2.11.2 to 2.12.0 Fails on LCD Device

ecnepsnai, 2025-02-18:
Hi there! I have a LCD device and I cannot upgrade to the 2.12.0 LCD firmware. After upgrading using the nRF app on my iPhone, the device reboots and backlight turns on but there is nothing on the screen.

**However, I'm sure I have a LCD device** because if I use the 2.11.2 LCD firmware and upload that, it works fine - although it has very poor contrast, hence why I want to update to 2.12.0.

I've tried a few times now and it's always the same outcome, the upgrade seems to work but nothing is shown on the display.

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

MayanKoyote, 2025-02-18:
try to read release notes

ecnepsnai, 2025-02-18:
Oh, I'm sorry - I missed that bit.

> For LCD versions, if the screen appears too faint after updating, you can reset the settings by following these button presses after the device enters standby mode: Middle, Left, Middle, Right (x3), Middle, Right (xN) until the screen becomes clear. Set the contrast to 80.

This resolved my issue. Apologies for the noise!

Closed 2025-02-18.

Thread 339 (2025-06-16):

Feature: Request to Increase Slot Limit in Card Emulator Menu

skylandersNFC, 2025-06-16:
Hi there,

I’m reaching out regarding the current slot limitation in the "Card Emulator" menu.

Allmiibo is evolving into an all-in-one device supporting Skylanders, Disney Infinity, and (soon) LEGO games.
Given this direction, the current limit of 8 slots feels increasingly impractical.

While I’m aware of the plan to eventually move these game types into a dedicated menu, which is a great idea, it’s clear that we’ll still be relying on the existing Card Emulator setup for a while.

Initially, we assumed the 8-slot cap was due to technical constraints.
However, we tested a custom firmware with a 99-slot limit ([link](https://github.com/skylandersNFC/Docs/tree/main/Skylanders_on_Allmiibo/firmware)), and it worked flawlessly. The only trade-off was a few extra seconds during the initial loading process (first initialization of "Card Emulator" menu), which seems acceptable.

Increasing the slot limit doesn’t mean all slots must be enabled at once.
Typically, we enable around 10 slots and leave the rest to be configured as needed.

We applied a similar update to the Flashiibo device with a 50-slot configuration ([Version 59p](https://www.flashiibo.com/manual/pro/firmware)), and again, encountered no issues.

The only minor inconvenience was having to manually delete the **chameleon** folder to force re-initialization from the "Card Emulator" menu. But perhaps there’s a cleaner solution for that too.

With all that in mind, would it be possible to raise the slot limit to better accommodate the growing number of NFC games and dumps?

Thanks!

solosky, 2025-06-16:
Consideration that do not increase slot numbers:
* Increase the response time when any card set as default card, if the response was too long, the default card may not work for some card reader.
* Keep firmware compatible with Chameleon codebase and eco system, for example use BLE connection to manage card slot data.
* The Card Emulator is not designed for emulate lots of card, it designed for emulate cards that will be frequently in daily use, which 8 slots should be enough.

Anyway, indeed there is usecase that needs to emulate more than 8 slots, I think I am ok with increasing the slot number. It's kind easy to increase, but lots of testing work need to do.

Closed 2025-09-09.

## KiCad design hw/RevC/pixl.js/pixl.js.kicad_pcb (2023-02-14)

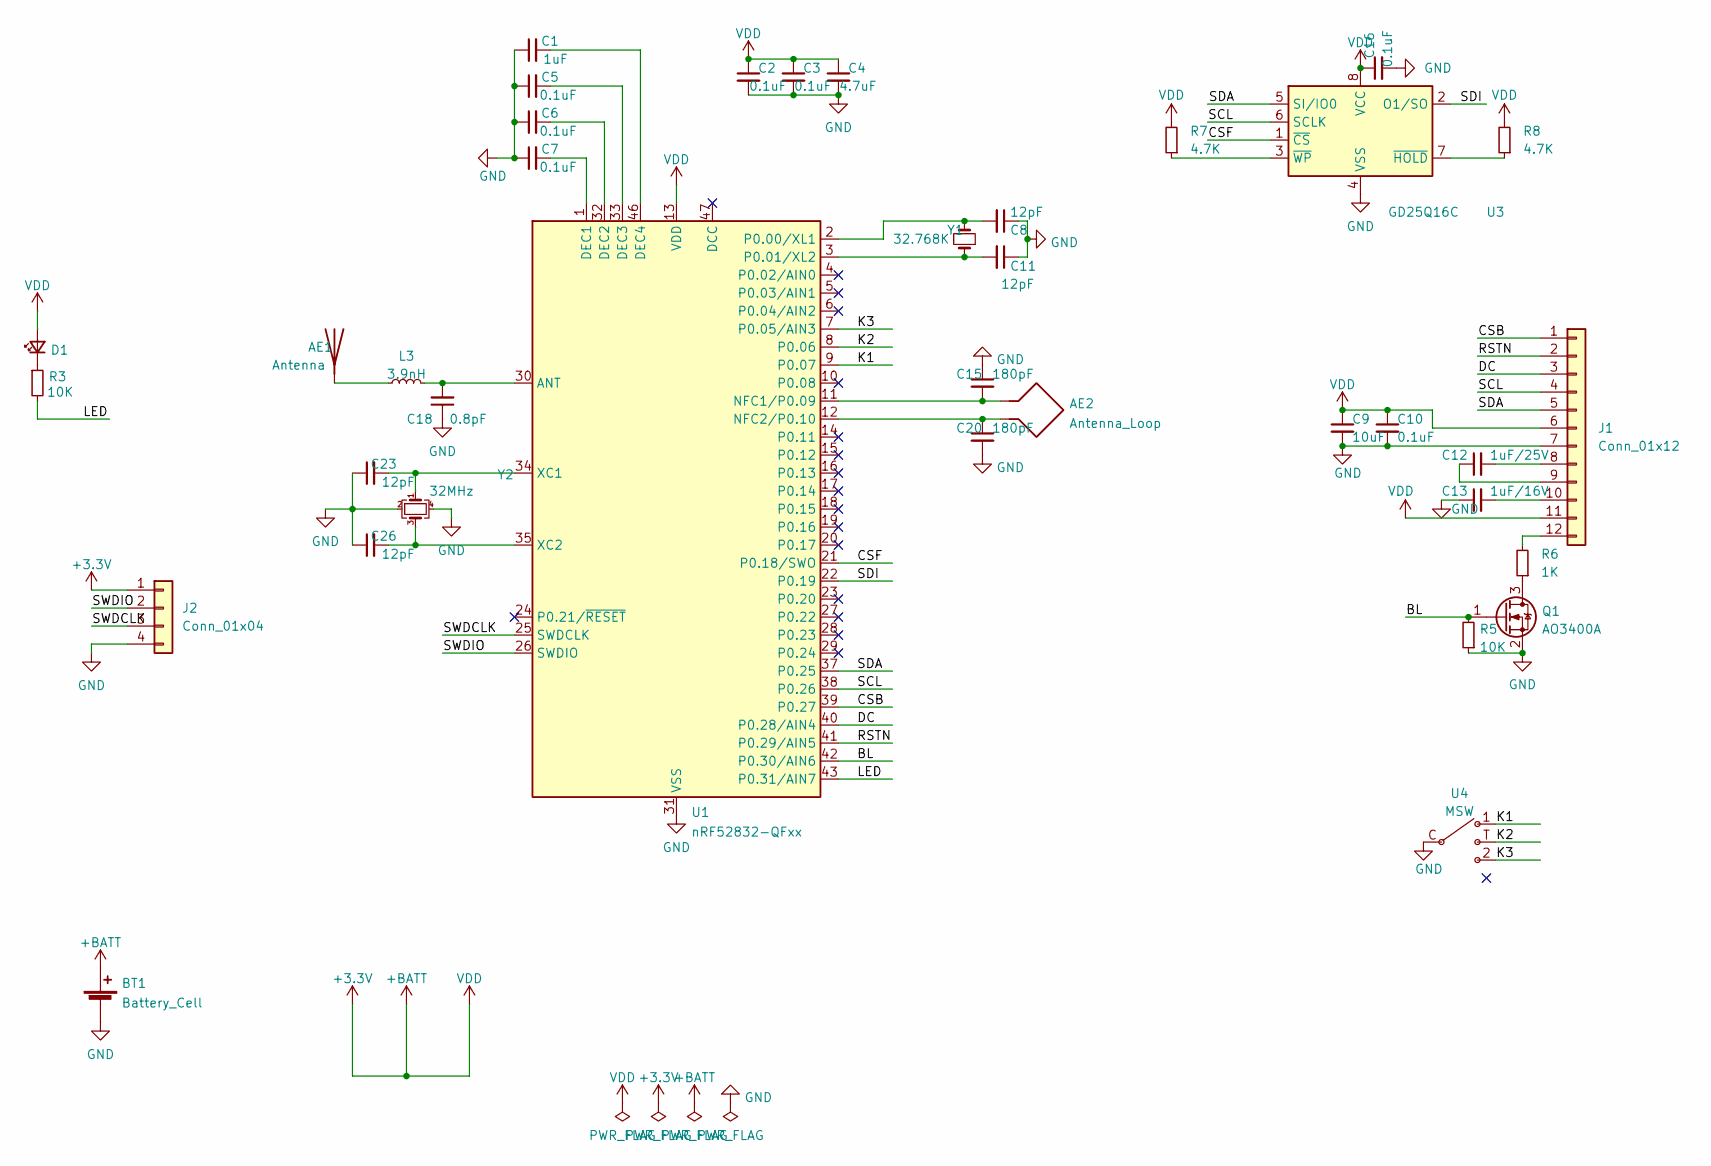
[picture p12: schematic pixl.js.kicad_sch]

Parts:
AE1: Antenna; AN2051
AE2: Antenna_Loop; 40x22MM_NFC_ANTENA
BT1: Battery_Cell; BAT-SMD_CR2032-3V
C1: 1uF; C_0402_1005Metric
C2, C3, C5, C6, C7, C10, C16: 0.1uF; C_0402_1005Metric
C4: 4.7uF; C_0402_1005Metric
C8, C11, C23, C26: 12pF; C_0402_1005Metric
C9: 10uF; C_0402_1005Metric
C12: 1uF/25V; C_0402_1005Metric
C13: 1uF/16V; C_0402_1005Metric
C15, C20: 180pF; C_0402_1005Metric
C18: 0.8pF; C_0402_1005Metric
D1: LED_Small; LED_0402_1005Metric
J1: Conn_01x12; FPC_12 0.8mm
J2: Conn_01x04; JST_GH_SM04B-GHS-TB_1x04-1MP_P1.25mm_Horizontal
L3: 3.9nH; L_0402_1005Metric
Q1: AO3400A; SOT-23
R3, R5: 10K; R_0402_1005Metric
R6: 1K; R_0402_1005Metric
R7, R8: 4.7K; R_0402_1005Metric
U1: nRF52832-QFxx; QFN-48-1EP_6x6mm_P0.4mm_EP4.6x4.6mm
U3: GD25Q16C; USON-8_3x2mm_0.5pich
U4: MSW
Y1: 32.768K; Crystal_SMD_2012-2Pin_2.0x1.2mm
Y2: 32MHz; Crystal_SMD_2016-4Pin_2.0x1.6mm

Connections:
+3V3: BT1.1 (+), C2.1, C3.1, C4.1, C9.1, C10.1, C16.1, D1.2 (A), J1.6, J1.11, J2.1, R7.2, R8.2, U1.13 (VDD), U1.36 (VDD), U1.48 (VDD), U3.8 (VCC)
/BL: Q1.1 (G), R5.2, U1.42 (P0.30/AIN6)
/CSB: J1.1, U1.39 (P0.27)
/CSF: U1.21 (P0.18/SWO), U3.1 (~CS)
/DC: J1.3, U1.40 (P0.28/AIN4)
/K1: U1.9 (P0.07), U4.1
/K2: U1.8 (P0.06), U4.T
/K3: U1.7 (P0.05/AIN3), U4.2
/LED: R3.2, U1.43 (P0.31/AIN7)
/RSTN: J1.2, U1.41 (P0.29/AIN5)
/SCL: J1.4, U1.38 (P0.26), U3.6 (SCLK)
/SDA: J1.5, U1.37 (P0.25), U3.5 (SI/IO0)
/SDI: U1.22 (P0.19), U3.2 (O1/SO)
/SWDCLK: J2.3, U1.25 (SWDCLK)
/SWDIO: J2.2, U1.26 (SWDIO)
GND: BT1.2 (-), C1.1, C2.2, C3.2, C4.2, C5.1, C6.1, C7.1, C8.1, C9.2, C10.2, C11.1, C13.1, C15.1, C16.2, C18.1, C20.2, C23.1, C26.1, J1.7, J2.4, Q1.2 (S), R5.1, U1.31 (VSS), U1.45 (VSS), U1.49 (VSS), U3.4 (VSS), U4.C, Y2.2, Y2.4
unnamed: AE1.1 (A), L3.1
unnamed: AE2.1, C15.2, U1.11 (NFC1/P0.09)
unnamed: AE2.2, C20.1, U1.12 (NFC2/P0.10)
unnamed: C1.2, U1.46 (DEC4)
unnamed: C5.2, U1.33 (DEC3)
unnamed: C6.2, U1.32 (DEC2)
unnamed: C7.2, U1.1 (DEC1)
unnamed: C8.2, U1.2 (P0.00/XL1), Y1.2
unnamed: C11.2, U1.3 (P0.01/XL2), Y1.1
unnamed: C12.1, J1.9
unnamed: C12.2, J1.8
unnamed: C13.2, J1.10
unnamed: C18.2, L3.2, U1.30 (ANT)
unnamed: C23.2, U1.34 (XC1), Y2.1
unnamed: C26.2, U1.35 (XC2), Y2.3
unnamed: D1.1 (K), R3.1
unnamed: J1.12, R6.2
unnamed: Q1.3 (D), R6.1
unnamed: R7.1, U3.3 (~WP)
unnamed: R8.1, U3.7 (~HOLD)

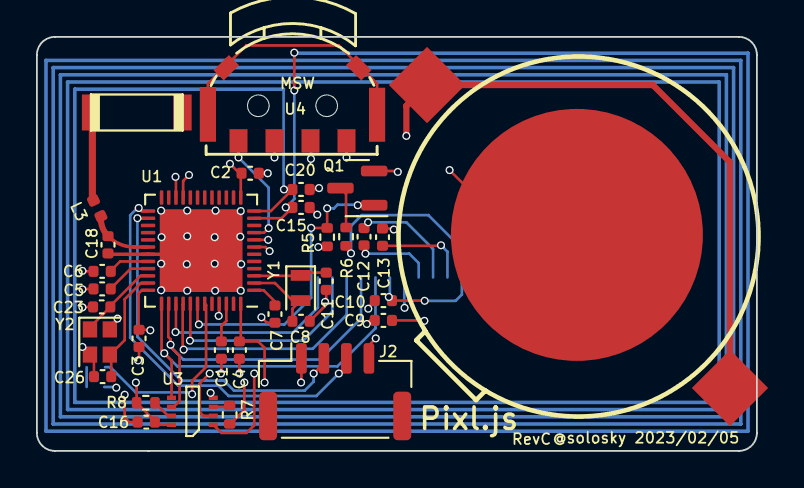
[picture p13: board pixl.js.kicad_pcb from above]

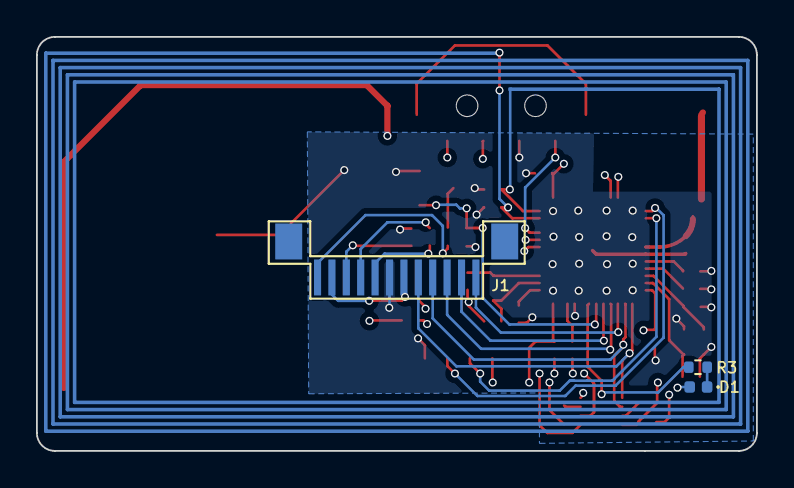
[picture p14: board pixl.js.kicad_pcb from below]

Board: 4 copper layers, 40.0 x 23.0 mm, 37 parts (4 on the bottom side), 36 nets.

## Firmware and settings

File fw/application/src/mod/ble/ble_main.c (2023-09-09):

/**
 * Copyright (c) 2014 - 2020, Nordic Semiconductor ASA
 *
 * All rights reserved.
 *
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
 * 3. Neither the name of Nordic Semiconductor ASA nor the names of its
 *    contributors may be used to endorse or promote products derived from this
 *    software without specific prior written permission.
 *
 * 4. This software, with or without modification, must only be used with a
 *    Nordic Semiconductor ASA integrated circuit.
 *
 * 5. Any software provided in binary form under this license must not be reverse
 *    engineered, decompiled, modified and/or disassembled.
 *
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
 */
/** @file
 *
 * @defgroup ble_sdk_uart_over_ble_main main.c
 * @{
 * @ingroup  ble_sdk_app_nus_eval
 * @brief    UART over BLE application main file.
 *
 * This file contains the source code for a sample application that uses the Nordic UART service.
 * This application uses the @ref srvlib_conn_params module.
 */

#include "app_timer.h"
#include "app_uart.h"
#include "app_util_platform.h"
#include "ble_advdata.h"
#include "ble_advertising.h"
#include "ble_conn_params.h"
#include "ble_hci.h"
#include "ble_nus.h"
#include "bsp_btn_ble.h"
#include "nordic_common.h"
#include "nrf.h"
#include "nrf_ble_gatt.h"
#include "nrf_ble_qwr.h"
#include "nrf_pwr_mgmt.h"
#include "nrf_sdh.h"
#include "nrf_sdh_ble.h"
#include "nrf_sdh_soc.h"
#include <stdint.h>
#include <string.h>

#if defined(UART_PRESENT)
#include "nrf_uart.h"
#endif
#if defined(UARTE_PRESENT)
#include "nrf_uarte.h"
#endif

#include "nrf_log.h"
#include "nrf_log_ctrl.h"
#include "nrf_log_default_backends.h"

#include "ble_amiibolink.h"
#include "ble_df_driver.h"
#include "ble_main.h"
#include "df_core.h"
#include "nrf_pwr_mgmt.h"

#include "app_scheduler.h"

#define APP_BLE_CONN_CFG_TAG 1 /**< A tag identifying the SoftDevice BLE configuration. */

#define NUS_SERVICE_UUID_TYPE                                                                                          \
    BLE_UUID_TYPE_VENDOR_BEGIN /**< UUID type for the Nordic UART Service (vendor specific). */

#define APP_BLE_OBSERVER_PRIO 3 /**< Application's BLE observer priority. You shouldn't need to modify this value. */

#define APP_ADV_INTERVAL 64 /**< The advertising interval (in units of 0.625 ms. This value corresponds to 40 ms). */

#define APP_ADV_DURATION 18000 /**< The advertising duration (180 seconds) in units of 10 milliseconds. */

#define MIN_CONN_INTERVAL                                                                                              \
    MSEC_TO_UNITS(                                                                                                     \
        20,                                                                                                            \
        UNIT_1_25_MS) /**< Minimum acceptable connection interval (20 ms), Connection interval uses 1.25 ms units. */
#define MAX_CONN_INTERVAL                                                                                              \
    MSEC_TO_UNITS(                                                                                                     \
        75,                                                                                                            \
        UNIT_1_25_MS)   /**< Maximum acceptable connection interval (75 ms), Connection interval uses 1.25 ms units. */
#define SLAVE_LATENCY 0 /**< Slave latency. */
#define CONN_SUP_TIMEOUT                                                                                               \
    MSEC_TO_UNITS(                                                                                                     \
        4000, UNIT_10_MS) /**< Connection supervisory timeout (4 seconds), Supervision Timeout uses 10 ms units. */
#define FIRST_CONN_PARAMS_UPDATE_DELAY                                                                                 \
    APP_TIMER_TICKS(5000) /**< Time from initiating event (connect or start of notification) to first time             \
                             sd_ble_gap_conn_param_update is called (5 seconds). */
#define NEXT_CONN_PARAMS_UPDATE_DELAY                                                                                  \
    APP_TIMER_TICKS(                                                                                                   \
        30000) /**< Time between each call to sd_ble_gap_conn_param_update after the first call (30 seconds). */
#define MAX_CONN_PARAMS_UPDATE_COUNT                                                                                   \
    3 /**< Number of attempts before giving up the connection parameter negotiation.                                   \
       */

#define DEAD_BEEF                                                                                                      \
    0xDEADBEEF /**< Value used as error code on stack dump, can be used to identify stack location on stack unwind. */



BLE_NUS_DEF(m_nus, NRF_SDH_BLE_TOTAL_LINK_COUNT); /**< BLE NUS service instance. */
NRF_BLE_GATT_DEF(m_gatt);                         /**< GATT module instance. */
NRF_BLE_QWR_DEF(m_qwr);                           /**< Context for the Queued Write module.*/
BLE_ADVERTISING_DEF(m_advertising);               /**< Advertising module instance. */

static uint16_t m_conn_handle = BLE_CONN_HANDLE_INVALID; /**< Handle of the current connection. */
static uint16_t m_ble_nus_max_data_len =
    BLE_GATT_ATT_MTU_DEFAULT -
    3; /**< Maximum length of data (in bytes) that can be transmitted to the peer by the Nordic UART service module. */
static ble_uuid_t m_adv_uuids[] = /**< Universally unique service identifier. */
    {{BLE_UUID_NUS_SERVICE, NUS_SERVICE_UUID_TYPE}};

static nus_rx_data_handler_t m_nus_rx_data_handler =
    NULL; /**< Event handler to be called for handling received packets. */
static nus_tx_ready_handler_t m_nus_tx_ready_handler =
    NULL; /**< Event handler to be called for handling transmitted packets. */

#define DEVICE_NAME_PIXLJS "Pixl.js"
#define DEVICE_NAME_AMIIBOLINK "amiibolink"
#define DEVICE_NAME_AMILOOP "AmiLoop"

#define DEVICE_NAME DEVICE_NAME_PIXLJS

static ble_gap_addr_t m_default_gap_addr = {0};

static uint8_t m_ble_initialized = false;

#define BLE_CONNECT_SLEEP_TIMEOUT_SECONDS 180 /**< Sleep timeout when ble connection established. */
uint16_t m_previous_pwr_mgmt_sleep_timeout = BLE_CONNECT_SLEEP_TIMEOUT_SECONDS;

/**@brief Function for assert macro callback.
 *
 * @details This function will be called in case of an assert in the SoftDevice.
 *
 * @warning This handler is an example only and does not fit a final product. You need to analyse
 *          how your product is supposed to react in case of Assert.
 * @warning On assert from the SoftDevice, the system can only recover on reset.
 *
 * @param[in] line_num    Line number of the failing ASSERT call.
 * @param[in] p_file_name File name of the failing ASSERT call.
 */
void assert_nrf_callback(uint16_t line_num, const uint8_t *p_file_name) {
    app_error_handler(DEAD_BEEF, line_num, p_file_name);
}

/**@brief Function for initializing the timer module.
 */
static void timers_init(void) {
    ret_code_t err_code = app_timer_init();
    APP_ERROR_CHECK(err_code);
}

/**@brief Function for the GAP initialization.
 *
 * @details This function will set up all the necessary GAP (Generic Access Profile) parameters of
 *          the device. It also sets the permissions and appearance.
 */
static void gap_params_init(void) {
    uint32_t err_code;
    ble_gap_conn_params_t gap_conn_params;
    ble_gap_conn_sec_mode_t sec_mode;

    BLE_GAP_CONN_SEC_MODE_SET_OPEN(&sec_mode);

    err_code = sd_ble_gap_device_name_set(&sec_mode, (const uint8_t *)DEVICE_NAME, strlen(DEVICE_NAME));
    APP_ERROR_CHECK(err_code);

    memset(&gap_conn_params, 0, sizeof(gap_conn_params));

    gap_conn_params.min_conn_interval = MIN_CONN_INTERVAL;
    gap_conn_params.max_conn_interval = MAX_CONN_INTERVAL;
    gap_conn_params.slave_latency = SLAVE_LATENCY;
    gap_conn_params.conn_sup_timeout = CONN_SUP_TIMEOUT;

    err_code = sd_ble_gap_ppcp_set(&gap_conn_params);
    APP_ERROR_CHECK(err_code);

    sd_ble_gap_addr_get(&m_default_gap_addr);
}

/**@brief Function for handling Queued Write Module errors.
 *
 * @details A pointer to this function will be passed to each service which may need to inform the
 *          application about an error.
 *
 * @param[in]   nrf_error   Error code containing information about what went wrong.
 */
static void nrf_qwr_error_handler(uint32_t nrf_error) { APP_ERROR_HANDLER(nrf_error); }

static void nus_event_async_call_rx_data(void *p_event_data, uint16_t event_size) {
    // NRF_LOG_INFO("nus_event_async_call_rx_data: bytes=%d", event_size);
    if (m_nus_rx_data_handler) {
        m_nus_rx_data_handler(p_event_data, event_size);
    }
}

static void nus_event_async_call_tx_ready(void *p_event_data, uint16_t event_size) {
    if (m_nus_tx_ready_handler) {
        m_nus_tx_ready_handler();
    }
}

/**@brief Function for handling the data from the Nordic UART Service.
 *
 * @details This function will process the data received from the Nordic UART BLE Service and send
 *          it to the UART module.
 *
 * @param[in] p_evt       Nordic UART Service event.
 */
/**@snippet [Handling the data received over BLE] */
static void nus_data_handler(ble_nus_evt_t *p_evt) {
    nrf_pwr_mgmt_feed();
    if (p_evt->type == BLE_NUS_EVT_RX_DATA) {
        if (m_nus_rx_data_handler) {
            // app_sched_event_put(p_evt->params.rx_data.p_data, p_evt->params.rx_data.length,
            //                    nus_event_async_call_rx_data);
            nus_event_async_call_rx_data(p_evt->params.rx_data.p_data, p_evt->params.rx_data.length);
        }

    } else if (p_evt->type == BLE_NUS_EVT_TX_RDY) {
        if (m_nus_tx_ready_handler) {
            // app_sched_event_put(NULL, 0, nus_event_async_call_tx_ready);
            nus_event_async_call_tx_ready(NULL, 0);
        }
    }
}

/**@snippet [Handling the data received over BLE] */

/**@brief Function for initializing services that will be used by the application.
 */
static void services_init(void) {
    uint32_t err_code;
    ble_nus_init_t nus_init;
    nrf_ble_qwr_init_t qwr_init = {0};

    // Initialize Queued Write Module.
    qwr_init.error_handler = nrf_qwr_error_handler;

    err_code = nrf_ble_qwr_init(&m_qwr, &qwr_init);
    APP_ERROR_CHECK(err_code);

    // Initialize NUS.
    memset(&nus_init, 0, sizeof(nus_init));

    nus_init.data_handler = nus_data_handler;

    err_code = ble_nus_init(&m_nus, &nus_init);
    APP_ERROR_CHECK(err_code);
}

/**@brief Function for handling an event from the Connection Parameters Module.
 *
 * @details This function will be called for all events in the Connection Parameters Module
 *          which are passed to the application.
 *
 * @note All this function does is to disconnect. This could have been done by simply setting
 *       the disconnect_on_fail config parameter, but instead we use the event handler
 *       mechanism to demonstrate its use.
 *
 * @param[in] p_evt  Event received from the Connection Parameters Module.
 */
static void on_conn_params_evt(ble_conn_params_evt_t *p_evt) {
    uint32_t err_code;

    if (p_evt->evt_type == BLE_CONN_PARAMS_EVT_FAILED) {
        err_code = sd_ble_gap_disconnect(m_conn_handle, BLE_HCI_CONN_INTERVAL_UNACCEPTABLE);
        APP_ERROR_CHECK(err_code);
    }
}

/**@brief Function for handling errors from the Connection Parameters module.
 *
 * @param[in] nrf_error  Error code containing information about what went wrong.
 */
static void conn_params_error_handler(uint32_t nrf_error) { APP_ERROR_HANDLER(nrf_error); }

/**@brief Function for initializing the Connection Parameters module.
 */
static void conn_params_init(void) {
    uint32_t err_code;
    ble_conn_params_init_t cp_init;

    memset(&cp_init, 0, sizeof(cp_init));

    cp_init.p_conn_params = NULL;
    cp_init.first_conn_params_update_delay = FIRST_CONN_PARAMS_UPDATE_DELAY;
    cp_init.next_conn_params_update_delay = NEXT_CONN_PARAMS_UPDATE_DELAY;
    cp_init.max_conn_params_update_count = MAX_CONN_PARAMS_UPDATE_COUNT;
    cp_init.start_on_notify_cccd_handle = BLE_GATT_HANDLE_INVALID;
    cp_init.disconnect_on_fail = false;
    cp_init.evt_handler = on_conn_params_evt;
    cp_init.error_handler = conn_params_error_handler;

    err_code = ble_conn_params_init(&cp_init);
    APP_ERROR_CHECK(err_code);
}

/**@brief Function for handling advertising events.
 *
 * @details This function will be called for advertising events which are passed to the application.
 *
 * @param[in] ble_adv_evt  Advertising event.
 */
static void on_adv_evt(ble_adv_evt_t ble_adv_evt) {
    uint32_t err_code;

    switch (ble_adv_evt) {
    case BLE_ADV_EVT_FAST:
        err_code = bsp_indication_set(BSP_INDICATE_ADVERTISING);
        APP_ERROR_CHECK(err_code);
        break;
    case BLE_ADV_EVT_IDLE:
        bsp_indication_set(BSP_INDICATE_IDLE);
        break;
    default:
        break;
    }
}

/**@brief Function for handling BLE events.
 *
 * @param[in]   p_ble_evt   Bluetooth stack event.
 * @param[in]   p_context   Unused.
 */
static void ble_evt_handler(ble_evt_t const *p_ble_evt, void *p_context) {
    uint32_t err_code;
    char device_name[35];
    uint32_t device_name_len = 35;

    switch (p_ble_evt->header.evt_id) {
    case BLE_GAP_EVT_CONNECTED:
        NRF_LOG_INFO("Connected");
        err_code = bsp_indication_set(BSP_INDICATE_CONNECTED);
        APP_ERROR_CHECK(err_code);
        m_conn_handle = p_ble_evt->evt.gap_evt.conn_handle;
        err_code = nrf_ble_qwr_conn_handle_assign(&m_qwr, m_conn_handle);
        APP_ERROR_CHECK(err_code);

        err_code = sd_ble_gap_device_name_get(device_name, &device_name_len);
        APP_ERROR_CHECK(err_code);

        if (strcmp(device_name, DEVICE_NAME_AMILOOP) == 0) {
            NRF_LOG_INFO("Set mtu to %d", NRF_SDH_BLE_GATT_MAX_MTU_SIZE);
            sd_ble_gattc_exchange_mtu_request(p_ble_evt->evt.gap_evt.conn_handle, NRF_SDH_BLE_GATT_MAX_MTU_SIZE);
        }

        m_previous_pwr_mgmt_sleep_timeout = nrf_pwr_mgmt_get_timeout();
        nrf_pwr_mgmt_set_timeout(BLE_CONNECT_SLEEP_TIMEOUT_SECONDS);

        break;

    case BLE_GAP_EVT_DISCONNECTED:
        NRF_LOG_INFO("Disconnected");
        // LED indication will be changed when advertising starts.
        m_conn_handle = BLE_CONN_HANDLE_INVALID;
        nrf_pwr_mgmt_set_timeout(m_previous_pwr_mgmt_sleep_timeout);

        break;

    case BLE_GAP_EVT_PHY_UPDATE_REQUEST: {
        NRF_LOG_DEBUG("PHY update request.");
        ble_gap_phys_t const phys = {
            .rx_phys = BLE_GAP_PHY_AUTO,
            .tx_phys = BLE_GAP_PHY_AUTO,
        };
        err_code = sd_ble_gap_phy_update(p_ble_evt->evt.gap_evt.conn_handle, &phys);
        APP_ERROR_CHECK(err_code);
    } break;

    case BLE_GAP_EVT_SEC_PARAMS_REQUEST:
        // Pairing not supported
        err_code = sd_ble_gap_sec_params_reply(m_conn_handle, BLE_GAP_SEC_STATUS_PAIRING_NOT_SUPP, NULL, NULL);
        APP_ERROR_CHECK(err_code);
        break;

    case BLE_GATTS_EVT_SYS_ATTR_MISSING:
        // No system attributes have been stored.
        err_code = sd_ble_gatts_sys_attr_set(m_conn_handle, NULL, 0, 0);
        APP_ERROR_CHECK(err_code);
        break;

    case BLE_GATTC_EVT_TIMEOUT:
        // Disconnect on GATT Client timeout event.
        err_code =
            sd_ble_gap_disconnect(p_ble_evt->evt.gattc_evt.conn_handle, BLE_HCI_REMOTE_USER_TERMINATED_CONNECTION);
        APP_ERROR_CHECK(err_code);
        break;

    case BLE_GATTS_EVT_TIMEOUT:
        // Disconnect on GATT Server timeout event.
        err_code =
            sd_ble_gap_disconnect(p_ble_evt->evt.gatts_evt.conn_handle, BLE_HCI_REMOTE_USER_TERMINATED_CONNECTION);
        APP_ERROR_CHECK(err_code);
        break;

    default:
        // No implementation needed.
        break;
    }
}

/**@brief Function for the SoftDevice initialization.
 *
 * @details This function initializes the SoftDevice and the BLE event interrupt.
 */
static void ble_stack_init(void) {
    ret_code_t err_code;

    if (!nrf_sdh_is_enabled()) {
        err_code = nrf_sdh_enable_request();
        APP_ERROR_CHECK(err_code);
    }

    // Configure the BLE stack using the default settings.
    // Fetch the start address of the application RAM.
    uint32_t ram_start = 0;
    err_code = nrf_sdh_ble_default_cfg_set(APP_BLE_CONN_CFG_TAG, &ram_start);
    APP_ERROR_CHECK(err_code);

    // Enable BLE stack.
    err_code = nrf_sdh_ble_enable(&ram_start);
    APP_ERROR_CHECK(err_code);

    // Register a handler for BLE events.
    NRF_SDH_BLE_OBSERVER(m_ble_observer, APP_BLE_OBSERVER_PRIO, ble_evt_handler, NULL);
}

/**@brief Function for handling events from the GATT library. */
void gatt_evt_handler(nrf_ble_gatt_t *p_gatt, nrf_ble_gatt_evt_t const *p_evt) {
    if ((m_conn_handle == p_evt->conn_handle) && (p_evt->evt_id == NRF_BLE_GATT_EVT_ATT_MTU_UPDATED)) {
        m_ble_nus_max_data_len = p_evt->params.att_mtu_effective - OPCODE_LENGTH - HANDLE_LENGTH;
        NRF_LOG_INFO("Data len is set to 0x%X(%d)", m_ble_nus_max_data_len, m_ble_nus_max_data_len);
    }
    NRF_LOG_DEBUG("ATT MTU exchange completed. central 0x%x peripheral 0x%x", p_gatt->att_mtu_desired_central,
                  p_gatt->att_mtu_desired_periph);
}

/**@brief Function for initializing the GATT library. */
void gatt_init(void) {
    ret_code_t err_code;

    err_code = nrf_ble_gatt_init(&m_gatt, gatt_evt_handler);
    APP_ERROR_CHECK(err_code);

    err_code = nrf_ble_gatt_att_mtu_periph_set(&m_gatt, NRF_SDH_BLE_GATT_MAX_MTU_SIZE);
    APP_ERROR_CHECK(err_code);
}

/**@snippet [Handling the data received over UART] */

/**@brief Function for initializing the Advertising functionality.
 */
static void advertising_init(void) {
    uint32_t err_code;
    ble_advertising_init_t init;

    memset(&init, 0, sizeof(init));

    init.advdata.name_type = BLE_ADVDATA_FULL_NAME;
    init.advdata.include_appearance = false;
    init.advdata.flags = BLE_GAP_ADV_FLAGS_LE_ONLY_LIMITED_DISC_MODE;

    init.srdata.uuids_complete.uuid_cnt = sizeof(m_adv_uuids) / sizeof(m_adv_uuids[0]);
    init.srdata.uuids_complete.p_uuids = m_adv_uuids;

    init.config.ble_adv_fast_enabled = true;
    init.config.ble_adv_fast_interval = APP_ADV_INTERVAL;
    init.config.ble_adv_fast_timeout = APP_ADV_DURATION;
    init.evt_handler = on_adv_evt;

    err_code = ble_advertising_init(&m_advertising, &init);
    APP_ERROR_CHECK(err_code);

    ble_advertising_conn_cfg_tag_set(&m_advertising, APP_BLE_CONN_CFG_TAG);
}

/**@brief Function for starting advertising.
 */
static void advertising_start(void) {
    m_advertising.adv_modes_config.ble_adv_on_disconnect_disabled = false;
    uint32_t err_code = ble_advertising_start(&m_advertising, BLE_ADV_MODE_FAST);
    APP_ERROR_CHECK(err_code);
}

/**@brief Application main function.
 */
void ble_init(void) {

    if (!m_ble_initialized) {
        ble_stack_init();
        gap_params_init();
        gatt_init();
        services_init();
        conn_params_init();
        df_core_init();
        m_ble_initialized = true;
    }

    NRF_LOG_INFO("BLE started.");
}

void ble_set_device_name(const char *device_name) {
    ble_gap_conn_sec_mode_t sec_mode;

    BLE_GAP_CONN_SEC_MODE_SET_OPEN(&sec_mode);
    uint32_t err_code = sd_ble_gap_device_name_set(&sec_mode, (const uint8_t *)device_name, strlen(device_name));
    APP_ERROR_CHECK(err_code);
}

void ble_addr_set(uint8_t offset) {
    ble_gap_addr_t addr = {0};
    memcpy(&addr, &m_default_gap_addr, sizeof(ble_gap_addr_t));
    addr.addr[0] += offset;
    uint32_t err_code = sd_ble_gap_addr_set(&addr);
    APP_ERROR_CHECK(err_code);
}

void ble_service_id_set(uint32_t suffix) {
    uint32_t *ptr = m_advertising.p_adv_data->scan_rsp_data.p_data
                    + m_advertising.p_adv_data->scan_rsp_data.len - 4;
    *ptr = suffix;
}

void ble_device_mode_prepare(ble_device_mode_t mode) {
    if (mode == BLE_DEVICE_MODE_AMIIBOLINK || mode == BLE_DEVICE_MODE_AMIIBOLINK_V2) {
        ble_set_device_name(DEVICE_NAME_AMIIBOLINK);
        ble_addr_set(0x10);
    } else if (mode == BLE_DEVICE_MODE_AMILOOP) {
        ble_set_device_name(DEVICE_NAME_AMILOOP);
        ble_addr_set(0x20);
    } else {
        ble_set_device_name(DEVICE_NAME_PIXLJS);
        ble_addr_set(0);
    }
    advertising_init();

    ble_service_id_set(mode == BLE_DEVICE_MODE_AMIIBOLINK_V2 ? 0x0000180F : 0x6e400001);
}

void ble_adv_start(void) {
    if (m_ble_initialized && m_advertising.adv_mode_current == BLE_ADV_MODE_IDLE) {
        advertising_start();
    }
}

void ble_disable() {

    ble_advertising_start(&m_advertising, BLE_ADV_MODE_IDLE);
    sd_ble_gap_adv_stop(m_advertising.adv_handle);
    m_advertising.adv_modes_config.ble_adv_on_disconnect_disabled = true;
    if (m_conn_handle != BLE_CONN_HANDLE_INVALID) {
        sd_ble_gap_disconnect(m_conn_handle, BLE_HCI_REMOTE_USER_TERMINATED_CONNECTION);
    }
}

void ble_nus_set_handler(nus_rx_data_handler_t rx_data_handler, nus_tx_ready_handler_t tx_ready_handler) {
    m_nus_rx_data_handler = rx_data_handler;
    m_nus_tx_ready_handler = tx_ready_handler;
}

ret_code_t ble_nus_tx_data(void *data, size_t length) {
    size_t tx_length = length;
    NRF_LOG_INFO("ble_nus_tx_data: %d bytes", tx_length);
    ret_code_t err_code = ble_nus_data_send(&m_nus, data, &tx_length, m_conn_handle);
    if (err_code) {
        NRF_LOG_INFO("send back error:%d", err_code);
    }
    return err_code;
}

void ble_get_addr_str(char addr_fmt[]) {
    ble_gap_addr_t addr = {0};
    sd_ble_gap_addr_get(&addr);
    sprintf(addr_fmt, "%02X:%02X:%02X:%02X:%02X:%02X", addr.addr[5], addr.addr[4], addr.addr[3], addr.addr[2],
            addr.addr[1], addr.addr[0]);
}

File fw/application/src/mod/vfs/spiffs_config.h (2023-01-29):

/*
 * spiffs_config.h
 *
 *  Created on: Jul 3, 2013
 *      Author: petera
 */

#ifndef SPIFFS_CONFIG_H_
#define SPIFFS_CONFIG_H_

// ----------- 8< ------------
// Following includes are for the linux test build of spiffs
// These may/should/must be removed/altered/replaced in your target
//#include "params_test.h"
#include <stdio.h>
#include <stdlib.h>
#include <string.h>
#include <stddef.h>
#include <unistd.h>
#ifdef _SPIFFS_TEST
#include "testrunner.h"
#endif

typedef int32_t s32_t;
typedef uint32_t u32_t;
typedef int16_t s16_t;
typedef uint16_t u16_t;
typedef int8_t s8_t;
typedef uint8_t u8_t;

// ----------- >8 ------------

// compile time switches

// Set generic spiffs debug output call.
#ifndef SPIFFS_DBG
#define SPIFFS_DBG(_f, ...) //printf(_f, ## __VA_ARGS__)
#endif
// Set spiffs debug output call for garbage collecting.
#ifndef SPIFFS_GC_DBG
#define SPIFFS_GC_DBG(_f, ...) //printf(_f, ## __VA_ARGS__)
#endif
// Set spiffs debug output call for caching.
#ifndef SPIFFS_CACHE_DBG
#define SPIFFS_CACHE_DBG(_f, ...) //printf(_f, ## __VA_ARGS__)
#endif
// Set spiffs debug output call for system consistency checks.
#ifndef SPIFFS_CHECK_DBG
#define SPIFFS_CHECK_DBG(_f, ...) //printf(_f, ## __VA_ARGS__)
#endif
// Set spiffs debug output call for all api invocations.
#ifndef SPIFFS_API_DBG
#define SPIFFS_API_DBG(_f, ...) //printf(_f, ## __VA_ARGS__)
#endif



// Defines spiffs debug print formatters
// some general signed number
#ifndef _SPIPRIi
#define _SPIPRIi   "%d"
#endif
// address
#ifndef _SPIPRIad
#define _SPIPRIad  "%08x"
#endif
// block
#ifndef _SPIPRIbl
#define _SPIPRIbl  "%04x"
#endif
// page
#ifndef _SPIPRIpg
#define _SPIPRIpg  "%04x"
#endif
// span index
#ifndef _SPIPRIsp
#define _SPIPRIsp  "%04x"
#endif
// file descriptor
#ifndef _SPIPRIfd
#define _SPIPRIfd  "%d"
#endif
// file object id
#ifndef _SPIPRIid
#define _SPIPRIid  "%04x"
#endif
// file flags
#ifndef _SPIPRIfl
#define _SPIPRIfl  "%02x"
#endif


// Enable/disable API functions to determine exact number of bytes
// for filedescriptor and cache buffers. Once decided for a configuration,
// this can be disabled to reduce flash.
#ifndef SPIFFS_BUFFER_HELP
#define SPIFFS_BUFFER_HELP              0
#endif

// Enables/disable memory read caching of nucleus file system operations.
// If enabled, memory area must be provided for cache in SPIFFS_mount.
#ifndef  SPIFFS_CACHE
#define SPIFFS_CACHE                    1
#endif
#if SPIFFS_CACHE
// Enables memory write caching for file descriptors in hydrogen
#ifndef  SPIFFS_CACHE_WR
#define SPIFFS_CACHE_WR                 1
#endif

// Enable/disable statistics on caching. Debug/test purpose only.
#ifndef  SPIFFS_CACHE_STATS
#define SPIFFS_CACHE_STATS              1
#endif
#endif

// Always check header of each accessed page to ensure consistent state.
// If enabled it will increase number of reads, will increase flash.
#ifndef SPIFFS_PAGE_CHECK
#define SPIFFS_PAGE_CHECK               1
#endif

// Define maximum number of gc runs to perform to reach desired free pages.
#ifndef SPIFFS_GC_MAX_RUNS
#define SPIFFS_GC_MAX_RUNS              5
#endif

// Enable/disable statistics on gc. Debug/test purpose only.
#ifndef SPIFFS_GC_STATS
#define SPIFFS_GC_STATS                 1
#endif

// Garbage collecting examines all pages in a block which and sums up
// to a block score. Deleted pages normally gives positive score and
// used pages normally gives a negative score (as these must be moved).
// To have a fair wear-leveling, the erase age is also included in score,
// whose factor normally is the most positive.
// The larger the score, the more likely it is that the block will
// picked for garbage collection.

// Garbage collecting heuristics - weight used for deleted pages.
#ifndef SPIFFS_GC_HEUR_W_DELET
#define SPIFFS_GC_HEUR_W_DELET          (5)
#endif
// Garbage collecting heuristics - weight used for used pages.
#ifndef SPIFFS_GC_HEUR_W_USED
#define SPIFFS_GC_HEUR_W_USED           (-1)
#endif
// Garbage collecting heuristics - weight used for time between
// last erased and erase of this block.
#ifndef SPIFFS_GC_HEUR_W_ERASE_AGE
#define SPIFFS_GC_HEUR_W_ERASE_AGE      (50)
#endif

// Object name maximum length. Note that this length include the
// zero-termination character, meaning maximum string of characters
// can at most be SPIFFS_OBJ_NAME_LEN - 1.
#ifndef SPIFFS_OBJ_NAME_LEN
#define SPIFFS_OBJ_NAME_LEN             (64)
#endif

// Maximum length of the metadata associated with an object.
// Setting to non-zero value enables metadata-related API but also
// changes the on-disk format, so the change is not backward-compatible.
//
// Do note: the meta length must never exceed
// logical_page_size - (SPIFFS_OBJ_NAME_LEN + 64)
//
// This is derived from following:
// logical_page_size - (SPIFFS_OBJ_NAME_LEN + sizeof(spiffs_page_header) +
// spiffs_object_ix_header fields + at least some LUT entries)
#ifndef SPIFFS_OBJ_META_LEN
#define SPIFFS_OBJ_META_LEN             (128)
#endif
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

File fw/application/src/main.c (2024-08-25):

/**
 * Copyright (c) 2017 - 2020, Nordic Semiconductor ASA
 *
 * All rights reserved.
 *
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
 * 3. Neither the name of Nordic Semiconductor ASA nor the names of its
 *    contributors may be used to endorse or promote products derived from this
 *    software without specific prior written permission.
 *
 * 4. This software, with or without modification, must only be used with a
 *    Nordic Semiconductor ASA integrated circuit.
 *
 * 5. Any software provided in binary form under this license must not be reverse
 *    engineered, decompiled, modified and/or disassembled.
 *
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
 */

/** @file
 *
 * @defgroup nfc_writable_ndef_msg_example_main main.c
 * @{
 * @ingroup nfc_writable_ndef_msg_example
 * @brief The application main file of NFC writable NDEF message example.
 *
 */

#include "app_error.h"
#include "app_scheduler.h"
#include "boards.h"
#include "nfc_ndef_msg.h"
#include "nfc_t4t_lib.h"
#include "nordic_common.h"
#include "nrf_error.h"
#include "nrf_log_ctrl.h"
#include <stdbool.h>
#include <stdint.h>

#include "app_button.h"
#include "app_timer.h"
#include "bsp.h"
#include "bsp_nfc.h"
#include "nrf_delay.h"
#include "nrf_drv_clock.h"
#include "nrf_gpio.h"
#include "nrf_log.h"
#include "nrf_log_ctrl.h"
#include "nrf_log_default_backends.h"
#include "nrf_power.h"

#include "ntag_emu.h"

#include "ntag_store.h"

#include "bat.h"
#include "ble_main.h"

#include "nrf_sdh.h"

#include "mem_manager.h"
#include "nrf_crypto.h"

#include "nrf_pwr_mgmt.h"

#include "amiibo_helper.h"

#include "mini_app_launcher.h"
#include "mui_include.h"

#include "hal_spi_bus.h"
#include "hal_spi_flash.h"

#include "tag_helper.h"

#include "cache.h"
#include "i18n/language.h"
#include "settings.h"

#define APP_SCHED_MAX_EVENT_SIZE 4 /**< Maximum size of scheduler events. */
#define APP_SCHED_QUEUE_SIZE 16    /**< Maximum number of events in the scheduler queue. */

#define BTN_ID_SLEEP 1 /**< ID of button used to put the application into sleep mode. */
#define BTN_ACTION_KEY1_LONGPUSH BSP_EVENT_KEY_LAST + 9

#define APP_SHUTDOWN_HANDLER_PRIORITY 1

int8_t g_usb_led_marquee_enable = 0; /** dummy for chameleon */

// #define SPI_FLASH

/**
 *@brief Function for initializing logging.
 */
static void log_init(void) {
    ret_code_t err_code = NRF_LOG_INIT(NULL);
    APP_ERROR_CHECK(err_code);

    NRF_LOG_DEFAULT_BACKENDS_INIT();
}

void bsp_evt_execute(void *p_event_data, uint16_t event_size) {

    bsp_event_t *evt_p = (bsp_event_t *)p_event_data;
    bsp_event_t evt = *evt_p;
    NRF_LOG_DEBUG("bsp event: %d\n", evt);
    // mui_input_on_bsp_event(evt);

    switch (evt) {
    case BSP_EVENT_KEY_0:
    case BSP_EVENT_KEY_1:
    case BSP_EVENT_KEY_2:
    case BTN_ACTION_KEY1_LONGPUSH:
        nrf_pwr_mgmt_feed();
        break;
    default:
        break;
    }
}

void bsp_evt_handler(bsp_event_t evt) { app_sched_event_put(&evt, sizeof(evt), bsp_evt_execute); }

/**
 * @brief Function for shutdown events.
 *
 * @param[in]   event       Shutdown type.
 */
static bool shutdown_handler(nrf_pwr_mgmt_evt_t event) {
    ret_code_t err_code;

    switch (event) {
    case NRF_PWR_MGMT_EVT_PREPARE_WAKEUP:

        NRF_LOG_DEBUG("go sleep");

        mini_app_launcher_sleep(mini_app_launcher());

        // save ntag to cache
        cache_data_t *p_cache_data = cache_get_data();
        memcpy(&p_cache_data->ntag, ntag_emu_get_current_tag(), sizeof(ntag_t));

        cache_save();

        mui_deinit(mui());

        // save settings
        settings_save();

        hal_spi_flash_sleep();

        err_code = bsp_wakeup_button_enable(BTN_ID_SLEEP);
        APP_ERROR_CHECK(err_code);

        // Set up NFCT peripheral as the only wakeup source.
        err_code = bsp_nfc_sleep_mode_prepare();
        APP_ERROR_CHECK(err_code);

        // Turn off LED to indicate that the device entered System OFF mode.
        bsp_board_leds_off();

        break;

    default:
        break;
    }

    return true;
}

NRF_PWR_MGMT_HANDLER_REGISTER(shutdown_handler, APP_SHUTDOWN_HANDLER_PRIORITY);

/**
 *@brief :检测唤醒源
 */
static uint32_t check_wakeup_src(void) {
    uint32_t rr = nrf_power_resetreas_get();
    NRF_LOG_INFO("nrf_power_resetreas_get: 0x%04x", rr);

    // 如果卡模拟器设置了默认卡，这里就不开启模拟NTAG
    if (tag_helper_valid_default_slot() && (rr & NRF_POWER_RESETREAS_NFC_MASK)) {
        tag_emulation_init();
        hal_nfc_set_nrfx_irq_enable(true);
        tag_emulation_sense_run();
    } else {

        extern const ntag_t default_ntag215;
        ret_code_t err_code = ntag_emu_init(&default_ntag215);
        APP_ERROR_CHECK(err_code);

        if (cache_valid()) {
            cache_data_t *p_cache = cache_get_data();
            ntag_emu_set_tag(&(p_cache->ntag));
        } else {
            cache_clean();
        }
    }

    if (rr == 0) {
        NRF_LOG_INFO("WeakUp from button")
        // p_cache->enabled = 0;
    } else if (rr & (NRF_POWER_RESETREAS_NFC_MASK | NRF_POWER_RESETREAS_LPCOMP_MASK)) {
        NRF_LOG_INFO("WakeUp from rfid field");
    } else {
        NRF_LOG_INFO("First power system");
    }
    nrf_power_resetreas_clear(nrf_power_resetreas_get());

    return rr;
}
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

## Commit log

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2022-11-06 修复fds gc
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2022-11-09 临时修复tagmo写入的失败的标签，写入失败也能用
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2023-02-04 fixed remove directory bug
    [vfs_driver_spiffs.c]
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2023-03-18 1. reset when hardfault or exit 2. settings.bin add hidden attr when created 3. mui mem change from 16k to 24k 4. check path length before rename folder 5. disable assert for release
    [vfs_driver_spiffs.c]
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2023-04-16 Fix amiibolink mode select not display back button
2023-04-16 Fix home button
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2023-05-06 fix bug for hibernate mode
    [main.c]
2023-05-07 fix ram retention
    [amiibo_data.csv]
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2023-05-10 Fix lfs hidden file not hidden
    [vfs_driver_lfs.c]
2023-05-10 fixed Github Actions compile error
    [sdk_config.h]
2023-05-12 add new amiibo: zelda - tears of Kingdom
    [amiibo_data.csv]
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2023-05-14 fix compile error of Github Actions.
    [sdk_config.h]
2023-05-30 Fix android AmiLoop error
    [ble_main.c]
2023-05-30 1. fix desktop launch app with wrong id 2.increment ble address when setup as a amiloop device
    [ble_main.c]
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2023-08-07 update Amiibo database. Found new amiibo: [22410000,041e0002] Super Smash Bros./Pyra Found new amiibo: [22420000,041f0002] Super Smash Bros./Mythra Found 841 amiibo records.
    [amiibo_data.csv]
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2023-08-22 fix amiibo id
    [amiidb_amiibo.csv, amiidb_link.csv]
2023-08-22 fix game name
    [amiidb_game.csv]
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2023-08-23 fix english game names and remove old amiibo data
    [amiibo_data.csv, amiidb_amiibo.csv, amiidb_game.csv]
2023-08-23 revert board defines
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2023-08-30 add english note for The Legend of Zelda
    [amiidb_game.csv, amiidb_link.csv]
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2023-09-05 修复两处译名问题&将未命名排序于最下方
    [amiidb_amiibo.csv, amiidb_game.csv]
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2023-09-06 change sleep timeout to 180s when ble connected fixed #83
    [ble_main.c]
2023-09-07 add debug make file configuration and fixed #90
    [main.c]
2023-09-07 mute compiler errors batch #1
    [bat.c, ble_main.c]
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2023-10-30 Corrected build instructions; 跟新了编译文档
    Corrected build instructions, corrected a few minor mistakes.
    跟新了编译文档，之前的指令有一些小错误。
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2023-11-08 Fix issue for Jikkyou Powerful Pro Baseball https://github.com/N3evin/AmiiboAPI/pull/140
    [amiidb_amiibo.csv]
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2023-11-18 1. add script to generate i18n source and headers 2. add batch create empty menu
    [i18n.csv]
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2023-11-25 add reset default config in settings
    [i18n.csv]
2023-11-25 fix cannot boot if flash mount error
2023-12-02 fixed #161: apply setting after reset setting
    [i18n.csv]
2023-12-03 Spanish Globalization
    # Update settings_scene_language.c
    * If you change or add language definitions you also need to edit this file.
    * Change of settings_scene_language.c replacing es_CO by es_ES
    * This change is needed but is not mentioned on 05translation.md
    # Rename the language to Spanish.
    On files es_ES.c, language.c & language.h
    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
    [i18n.csv]
2023-12-03 fix #169 add chinese charaters:瓜瓶电梯控
2023-12-05 Add Magyar (Hungarian) Language
    Add Magyar (Hungarian) Language
    [i18n.csv]
2023-12-18 Add Several New Languages
    Thanks to Ender519 (Discord) add
    German (Deutsch)
    French (Français)
    Dutch (Nederlands)
    Portuguese - Brazil (Português)
    Japanese (日本語)
    [i18n.csv]
2023-12-28 Update settings.c: Update settings.c: Default battery mode now depends on whether the screen is OLED.
    Though OLED doesn't necessarily imply rechargeable battery, it's usually the case, hence the change.
2024-01-08 Adding Português(Portugal)
    Add Português(Portugal) as a new language
    Thanks to https://github.com/nmra1999 on Issue: https://github.com/solosky/pixl.js/issues/147
    [i18n.csv]
2024-01-10 Deutsch Typo correction
    Thanks to https://github.com/Ulfenknulfen
    Small Typo on de_DE
    [i18n.csv]
2024-01-11 fixed #194: put language string into text area to reduce mem footprint
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2024-01-20 fix anim last frame
2024-01-22 - use filename as slot's nickname by default
    - shorten nickname to fit ui
2024-01-22 - correct position of ">" in card emulators slot selection
2024-01-22 fixed #207, show confirm box when reset settings
    [i18n.csv]
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2024-01-24 - add uint16_t mui_canvas_draw_utf8_truncate(mui_canvas_t* p_canvas, uint8_t x, uint8_t y, uint8_t max_width, const char *str);
    [i18n.csv]
2024-01-24 - update german translation to fit ui layout
    [i18n.csv]
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2024-01-24 - replace internationalized ellipsis with glyph from u8g2_font_siji_t_6x10
    [i18n.csv]
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2024-03-04 fixed #219, check file name restriction before create file
    [vfs_driver_spiffs.c]
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2024-04-01 tradotti dettagli effetti amiibo su botw e totk
    [amiidb_link.csv, i18n.csv]
2024-04-02 added support for italian note on amiidb, added comment on auto-generated file
    [amiidb_amiibo.csv, amiidb_link.csv]
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2024-04-05 Minor line-break fix
    [i18n.csv]
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2024-04-09 Add zh_Hans and zh_TW, Fix French _L_KNOW
    [i18n.csv]
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2024-04-14 replacing _L_ON/OFF with _L_ON_F/OFF_F
    where it makes sense. And fixing the translation of the lines “freed” by this in order to more elegantly display what they are left to display now.
    [i18n.csv]
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2024-08-12 Changes related to commit 877a835
    Russian localization update related to commit 877a835.
    [i18n.csv]
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2024-08-23 Changes related to commits 5d4cc1e and 936ef88
    Russian localization update related to commit 5d4cc1e.
    Russian localization update related to commit 936ef88.
    [i18n.csv]
2024-08-25 fix card emulator default card
    [main.c]
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2024-09-25 fixed #273: Fix Splatoon 3 Alterna and Side Order
    [amiidb_amiibo.csv, amiidb_link.csv]
2024-09-26 Fixed #281: Add Go Sleep menu in settings
    [i18n.csv]
2024-10-14 uploading correct i18n.csv
    replacing the file with the correct one
    [i18n.csv]
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2024-10-16 Add default interrupt handler to reset device
    [rtt.cfg]
2024-11-17 Use -DBOARD_CUSTOM instead of -DCUSTOM_BOARD_INC=boards_defines. This allows a more standard #include "boards.h" and in turn allows vscode to understand all the pin definitions. Now, one can hover th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
    [hal_spi_bus.c, vfs_driver_lfs.c, vfs_driver_spiffs.c]
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2024-11-20 Changes related to commit 9a6c75e
    Russian localization update related to commit 9a6c75e.
    [i18n.csv]
2025-01-18 Add amiibo series: Super Nintendo World Add new amiibo: Found new amiibo: [000900030432ff02] Diddy Kong - Power Up Band Found new amiibo: [000800030431ff02] Donkey Kong - Power Up Band
    [amiidb_amiibo.csv, amiidb_game.csv, amiidb_link.csv]
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2025-01-18 OLED remove for ES and RU
    On latest commit ES and RU language files kept a removed OLED reference.
    [i18n.csv]
2025-01-20 Addition of new language values
    Some values where missed on ES translation, here are the missing values.
    [i18n.csv]
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2025-02-24 correction of sequence of translations
    restoration of the historical sequence of appearance/addition of translations, see issue #315
    [i18n.csv]
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2025-06-07 feat(chameleon): add UID size selection functionality
    - Add new scene for selecting UID size
    - Update existing scenes to support different UID sizes
    - Modify tag helper functions to handle UID size
    - Add translations for new UID size related strings
    [i18n.csv]
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2025-06-08 "fix(chameleon): 修正 MIFLARE 组名拼写错误为 MIFARE"
2025-06-09 Changes related to commit 88b62d5
    Russian localization update related to commit 88b62d5.
    [i18n.csv]
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2025-06-14 feat(chameleon): load data file supports browser sub directory, Fixed #331
    [i18n.csv]
2025-06-14 Changes related to commit f25fd35
    Russian localization update related to commit f25fd35.
    [i18n.csv]
2025-06-14 Changes related to commit a905509
    Russian localization update related to commit a905509.
    [i18n.csv]
2025-06-14 Replacing unnoticed _L_ON/OFF with _L_ON_F/OFF_F
    Replacement of previously unnoticed manually bracketed _L_ON/OFF with special initially bracketed _L_ON_F/OFF_F, see PR #250
2025-06-15 Remove _L_OPEN_DIR_FAILED, use _L_OPEN_FOLDER_FAILED instead. Fixed #331
    [i18n.csv]
2025-06-15 Workaround for issue #336
    Minor Russian translation fix.
    [i18n.csv]
2025-06-15 Minor Russian translation fix.
    Yofication fix.
    [i18n.csv]
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2025-08-16 add app management menu, app could be disabled or enabled in the desktop #334
    [i18n.csv]
2025-08-18 fix: amiibolink button event trigger multiple times
    amiibolink app,进入主菜单时按确认键会触发多次, 表现为在标签主页面按确认会连续进入主菜单页面和模式切换界面.
2025-08-21 Changes related to commit c0e90f8
    Russian localization update related to commit c0e90f8.
    [i18n.csv]
2025-09-03 feat: add game list sorting by name and default order in amiidb #344
    [i18n.csv]
2025-09-04 update Russian translation (for commit 72b9c90)
    Changes related to commit 72b9c90 have been made.
    [i18n.csv]
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2025-09-07 fix: reset default slot index when it exceeds available slot number
2025-11-14 feat(amiibo): add new amiibo entries and game series support
    add game series field to amiibo class and include new amiibo entries
    update game database with new amiibo counts for Mario Kart, Metroid, and Street Fighter
    [amiidb_amiibo.csv, amiidb_link.csv]
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2025-12-08 updated fw/data/amiidb_amiibo.csv, which the pytyon script uses to generate the .c file.
    [amiidb_amiibo.csv]
2025-12-08 Revert "updated fw/data/amiidb_amiibo.csv, which the pytyon script uses to generate the .c file."
    This reverts commit 8ac57db4736dca4c73c3b66887bfea78f30cc0a2.
    [amiidb_amiibo.csv]
2025-12-21 feat(amiibo): add v3 amiibo support and refactor display logic
    - Add new v3 amiibo database and validation checks
    - Implement v3 amiibo generation with proper NTAG_I2C_PLUS_2K format
    - Refactor amiibo display name logic into helper function
    - Update all scenes to use new display name function
    - Add CRC16-MCRF4XX checksum calculation for v3 support
    [amiidb_v3.csv]
2025-12-23 fix reading v3 amiibos on switch 1 with joy con 1
2025-12-24 feat(data): add Kirby Air Riders game and amiibo links
    Add new game entry for Kirby Air Riders in amiidb_game.csv and corresponding amiibo links in amiidb_link.csv
    [amiidb_game.csv, amiidb_link.csv]
2025-12-24 refactor(amiidb): remove v3 amiibo support and update game db
    - Remove v3 amiibo CSV file and related code
    - Simplify v3 validation check to tail byte comparison
    - Update game database with new entries
    - Remove unused v3 references from header and build files
    [amiidb_v3.csv]
2026-01-01 feat(amiidb): add v3 amiibo unsupported warning and update game flags
    Add support for displaying a warning message when users attempt to access v3 amiibo which are not currently supported. Also update game flags for Detective Pikachu and Hey! Pikmin to indicate they are now supported.
    Add new string ID _L_APP_AMIIDB_NOT_SUPPORT_V3 for the warning message and implement the check in the game list scene. Update the amiibo database generation script with better error handling and timeout.
    [amiidb_game.csv, i18n.csv]
2026-01-10 update Russian translation (for commit 26b4754)
    Changes related to commit 26b4754 have been made.
    [i18n.csv]
